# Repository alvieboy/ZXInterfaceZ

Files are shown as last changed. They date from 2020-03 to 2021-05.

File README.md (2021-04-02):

# ZX Interface Z



Interface Z - an expansion card for the ZX Spectrum which supports

- VGA Output
- USB devices such as joysticks, flash drives and keyboards
- Networking and Wifi
- Micro SD Card
- YM2149 audio

_Project status: Currently under development and only suitable for people that want
to help out with development and testing._

Current version is _ALPHA1_.

See [FEATURES](docs/FEATURES.md) for more details on the _ZX Interface Z_ features.
[(click here for PDF document)](docs/FEATURES.md.pdf)

# Overview

Block diagram of Interface Z [diagram](https://raw.githubusercontent.com/alvieboy/ZXInterfaceZ/master/docs/overview2.png)

# Models supported

The following models are supported:

- ZX Spectrum 16K
- ZX Spectrum 48K
- ZX Spectrum 128K (gray)
- ZX Spectrum 128K (toastrack)
- ZX Spectrum +2A
- ZX Spectrum +3

## Hardware
This section refers to the schematics and printed circuit board design of the Interface Z.
The digital design on the FPGA is described in the [FPGA design] section.
### Licensing
Schematics and PCB are released under [CC-BY-SA 2.0](https://creativecommons.org/licenses/by-sa/2.0/). This applies to all versions of the schematics and PCBs.
### Version
Current hardware version is 2.4. This is a pre-production version, not intented for general public availability.

## FPGA design
The FPGA design is written primarly in VHDL, targeting an Altera/Intel Cyclone IV device (EP4CE6E22C8N). There is no flash to store bitfile contents - the FPGA bitfile is loaded by the ESP32 MCU and stored inside the ESP32 flash.

### Licensing
Unless otherwise stated in each HDL or design support file, the FPGA design files are released under [BSD 3-Clause License](https://opensource.org/licenses/BSD-3-Clause).

## Firmware
This section applies to the firmware running on the ESP32 MCU.
### Licensing
Unless otherwise stated in each source support file, the firmware source files are released under [GPL version 3](https://opensource.org/licenses/GPL-3.0) license.

## Software
This section applies to the software intended to run on a separate computer (such as a PC, Mac or other).
### Licensing
Unless otherwise stated in each source support file, the software source files are released under [GPL version 3](https://opensource.org/licenses/GPL-3.0) license.

# Developing

See [DEVELOPING](docs/DEVELOPING.md) for development information regarding _ZX Interface Z_ 
[(click here for PDF document)](docs/DEVELOPING.md.pdf)

See [USER GUIDE](docs/USER_GUIDE.md) for build instructions.

# More information

- Follow the project on [Facebook - ZX Interface Z](https://www.facebook.com/zxinterfacez)
- Watch a [Demo of "Interface Z" for ZX Spectrum](https://www.youtube.com/watch?v=lMPc_8UKx1o) on YouTube

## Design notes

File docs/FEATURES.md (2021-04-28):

# What is ZX Interface Z?

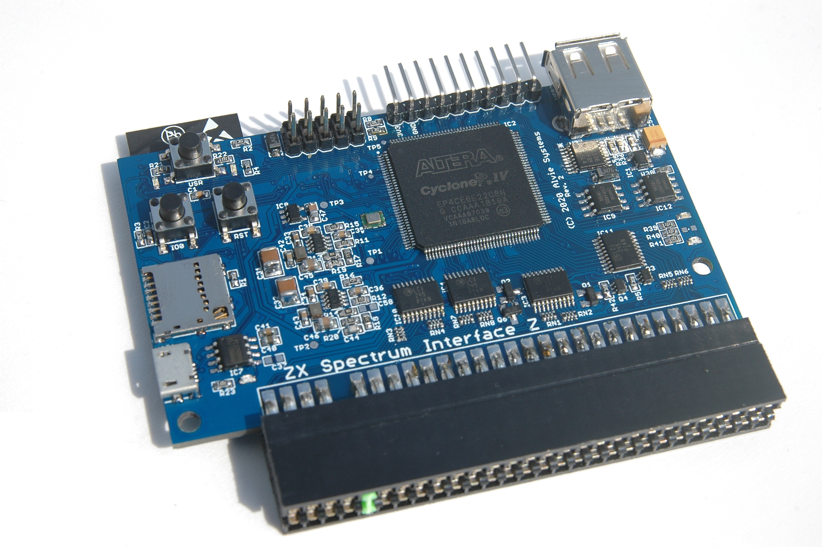
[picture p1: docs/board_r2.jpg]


The _ZX Interface Z_ is an expansion card for the ZX Spectrum which supports, among
other features:

- VGA and audio output via micro expansion card
- USB devices, such as keyboard, gamepads and memory sticks.
- Network access via WiFi
- Micro SD card
- Bluetooth [planned]
- YM2149 sound on all models

Internally, the _ZX Interface Z_ includes:

- A dual-core CPU with WiFi and Bluetooth radio
- An Intel FPGA                                
- 64MB of RAM, also accessible from the ZX Spectrum
- USB for debugging and programming

the _ZX Interface Z_ is __fully open source!__. The software, the board and the FPGA designs are
available online under open source licences so anyone can modify them or build
their own.

## Current version
The current hardware version is 2.4. This hardware is compatible with the
models described in this document.

## Where is the source?

All sources are available in github:

[https://github.com/alvieboy/ZXInterfaceZ](https://github.com/alvieboy/ZXInterfaceZ)

## Supported hardware
The following ZX Spectrum hardware is supported:

- ZX Spectrum 16K
- ZX Spectrum 48K
- ZX Spectrum 128K (gray)
- ZX Spectrum 128K (toastrack)
- ZX Spectrum +2A
- ZX Spectrum +3

Some features might not be available depending on the model. See section 
Hardware Limitations for details regarding support of your ZX Spectrum model.

# The board
The _ZX Interface Z_ board has the following features available for user
interaction and information:

- Two user buttons - USR and IO0
- 6 LEDs (one for power, 5 for information)
- One hard-reset button

The _ZX Interface Z_ also includes one expansion port which can hold other 
boards. The VGA and audio output plug into this expansion port.

The USR button is used to access the _ZX Interface Z_ main menu. The IO0 button
is configurable and can be used for different purposes.

By default, holding the IO0 button for more than one second loads a Diagnostics ROM
which you can use to diagnose your ZX Spectrum hardware.

# Main menu
The main menu is normally accessible by pressing shortly the USR button. Most of 
the _ZX Interface Z_ functionality is accessible using this menu.

From the main menu, you can:

- Load snapshots
- Save snapshots
- Play tapes
- Poke memory
- Change _ZX Interface Z_ settings
- Reset the ZX Spectrum
- Debug the ZX Spectrum [experimental]
- See information about the system

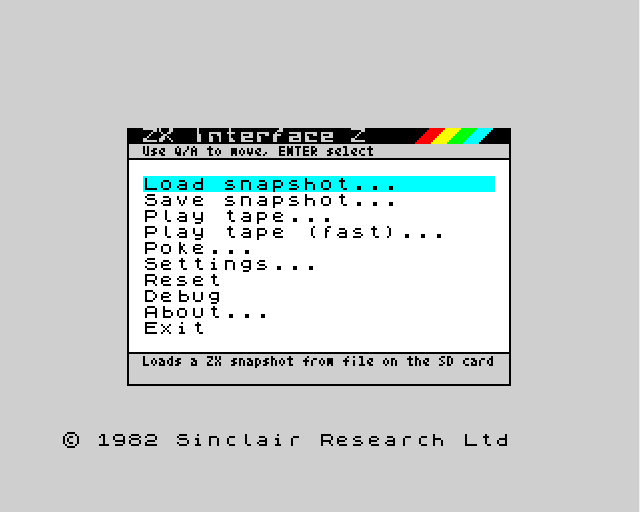
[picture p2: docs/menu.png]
The main menu


# Loading software
It is possible to load a multitude of software using the _ZX Interface Z_. Loading
of software is either done by restoring the ZX Spectrum state, or by using 
tapes.

Loading of software is possible from the following sources:

- microSD card
- USB flash drive 
- USB CDROM [planned]
- Network [planned]

## Loading tape files

The following tape files can be loaded using the _ZX Interface Z_:

- TAP tapes
- TZX tapes

See Tape Loading Methods for details on limitations of each file type and 
ZX Spectrum model.

## Loading snapshot files

Snapshot files can also be loaded by the _ZX Interface Z_. The following snapshot
files are supported:

- SNA [48K only, 128K planned]
- Z80 [experimental]

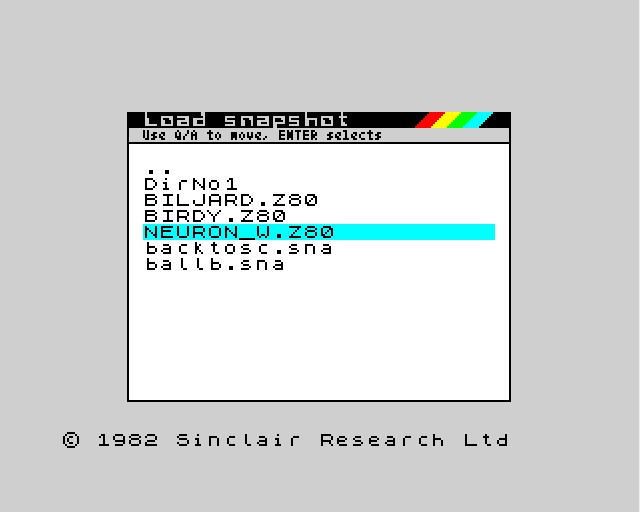
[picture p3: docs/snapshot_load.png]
Loading snapshots


## Tape loading methods

There are two methods for loading tape files. Depending on the tape file and on
the platform it might or might not be possible to load them.

### ROM-hooked LOAD (FastTAP)
This method allows for quick loading of tapes and relies on ROM hooks to perform
loading. The following tapes are supported using this mode:

- Standard TAP and TZX tapes (not using custom loaders, like copy protection
loaders or fast loaders)

### Audio emulation loading
This method allows any tape to be loaded, but is not compatible with all ZX 
Spectrum models. The following tapes are supported using this mode:

- TAP and TZX tapes

See section Hardware Limitations for details regarding support of audio emulation
of your ZX Spectrum model.

# Saving software
It is possible to save software using the _ZX Interface Z_ by either capturing the
ZX Spectrum state (snapshot) or by saving to tape files.

Saving software is possible to the following devices:

- microSD card
- USB flash drive

## Snapshots
It is possible to save a snapshot of the ZX Spectrum to a file. Support for
snapshot might depend on the actual ZX Spectrum used. See section 
Hardware Limitations for details regarding support of snapshots for your 
ZX Spectrum model.

## Automatic load/save menu
The ZX Interface Z comes with a method of automatic load menu. This means whenever
you type in LOAD or SAVE commands in the ZX Spectrum BASIC, or if any program
enters the standard ROM LOAD or SAVE routines, a pop up will show which allows
you to select a TAPE file to load or save. It is possible to append to tape files
as well.

# Pokes
The  _ZX Interface Z_ supports pokes dynamically - all you have to do is to place
POK files in your microCD or USB memory stick and load them using the menu.
If any parameters are needed, the _ZX Interface Z_ will ask your for their
values.

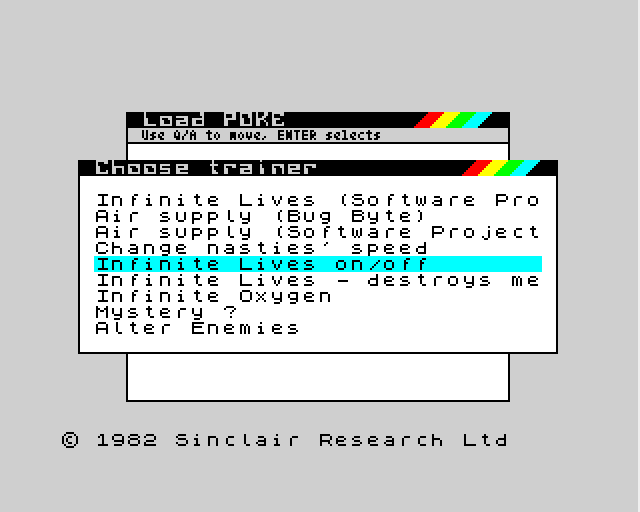
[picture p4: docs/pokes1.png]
The poke menu where you can select the trainer


# Quick snapshot
This feature is still in the planned stage.

It will be possible to map inputs to trigger a quick snapshot, which is quite
useful if you want to immediatly save what is going on in your ZX Spectrum, such
as a particular game you are playing.

See General input device support for more details.

# Audio support
The _ZX Interface Z_ supports audio output using a dedicated expansion card. This
is usually done by the VGA+Audio companion adaptor.

The _ZX Interface Z_ includes an YM2149 sound chip inside the main FPGA, which
can output audio to the Audio adaptor on the expansion port.

The audio output is stereo, and includes a mixer for the internal audio and the
YM2149 three-channel outputs. Each of these can be adjusted in volume and balance
between the left and right channels.

Configuring audio

The audio configuration is persistent, it will be stored and restored next
time you power the _ZX Interface Z_.

# Video support

The _ZX Interface Z_ supports digital video output through the expansion port.
This is often done by plugging the VGA+Audio companion adaptor.

It also supports streaming of the video output via networking, using a custom video 
encoding prototol.

There are a set of different modes available for VGA output, which can be configured
on the settings menu.

The video is generated by capturing the Z80 interaction with the video memory,
so even if your ZX Spectrum lower ram is malfunctioning, the video output will still
work as expected (so diagnostics ROM will work properly).

# General input device support
The _ZX Interface Z_ is very versatile in terms of input support, being it 
joysticks, gamepads, mice and keyboards. These connect through the USB port.

The behaviour of each input device (or, more specifically, each physical entity of
each device) can be mapped to a particular action. For example, it is possible
to configure certain USB keyboard keys to act as a mouse press, or to bring
up the main menu, or to perform a quick snapshot save. Also possible, for example,
is to map a joystick to keys, or a particular gamepad button to mute the audio output.

The following mappings are available for each physical input:

- Keyboard press+release
- Joystick axis movement or button
- Mouse movement or button
- Main Menu
- Quick save/load [planned]

# Wireless Support

The ZX Interface Z supports WiFi in one of two modes. It can act as a standard
WiFi client device (station) connected to a WiFi Access Point, or it can work
in standalone mode, where the ZX Interface Z is itself an Access Point where you
can connect to.

### WiFi modes
- 802.11b/g/n support

### WiFi authentication modes

- WPA2 
- Open (no authentication)

# Settings configuration
You can access the settings configuration on the main menu.

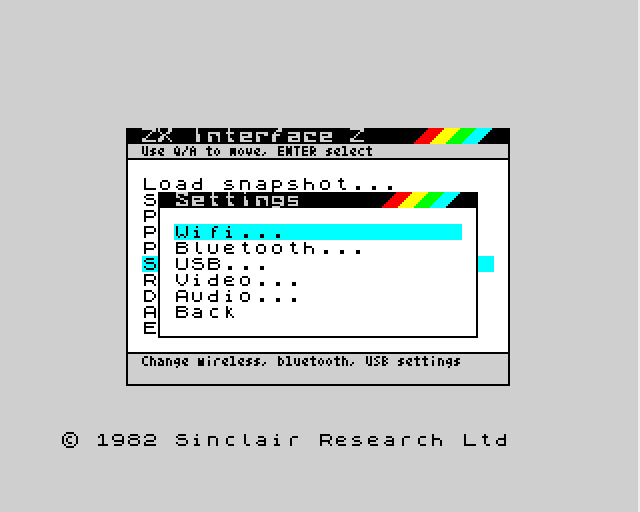
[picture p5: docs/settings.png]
Settings menu


From the settings menu you can configure:

- WiFi 
- Bluetooth [planned]
- USB [experimental]
- Video output settings
- Audio settings

# Networking support
There is full networking support inside the main firmware. A subset of the
networking API is available to the ZX Spectrum via a separate API.

# Firmware upgrade
The ZX Interface Z firmware can be upgraded using one of the following methods:

- Micro USB cable using a dedicated tool
- Over-the-air upgrade [planned]
- Upgrade via USB flash drive [planned]

# The web page
The _ZX Interface Z_ includes a web site which you can use to perform several 
configuration and operations.

The web page is accessible by pointing your browser to http://interfacez.local/.

The web page is under active development, and will likely change heavily during
development phase.

# Hardware considerations

Take this information into account before using the _ZX Interface Z_:

- For all models, the USB port is powered by the ZX Spectrum 5V rail. This
limits the amount of current that can be drawn by the USB port without 
interfering with the ZX Spectrum or lead to overheat of the internal ZX
Spectrum regulator. __DO NOT CONNECT ANY USB DEVICE THAT DRAWS MORE THAN 200mA!!!__ 
This may lead to destruction of the ZX Spectrum regulator. The Interface Z team
cannot be liable for damage of the ZX Spectrum if such a device is connected.
For safety reasons, shorting the USB power lines will temporarly disable the USB port.

- For the ZX Spectrum models powered by +9V supply, the Interface Z power is
drawn directly from the +9V rail.

- For the ZX Spectrum models __not__ powered by +9V supply, the Interface Z power 
is drawn from the +12V rail.

# Hardware limitations
The following platforms might have limitations due to ZX Spectrum hardware design:

## ZX Spectrum 16K

No limitations

## ZX Spectrum 48K

No limitations

## ZX Spectrum 128K (gray)

Snapshots are only possible for 48K mode (128K support is planned)

## ZX Spectrum 128K (toastrack)

Audio emulation for tape loading is not supported

Snapshots are only possible for 48K mode (128K support is planned)

## ZX Spectrum +2A                                  

Audio emulation for tape loading is not supported.

Snapshots are only possible for 48K mode (128K support is planned)

## ZX Spectrum +3
Audio emulation for tape loading is not supported

Snapshots are only possible for 48K mode (128K support is planned)

## Other models
Other ZX Spectrum models, clones and TIMEX models are currenly unsupported.

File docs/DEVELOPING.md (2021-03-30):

# Architecture

The _ZX Interface Z_ is a ZX Spectrum expansion board. It consists on:

- A dual-core CPU with WiFi and Bluetooth radio
- An Intel Cyclone IV FPGA
- 64MB of RAM, also accessible from the ZX Spectrum
- USB for debugging and programming
- USB host to connect USB devices to the ZX Spectrum

Architecture overview

Architecturally, the board is split into several parts:

- Power supplies
- Spectrum interfacing
- Main system CPU
- Main system FPGA
- USB host 
- SDRAM

## Power supplies
The power supplies generate the required voltages for the _ZX Interface Z_ to work. Power is drawn from the
ZX Spectrum main power supply (either 9V or 12V) and from the 5V ZX Spectrum regulator for USB and some interfacing 
logic.

## Spectrum interfacing

Interface with the ZX Spectrum is entirely done through the FPGA design.

### Data lines

Data lines D0-D7 are connected through bi-directional buffers, whose direction is
dictated by the FPGA design.

### Address lines

Address lines A0-A15 are unidirectionally buffered from the ZX Spectrum to the
FPGA.

### /RD, /WR, /MREQ, /IOREQ, /M1, /RFSH, /CK

The main Z80 control lines /RD, /WR, /MREQ, /IOREQ, /M1, /RFSH and /CK are unidirectionally buffered from the ZX Spectrum to the
FPGA.

### /NMI, /RESET

The /NMI and /RESET lines is driven by the FPGA using open-drain outputs. It is not possible to sample the
/NMI or the /RESET line from within the system.

### /INT

The /INT line is sampled by the FPGA and can also be driven by the FPGA using an open-drain output

### /WAIT

The /WAIT line is driven by the FPGA an open-drain output. 

### /IORQULA

The /IORQ ULA disable is driven by the FPGA an open-drain output. The functionality
is only supported in models which have this line.

### /ROMCS, /ROMCS2, /2AROMCS

The /ROMCS, /ROMCS2, /2AROMCS lines are driven by the FPGA open-drain outputs. 
The functionality depends on the ZX Spectrum model.

### /BUSREQ, /BUSACK

The /BUSREQ and /BUSACK are not available on the _ZX Interface Z_

## Main system CPU

The execution core of _ZX Interface Z_ operation is performed by an ESP32 system. The ESP32 platform provides
an execution environment for the software, WiFi and Bluetooth access.
The ESP32 is responsable for:

- Executing the software
- Storing read-only and configuration data
- Programming the FPGA at power up
- Communicating with and receiving events from the FPGA 
- Sampling the buttons
- Driving some of the board LEDs
- Providing programming and debugging support via USB serial connection
- Performing analogue sampling of the power lines
- Providing read-write access to the microSD card
- Adding WiFi and bluetooth support
        
Communication between the ESP32 and the FPGA is done through a dedicated SPI bus and some discrete lines, mostly
used for interrupt control.

There is no direct connection between the ESP32 and the ZX Spectrum. 

## Main system FPGA

The main FPGA is at the heart of all interaction with the ZX Spectrum and all external devices.
The FPGA is responsable for:

- All interaction with the ZX Spectrum
- Providing USB host support
- Capturing and storing video and audio data
- Providing ZX Spectrum devices:
	- Joysticks and mice
	- AY8192 audio implementation
	- ULA "override" - substituting the ULA for certain accesses
- Providing video out capabilities
- Providing audio out capabilities
- Interfacing with the on-board SRAM

## USB host

The USB host function supports USB1.1 Low-Speed and Full-speed.

An UTMI transceiver connects to the USB host controller on the FPGA and to the USB connector proper.

The host controller supports up to 8 simultaneous endpoints, either control, bulk or interrupt. It does not support Isochronous transfers.

## SDRAM

The SDRAM is a quad-SPI SDRAM chip, which is controlled by the FPGA design. 
It runs at 96Mhz clock, and it's 64Mbit (16MByte) in size.
The SDRAM area is logically partitioned according to the purpose.

# How everything glues together

This section will attempt to explain the basics of how everything glues together, and how the system behaves after powering up.

We will look at the following:

- Start up
- The NMI menu
- The standard ROM hooks

## Start up

When the system starts up (is powered, or after reset) the ESP32 firmware starts. It initialises some of the internal subsystems 
such as storage on the on-chip flash (this is implemented using a SPIFFS filesystem, whose contents are generated during
build of the firmare). 

It then loads the FPGA firmware. After the FPGA is ready, a quick test of the external RAM is performed.

Any failure in this sequence will abort further operation and the board LEDs will flash very quickly.

After checking the power supplies for correct voltages, and performing an initial assessment of the
ZX Spectrum model, other subsystems are initialised.

The main _ZX Interface Z_ ROM is then loaded from the internal storage into memory.

The system then attempts to do a better detection of the ZX Spectrum model. The ZX Spectrum is reset and
control is switched to the ZX Interface Z ROM. A quick checksum (partial) of the internal ZX Spectrum ROMs is performed. 
The checksums are then compared to a list of known checksums. This will be used in the future to disable/enable certain
functionalities depending on the ZX Spectrum models.

Once all this is done. the ZX Spectrum is reset to it's internal ROM again, the main ROM hooks are installed and the 
system is ready to run. At this point all of the required ZX Interface Z subsystems are ready and operational.

## The NMI menu

When user presses the NMI (USR) button, this is detected by the button subsystem and we proceed to the sequence required
to show the NMI menu. The sequence is as follows:

- The widgeting system is reset to the NMI menu mode
- The tape players are stopped if they are running
- We request the FPGA to assert the ZX Spectrum /NMI line (which will also include forcing the ROM to the ZX Interface Z ROM).

At this point, nothing else is done on the firmware.

The ZX Spectrum will process the NMI request, and control of the Z80 CPU passes to the ZX Interface Z Spectrum NMI handlerthe ZX Interface Z Spectrum NMI handler routine
in nmihandler.asm.

### The ZX Interface Z Spectrum NMI handler

Upon entry, the NMI handler saves quite a bit of information to the external RAM (see ZX Spectrum ports and operations). This
includes storing all relevant CPU register values, the memory area between Z80 0x4000 and 0x7FFF, the ULA border (as we
last saw it) and some other registers like YM2189 mixer. The YM2189 is silenced.

When all information is stored, a command (CMD_NMIREADY) is sent by the ZX Spectrum via the command FIFO.  
The NMI handler then waits for main firmware commands on it's main loop

When the main firmware receives the NMI_READY command from Spectrum, it starts building up the menus. For this, first the
last framebuffer (which was saved by the NMI handler above) is retrieved to a local framebuffer. All drawing operations
are done first on the ESP32 memory, then the whole framebuffer is sent to the external RAM and the ZX Spectrum is notified.

The main windowiwg system loop will check for events from the ZX Spectrum keyboard, and navigate accordingly.
When all is done, the relevant commands are sent to the ZX Spectrum for execution.

#### The NMI handler main loop

On the ZX Spectrum, the NMI handler main loop performs the following operations:

- Check for a command from the main firmware. If there is such a command, process it.
- Read the keyboard. If any key was pressed or released, send a CMD_KBDINPUT to the main firmware.
- Check the frame counter in the external memory. If frame counter differs from last frame counter, then the
memory area in the external memory from 0x020001 is copied into the ZX Spectrum framebuffer area (at 0x4000), copying both
pixel and attribute areas.

If a command is present, then it is executed:

- 0xff: Leave NMI
- 0xfe: Perform a snapshot of the whole memory
- 0xfd: Load a snapshot
- 0xfc: Execute new temporary program
- 0xfb: Read a chunk of RAM memory into the external RAM
- 0xfa: Read a chunk of ROM memory into the external RAM

# The standard ROM hooks

The _ZX Interface Z_ allows for ROM hooks.

A ROM hook consists of an address or a range of addresses on the ZX Spectrum ROM area that whenever an instruction is
read from these locations for execution causes the current ROM to switch from the ZX Spectrum ROM into the ZX Interface Z
ROM.

This allows the system to "trap" execution of certain ROM routines into our own implementation.

By default, the ZX Interface Z installs two main ROM hooks. One is used for LOAD, and another for SAVE.

Whenever a LOAD or a SAVE is executed the control passes to the ZX Spectrum ROM. The ROM notifies the firmware
using the command FIFO of the operation that was requested, and then invokes the NMI handler.

The main firmware, knowing the operation that was requested, invokes the particular menu for that operation.

# Development for the ZX Interface Z

Development of _ZX Interface Z_ is split into five major parts:

- Physical board (PCB) design
- FPGA design
- ESP32 firmware
- Host simulation software
- ZX Spectrum software (ROM)
- Web interface design

## Physical board (PCB) design

The _ZX Interface Z_ PCB design has been done using EagleCAD 6.x. The main board 
uses a four-layer design. 
The design files can be found in 
[https://github.com/alvieboy/ZXInterfaceZ/tree/master/pcb](https://github.com/alvieboy/ZXInterfaceZ/tree/master/pcb)

The PCB design is considered stable at this point. Changes to the design shall
be driven by issues raised in github and accepted.

A series of blog posts have been
done to explain in detail how the physical hardware design works, which can be consulted here:

[ZX Interface Z - The Hardware, part 1](https://zxinterfacez.blogspot.com/2020/10/zx-interface-z-hardware-part-1.html)

[ZX Interface Z - The Hardware, part 2](https://zxinterfacez.blogspot.com/2020/10/zx-interface-z-hardware-part-2.html)

[ZX Interface Z - The Hardware, part 3](https://zxinterfacez.blogspot.com/2020/12/zx-interface-z-hardware-part-3.html)

## FPGA design

The FPGA design is almost entirely done in VHDL.

See the FPGA architecture document for details.

## ESP32 firmware

The main _ZX Interface Z_ software runs inside an ESP32 chip.

For simplicity, the following subsystems are not described in this document. Refer to the code documentation
for more information about these subsystems:

- ADC
- GPIO
- SPI
- Resources
- Built-In Testing
- HDLC encoding/decoding

### Startup

This section covers the system start up.

When the system starts up (is powered, or after reset) the ESP32 firmware starts. 

All startup is handled inside the main() function. 

The startup performs the following initialisations:

- GPIO, console and ADC are initialized.
- The board is initialised. 
- The ESP32 LEDs are set to the default values 
- The SPI, SDCARD, NVS, WSYS and resource layers are initialised. This includes the internal SPIFFS filesystem.
- The FPGA is programmed from the "intz.bin" present in the SPIFFS and started up
- If FPGA reports BIT mode is requested, BIT mode is entered
- The external RAM is quickly tested
- WiFi is initialized.
- The FPGA firmware is checked for compatibility with the board.
- The interrupt layers is initialised.
- The resources are registered 
- The ZX Interface Z ROM is loaded 
- Other subsystems are initialised:
	- Configuration
	- Spectrum command handler
	- Video streaming
	- Tape players
	- Device mapper
	- Storage
	- USB
	- Web server 
	- VGA
	- Buttons
	- Joystick

After initialization, the spectrum model is further refined by reading the ROM checksums and comparing it to 
a list of known models.

Finally, the ROM hooks are set up.

The main loop is then entered, which:

- Flashes the LED1
- Restarts the ESP if requested by the firmware update procedure
- Reads the MIC idle status and propagates it.
- Handles serial-over-USB data for the console and the waveform capture
- Processes the buttons

The main loop never exits.

### Activity monitor

The activity monitor layer reports activity on the ZX Spectrum MIC line. It is used to time out tape loading and save
when working with physical tapes, so that subsequent loads/saves to the external tape do not bring up the tape load/save menu.

Typically, after 10 seconds of inactivity the physical tape is "logically disconnected" and further load/save operations 
will bring up the load/save menu.

The current mic idle state can be read with the activity_monitor__read_mic_idle() method.

### Board detection

Board detection is intimately linked to the model detection.

In boards preceding the r2.3 version, the system lacked ADC support to read the voltage rails. From r2.3 onwards, the
voltage rail main supply is connected to the ADC and is used by the board and model detection routines.

A few methods in the board layer can be used to query for the board and supply details.

### Model detection

The model detection allows you to understand which ZX Spectrum model is currently hosting the _ZX Interface Z_.

The detecton works at two levels.

The first level is solely based on the board power supply, so it can detect between 9V ZX Spectrums such as the 16K, 48K and
128K gray/toastrack and the +5/+12V spectrums, such as the +2A and +3.

Depending on the model some features might or might not be present.

The most dependant feature is the ULA override (IORQULA) which is not present on +2A or +3, and also not in a few clones
like the Investronica 128K.

The method model__supports_ula_override() will inform you if the ULA override method is supported on the model. If 
the model is not known, it is assumed that it does not support.

Without the ULA override it is not possible to "simulate" a real tape, nor is it possible to inject keyboard presses.

The second level is based on ROM identification. For the ROM identification, a checksum of the two first ROMs is performed
but with 64-byte interval between each input. This allows for a quick computation of the checksum.

The checksum is then checked on a list of known model checkusms in order to find out which particular model we are running on.

### Buttons

The button layer is responsable for scanning the on-board buttons.
It can detect whether a button was pressed, released or long-pressed. Currently the button presses/releases are handled
by the process_buttons() in main.c, and the handling is hardcoded. It is planned to make these buttons configurable in the
future.

### Console

The console layer receives commands from the console (serial-over-USB) and executes them. It's mostly used for debugging purposes.

The console inputs are input into the console layer using console__char() and after a line is received it is processed by
console__parse_string(), which maps the main console command to a hander using a lookup table.

The command handlers receive the command as a tokenized list, much like argc/argv style.

In order to add new console commands, create a handler function inside console.c and register it in the table "command_handlers".

### Debugger

The debugging infrastructure is still under development.

As of the current version, the debugging infrastructure allows the NMI context to be retrieved for examination.
This includes the CPU registers and some other IO registers. Execution code and/or stack contents can be extracted using the memdata subsystem.

The following registers are able to be visualised, and the data corresponds to their value before entering the
NMI handler:

- Z80 registers AF, BC, DE, HL, AF', BC', DE', HL', IX, IY, R, I, SP
- ULA register
- YM2189 mixer register

An execution tracer in hardware is planned, but not yet implemented. This infrastructure will allow the user to see
exactly which instructions have been executed prior to entering the NMI.

### Device Mapper

The purpose of the device mapper is to map device inputs, such as joystick movements, gamepad axis and keys, 
keyboard presses into concrete actions.

When a specific input changes state, the device mapper is notified (usually by hid__field_entry_changed_callback() being called
from the HID layer), the device mapper checks if the device is mapped to any actions, and if true, what particular
action is assigned to that input/field. It then triggers the corresponding action.

Boolean (on/off, such as buttons) and integer fields (such as joystick axis) are supported. The integer fields can be converted
into boolean fields by use of low and high thresholds.

The actions that can be configured on a field input are:

- Trigger NMI menu
- Press/release a keyboard key (only models which support ULA override)
- Move or press a button of the Kempston Joystick
- Move or press a button of the Kempston Mouse

Other actions will be added in the future, such as snapshot saving and screen dump.

All the device mapper configurations are stored internally on the "/config" folder in a "devmap.jsn" file. 
The configurations are stored in JSON format and can be changed in run-time. This folder is not accessible externally.

The following example shows the "devmap.jsn" with two devices. The first device is an USB gamepad,
the second device is the _ZX Interface Z_ Dual Joystick adaptor, with two interfaces:

```json
{
  "devices": [
        { 
                "id": "0e8f:0003",
                "manufacturer": "My gamepad",
                "product": "My gamepad",
                "serial": "01298321732",
                "config": "/config/0e8f0003.jsn"
        },
        {
                "id": "0483:5740",
                "manufacturer": "Alvie Systems",
                "product": "Dual Joystick for ZX Interface Z",
                "serial": "01298321732",
                "configs": {
                        "0": "/config/04835740-0.jsn",
                        "1": "/config/04835740-1.jsn"
                }
        }
  ]
}
```

If the device supports multiple interfaces, then Each of the interfaces should point to another JSON file with the particular configuration for that interface. 
Most devices only support one interface, so only a single config file is required.

On the example above. the gamepad has plenty of buttons and axis. Here is The configuration example for this gamepad:

```json
{
       "entries" : [
                { "map": "nmi", "index": 14, "value": 1 },
                { "map": "keyboard", "index": 15, "value": "enter" },
                { "map": "keyboard", "index": 6, "value": "q" },
                { "map": "keyboard", "index": 7, "value": "a" },
                { "map": "keyboard", "index": 4, "value": "o" },
                { "map": "keyboard", "index": 5, "value": "p" },
                { "map": "keyboard", "index": 12, "value": "o" },
                { "map": "keyboard", "index": 13, "value": "p" },
                { "map": "keyboard", "index": 8, "value": "m" },
                { "map": "keyboard", "index": 2, "threshold": 64, "value": "p" },
                { "map": "keyboard", "index": 2, "threshold": -64, "value": "o" },
                { "map": "keyboard", "index": 3, "threshold": 64, "value": "a" },
                { "map": "keyboard", "index": 3, "threshold": -64, "value": "q" }
        ]
}
```
On this mapping, the index "14" which corresponds to a particular button on the gamepad is configured to trigger the NMI menus.
Most of the other entries are regular buttons which are mapped to other keyboard keys.

The last four entries are special, and correspond to a joystick axis. The axis "2" is the horizontal axis and the axis "3" is the
vertical axis. These axes are known to change between -128 and 127 when the user moves them (they are analog). 
The threshold selected will convert the axis movement from an analogue point of view into a "on/off" boolean value we need.
On this particular example, if axis "2" is greater than 64, then the keyboard "p" key will be pressed (or released if previously
pressed and the axis is no longer greater than 64). If axis "2" is less than -64 (more negative), then the keyboard "o" key will be pressed (or released if previously
pressed and the axis is no longer less (more negative) than -64).

This is the example configuration for the second interface of the Dual Joystick:

```json
{
        "entries" : [
                { "map": "joystick", "index": 0, "threshold": -1, "value": "left" },
                { "map": "joystick", "index": 0, "threshold": 1, "value": "right" },
                { "map": "joystick", "index": 1, "threshold": -1, "value": "up" },
                { "map": "joystick", "index": 1, "threshold": 1, "value": "down" },
                { "map": "joystick", "index": 2, "value": "fire1" },
                { "map": "joystick", "index": 3, "value": "fire2" }
        ]
}
```
This configuration is similar to the previous one, except it will trigger joystick movements, according to the value depicted on 
the JSON file.

The devmap configuration will be done via the ZX Spectrum. All you need is to move the axis/press the buttons ans configure
the action you want.

### Disassembler

The _ZX Interface Z_ contains a disassembler which can convert a sequence of executable bytes into the textual assembly 
representation.

The method disassemble__decode() can be used to disassemble an instruction provided the byte sequence and the program counter. It
can be called sequentially to decode multiple instructions.

### DivMMC compatibility

A minimal layer of DivMMC compatibility is provided at low-level. This should be enabled only for very specific software,
such as ESXDOS.

The DivMMC layer implements the standard DivMMC hooks:

- Instruction accesses between 0x3D00 and 0x3DFF 
- Instruction accesses between 0x1FF8 and 0x1FFF
- Instruction accesses at restart handlers $00, $08 and $38
- Instruction accesses at load routines 0x04C6 and 0x0562

The DivMMC layer must only be activated after disabling the standard _ZX Interface Z_ hooks using rom_hook__disable_defaults() and
after loading a DivMMC-aware ROM.

### ESXDOS

Support for ESXDOS is planned, but currently not fully implemented.

### Slow TAP loading

In certain models it is possible to load TAP and TZX files as if they were regular tapes connected to the EAR input. This
allows for all sort of turbo loaders and copy protection schemes to work as they would using a physical tape.

The system "emulates" the tape by capturing accesses to the ZX Spectrum ULA and modifying the EAR value as it would come
from a real tape. 

Internally the FPGA includes a generic TAP player which is capable of generating the EAR signal from either TAP or TZX file,
an injecting it on the ULA output whenever the CPU requests that data.

Since the _ZX Interface Z_ requires manipulation of the ULA output to the Z80 it requires the IORQULA line to be connected
to the expansion connector of the ZX Spectrum, which is not the case for some models. The method is known to work on the 16K, 48K and
128K (gray) models.

See section [Tape player] for more details.

### Fast tape loading

It is possible to quick/fast load tape files (TAP, TZX and SCR) files by using hooks in the ZX Spectrum ROM.
Only standard tapes (which don't use custom loaders like copy protection schemes or turbo loaders) can be loaded using
this method.

This works by placing a hook at the LD_MARKER routine in the ZX Spectrum. This routine is responsible for starting the load
by detecting the initial sync and then loading the relevant data.

When the Z80 starts executing the LD_MARKER routine, control is transferred to the _ZX Interface Z_ ROM. The load hook in the ROM
uses SPECTCMD_CMD_FASTLOAD and SPECTCMD_CMD_FASTLOAD_DATA commands to request the main firmware to perform the data load. The
main firmware then places the relevant tape content on the external RAM and notifies the _ZX Interface Z_ ROM, which copies
it to the required location and returns to normal ZX Spectrum operation.

### Firmware upgrade

The _ZX Interface Z_ allows the firmware to be upgraded using the following methods:

- microUSB cable with dedicated programmer (python)
- microSD card (in development)
- USB memory stick (in development)
- Network (in development)

### FPGA interaction

Interfacing with the FPGA is done using a dedicated SPI channel between the ESP32 (master) and the FPGA (slave), and interrupt
lines between the FPGA and the ESP32.

All FPGA interfacing is implemented on an API in fpga.c. See documentation present on that file for details of all 
operations supported.

For more details on the SPI protocol refer to the FPGA design document.

### Human Interface Devices

The _ZX Interface Z_ supports Human Interface Devices (HID) which comply to the [USB Device Class Definition for HID](https://www.usb.org/hid).

Upon retrieving the HID descriptors from the device, those are parsed and eventually mapped in the device mapper.

More details on the HID layer can be found in the implementation.

### Joystick handling

The _ZX Interface Z_ can respond to Kempston joystick reads on Z80 port 0x1F. The joystick register is 8-bit wide and is implemented
on the FPGA.

The contents of the joystick register can be set by modifying the REG_KEMPSTON register on the FPGA. To simplify modification
of these values, two methods kempston__set_joystick_raw() and kempston__set_joystick() can be used to change 
the contents of the kempston joystick.

The kempston joystick should work on all platforms.

### Keyboard handling

Keyboard handling (i.e., injecting keyboard presses and releases) on the ZX Spectrum requires ULA override capabilities
on the model. Refer to the model documentation to see if your model supports it.

The keyboard data to be injected is implemented on the FPGA on registers REG_KEYB1_DATA and REG_KEYB2_DATA. Only 40 bits are used
from this mapping. The two registers are merged together to form a 40-bit value, being REG_KEYB1_DATA used as the lower 32-bits (0-31)
and REG_KEYB1_DATA lowermost 8 bits used for the uppermost bits (32-39).

The upper 8 bits of the address line select which part of the 40-bit register is reported. The keyboard bits are reported
on the lower 5-bits of the ULA register read. If more than one bit is "reset" on the upper 8-bits of the address lines, then
the result is undefined.

Address upper 8-bits  Register bits reported
--------------------  ----------------------
11111110              REG_KEYB1_DATA(0 to 4)
11111101              REG_KEYB1_DATA(5 to 9)
11111011              REG_KEYB1_DATA(10 to 14)
11110111              REG_KEYB1_DATA(15 to 19)
11101111              REG_KEYB1_DATA(20 to 24)
11011111              REG_KEYB1_DATA(25 to 29) 
10111111              REG_KEYB2_DATA(30 to 31)
                      REG_KEYB2_DATA(0 to 2)
01111111              REG_KEYB2_DATA(3 to 7)

Injecting keyboard presses is done the following way:

- If the Z80 requests a read from the ULA port, the FPGA will first let the ULA respond, but will interrupt the ULA output just before
the Z80 reads the value from it.
- The original read from the ULA is modified to match the injected key presses based on the contents of the address lines which
map to the keyboard rows (8 in total).
- The FPGA then outputs the "correct" value to Z80, which is captured in the appopriate register.

Keyboard manipulation is normally done using keyboard__press() and keyboard__release() methods. See documentation of those
methods for more details.

### LEDs

A total of 6 LEDs are present on the board, and 5 of them are controllable by the system.

One LED is directly driven by the ESP32 system. The other four LEDs are driven by the FPGA.

Currently the LEDs are allocated as follows:

- The upper-left LED (green) to the left of the USR button flashes during normal operation and serves as an indicator of good operation.
This LED is under control by the ESP32.
- The LED right to the USR button is controlled by FPGA. Its final purpose is still to be defined.
- The three LED block on the lower-right of the board are controlled by FPGA. Their final purpose is still to be defined.

### Reading memory from ZX Spectrum

If the NMI handler is running in the ZX Spectrum it is possible to read memory (either ROM or RAM) from it using 
dedicated funcions.

However, this process is not entirely trivial due to the following aspects:
- The ZX Interface ROM is mapped, so in order to read from original ROM a distinct method must be used
- The RAM area between 0x4000 and 0x6000, as it was before the NMI, is stored in the external RAM, so also a distinct
method must be used.

To help with this, a request analyser is available with memdata__analyse_request(), which will split a single memory area
request into sub-requests that must be executed to fully and coherently read the required area.

This infrastructure is still awaiting improvements.

### Pokes

The _ZX Interface Z_ supports pokes by using POK files.

A POK file contains tipically several trainers. The POK files can be opened using poke__openfile(). 
You can iterate through all trainers by using poke__loadentries(). A particular trainer can be applied
using poke__apply_trainer(). 

The poke subsystem uses callbacks for most of the operations. This avoids reading the full POK content into memory. It
also allows the subsystem to call a function whose purpose is to ask the user for certain parameters required by the POK
trainer. The memory write function is also a callback and can be specialised to the purpose.

### Non-volatile storage

The _ZX Interface Z_ uses two types of non-volatile storage. Both types will ensure that data stored is available upon next
power up or reset.

The special mount "/config" is a SPIFFS filesystem that can be written in run-time. Files stored on this filesystem persist
through resets and power cycles. This filesystem does not require any microSD card nor USB storage.

Asides from the "/config" storage, the _ZX Interface Z_ supports a simple key-value storage called NVS. This can be used to store
basic datatypes as per the following table.

For the data fetch there are two variants of the methods. See implementation for details on the differences between both.

Datatype  Read functions                Write function
--------  ----------------------------  ------------------
uint8_t   nvs__u8/nvs__fetch_u8         nvs__set_u8
uint16_t  nvs__u16/nvs__fetch_u16       nvs__set_u16
uint32_t  nvs__u32/nvs__fetch_u32       nvs__set_u32
float     nvs__float/nvs__fetch_float   nvs__set_float
string    nvs__str/nvs__fetch_str       nvs__set_str

### ROM handling

The _ZX Interface Z_ supports multiple ROM types.
The included ROM for the _ZX Interface Z_ is 8KB in size.

It is possible to additionally load a second ROM size by side with the standard one:

        - 8KB ROM (with additional 64KB RAM paged in 8KB blocks at 0x2000)
	- 16KB ROM
	- 32 KB ROM (16KB + 16KB using 128K page registers)

### ROM hooks

The ROM hooks are places in the ROM area that whenever the Z80 executes instructions from it cause a change in the
current mapped ROM.

This is used to implement custom ROM routines without modifying the on-board ROM contents.

The system supports 8 simultaneous ROM hooks. Each hook can map to a specific ROM slot for the 128K and similar models.

Each hook can either be active or inactive.

#### Ranged option

Each ROM hook can be either ranged or not ranged. 

##### Ranged hooks 

A ranged hook changes control of the ROM whenever an instruction is fetched from the range area. 
The range is specified by a start address and a length field. The ROM mapping is non-persistent, so even if the hook 
is active and an instruction is fetched from outside the range the system will resume normal operation.
This is useful to "patch" small areas of the ROM.

##### Non-ranged hooks

A non-ranged hook will modify the mapped ROM when the instruction at the specified address is fetched by the Z80, and 
the mapping of ROM will persist until a different ROM hook changes it.
This is useful for large code blocks where better control of ROM mapping is required.

#### Pre-Post option

Each hook can switch the mapping of the ROM either before or after the first instruction is fetched.

##### Pre hooks

For pre-hooks, the control of the ROM changes immediatly when the Z80 attempts to fetch the intruction. It can be seen as if the
map changed _prior_ to fetching the instruction

##### Post hooks

For post-hooks, the control of the ROM changes after the Z80 fetches the first instruction, effectively changing the 
mapping when the second instruction is executed.

#### Set/Reset option

Each hook can either set the ROM mapping to the internal ROM, or reset the ROM mapping to the ZX Spectrum ROM.

#### Default hooks

A set of default hooks are installed on power up. All these hooks are non-ranged.

Address Type       Description
------- -------    -----------
0x0767  Pre-Set    LOAD hook. This hook captures execution of the 
                   ZX Spectrum LOAD routine
0x04D7  Pre-Set    SAVE hook. This hook captures execution of the 
                   ZX Spectrum SAVE routine
0x1FFE  Post-Reset Return hook. This location has a RET instruction. 
                   Jumping to this address causes the ROM control to be 
                   switched back to the ZX Spectrum to the address 
                   currently in the stack

In order to override a particular ROM routine, the easiest method is to:

- Create the override routine at the same address in the _ZX Interface Z_ ROM.
- Add a pre-set hook with the relevant address
- On your override routine, when you wish to go back, place the return address in the stack and then jump into the
return hook address. This can be done without modifing any register like in the following example, which will return control to address 0x0123:

```asm
PUSH    HL              ; Save HL temporarly
LD      HL, $0123       ; Load HL with return address
EX      (SP), HL        ; Swap the stack and HL
JP      $1FFE           ; Jump to the switcher routine
```

### Waveform scope

The _ZX Interface Z_ supports (in certain firmwares) a scope which is connected to the Z80 signals and to some other
internal signals.

The scope supports:

- Up to 64 inputs
- Up to 96MHz sample rate.
- Up to 32 configurable triggers
- A total of 1024 samples

The scope is accessible using the microUSB port (serial-over-USB) using a modified version of the sigrok signal analyser.
The Z80 decoder bundled in sigrok can be used to analyse the Z80 lines.

The scope signal types are dynamically loaded from the _ZX Interface Z_, so internal changes in the scope mapping do not
require a modification of the sigrok software.

The scope protocol is based in HDLC streaming, and operates simultaneously to the console, so both cannot be used at same time.

### SCSI device support

SCSI devices are supported at the SCSI command level. 
This is used for USB transport protocol SCSI devices, such as USB flash drives.

There are several layers for the SCSI subsystem.

- SCSI command definitions (scsi.h)
- SCSI device support (scsidev.c)
- SCSI disk IO (scsi_diskio.c)

The USB block device driver uses these layers and the internal FAT filesystem and VFS layers to provide access for 
USB flash drives.

### Snapshots

The _ZX Interface Z_ supports loading and saving snapshots of the current system state.

The follwing snapshot types are supported:

- SNA snapshots (48K)
- Z80 snapshots (48K)

128K snaphshot types are planned.

Restoration of the snapshots is done by a self-modifying routine which is placed in the ROM. The modification of the
ROM values is done using symbol look up tables (see implmentaion in sna_relocs.c for more details).

### Spectrum command handling

The ZX Spectrum command handling is perhaps the most important part of the _ZX Interface Z_.

The Spectrum communicates with the rest of the system using the command FIFO channel. This command FIFO channel is used to transfer
commands and data, and although it's not the only method, it has some advantages over, for example, exchanging information
via the external RAM.

In order to send commands (and some responses) back to the system, the ZX Spectrum performs writes to the command FIFO channel,
which resides in the FPGA and is accessible through ports PORT_CMD_FIFO_STATUS and PORT_CMD_FIFO_DATA.

When the command FIFO channel is not empty, the ESP32 system is notified via an interrupt of such fact, and can then read from the command
FIFO channel and process the data accordingly.

The commands are structured as a stream of bytes, where the first byte is the command ID, and following bytes, which are variable
in size and depend on the command itself. Some commands do not include any more bytes aside from the command ID.

See section [ZX Spectrum commands] for a list of all available commands.

All command handling is performed in spectcmd.c file. 

The command processing from the ESP32 side is as follows:

- Whenever an interrupt notifies us that there is data in the command FIFO channel, the data is placed on a queue and then read from
the command processing task. The data is then appended to a command buffer and the buffer is inspected:

- The first byte (command ID) is analysed and a handler for the command is located in the _spectcmd_handlers_ array. If such
command exists, then the hander is called.
- The command handler analyses the amount of data received so far. If there is not enough data for the command to be 
executed, the handler simply returns. The macro NEED() can be used to simplify the check for "enough data".
- If enough data exists to execute the command, it is executed and the command data is removed from the command buffer using
spectcmd__removedata().

### Interrupt handling

Unlike most systems, the interrupt handling on the _ZX Interface Z_ is done in two phases.

The only source for interrupts is the FPGA, however several subsystems inside the FPGA can trigger interrupts.

The interrupt method is level driven, so whenever the interrupt line from the FPGA is set the interrupt handler is called.

As with all communication with the FPGA, most interrupt enabling and clearing is done via SPI. But an interrupt can come at
any time, and if the SPI channel is busy it cannot be used, so it is not permissible to use the SPI channel from within
the ESP32 interrupt handler. But, if the interrupt is not cleared, then the interrupt routine will be called again once it 
finished execution, leading to an endless interrupt loop.
For this reason, a global interrupt acknowledge line is connected between the FPGA and the ESP32.

The behviour of the interrupt lines is as below.

- At reset, the GIEN (Global Interrupt ENable) of the FPGA is active.
- The FPGA, when a subsystem requests an interrupt, if the GIEN is active it activates the interrupt line to the CPU.
- Upon entering the interrupt handler, the CPU quicky asserts the interrupt acknowledge line to the FPGA and stores an
event on a queue stating that an interrupt was received.
- The FPGA, detecting an interrupt acknowledge, de-asserts the interrupt line and disables GIEN, therefore disabling any
other interrupts.
- An interrupt task in the ESP32 is awken at some point, due to the interrupt queue being not empty. 
It then reads the FPGA interrupt controller registers via SPI to understand which subsystem triggered the interrupt.
- After checking the interrupt source, the corresponding handler is called to perform the relevant tasks. It is the responsability
of this handler to clear the source of the interrupt to prepare for subsequent events.
- When the handler finishes, the ESP32 re-activates the GIEN flag on the FPGA and system resumes the normal operation.

### System events

The system events is a publisher/subscriber insfrasructure used to communicate changes in the environment between different
subsystems. When a publisher sends an event, all subscribers whose filter matches the event will receive it.

Currently there are five subsystems that can publish events:

- WiFi
        - Status change event
        - End-of-scan event
- Network
        - Network status change event
- USB
        - USB device status changed event
        - USB overcurrent event
- Block Device
        - Block device attach event
        - Block device detach event
- Storage
        - Storage attach mountpoint event
        - Storage detach mountpoint event
        
System events can be published with systemevent__send(), systemevent__send_with_ctx() and systemevent__send_event().
All events can have an optional context pointer, which is event dependant.

Any subsystem can subscribe to events. The subsystem needs to provide a handler function 
to be called when events are published. Methods systemevent__register_handler() and systemevent__unregister_handler() can be used
to register and unregister handlers, respectively.

New event types can be registered in systemevent.h . 

### Storage management

The storage management is used to mostly manage the mountpoints as they become available or disappear from the system.

The storage management actively listens for block device events, and preforms mounting and unmounting of filesystems.
It also emits changes in the mountpoints using the [System events] layer.

### General Tape Handling

Tape handling is a complex part of the _ZX Interface Z_. The complexity derives from the multitude of options that
are available for load and save:

- Load/save from a standard tape
- Load from the emulated tape
- Fast Load/save from/to a TAP
- Fast Load/save from/to a TZX

Every load and save consists of multiple blocks (i.e., "PROGRAM" and "BYTES", and respective headers). 
It would be very annyoing if, for every time a block load or block save if requested by the ZX Spectrum, 
we showed user a menu to choose where to load to/save from. 
Even for simple games, this would imply popping up the menu 6 or more times just to perform a simple load.

So, in order to simplify the users life and ensure his sanity, a series of timeouts and checks are done. 
Below, IDLE means that the system had not previously shown any menu to the user (or we entered IDLE on purpose).

- If the system is IDLE, then LOAD/SAVE pops up a menu.
- If the user choose to load or save to/from a standard tape, a 15 second timeout is put in place. If no activity is detected
on the physical tape for this amount of time, the system re-enters IDLE mode. 
- If the user is loading from an emulated tape, once the emulated tape finishes playing the system re-enters IDLE mode.
- If the user is saving to a emulated tape, then after every saved block a timeout of 4 seconds is used. If no more save requests
are made during this timeout, the system re-enters IDLE mode.

### Tape player

The tape player resides mostly on the FPGA, and is controlled by the firmware. It consists of a FIFO channel between the ESP32
and the FPGA and a waveform generator on the FPGA. This waveform can then be injected on the ULA register requests.

Two players are implemented in the firmware, one for TAP files and another for TZX files, These implemetations interpret
the file contents and send data to the FPGA plater to generate the waveforms.

The FPGA player accepts commands and data using the FIFO channel. 

Despite having a single FIFO channel, the FIFO channel accepts commands and data separately.

The FPGA player can generate data pulses, sync pulses and gaps. The T-States associated with those are fully configurable
and can even change during a simple block play.

The implemented commands are as follows. The example values given are for a standard TAP file. Note that due to small clock
differences between the Z80 T-states and the FPGA T-states, a method is provided ( tapeplayer__compute_tstate_delay() ) to
adjust these values prior to configuring the FPGA player.

- TAP_INTERNALCMD_SET_LOGIC0 (0x80)
	- Set the logic "0" pulse width. For TAP, this is 855 T-States.

- TAP_INTERNALCMD_SET_LOGIC1 (0x81)
	- Set the logic "0" pulse width. For TAP, this is 1710 T-States.

- TAP_INTERNALCMD_GAP (0x82)
	- Play a GAP 

- TAP_INTERNALCMD_SET_DATALEN0/1 (0x83/0x84) 
	- Set the data length for the following block (i.e., number of bytes that are to be sent). The higher 
          part of this datalen represents the number of bits not used on last data byte.

- TAP_INTERNALCMD_SET_REPEAT (0x85)
	- Repeat the next comand for the specified number of loops

- TAP_INTERNALCMD_PLAY_PULSE (0x86)
	- Play pulse of specified length

- TAP_INTERNALCMD_FLUSH (0x87)
	- Flush contents of the tape.

As a reference, this is how a TAP header player would behave. The following commands/data sequence would play a standard
header to the ZX Spectrum (17 bytes):

- SET_LOGIC0 855  /* Pulse "0" width */
- SET_LOGIC1 1710 /* Pulse "1" width */
- SET_DATALEN0 0x0017  /* 17 bytes */
- SET_DATALEN1 0x0000  /* No unused bits in last byte */
- SET_REPEAT 8063 /* Number of pilot repetitions */
- PLAY_PULSE 2168 /* play 8063 pulses of 2168 T-states each */
- SET_REPEAT 0 /* No more repeats */
- PLAY_PULSE 667 /* First sync */
- PLAY_PULSE 735 /* Second sync */
- Load 17 bytes data into the FIFO channel

### USB

USB is perhaps one of the most complex parts of the whole _ZX Interface Z_ design. This is mostly because the main CPU, an
ESP32, does not include any type of USB controller. A USB host controller was developed specifically for this project and 
is implemented on the FPGA. See the FPGA architecture document for more details about the implementation.

The USB host controller allows communication betweem the ESP32 and USB devices present on the USB bus. The devices can either
be connected directly or through a compliant USB HUB (the HUB is itself an USB device).

The USB subsystem is organized in a layered scheme.

At the lowemost level, we have the physical USB controller on the FPGA. The controller has 8 channels, which can 
be configured independently to perform transactions to a specific endpoint of an USB device.

Communication with the physical USB host controller is done via the USB Low Level driver. The low level driver
is responsable for handling USB interrupts, configuring channels, submitting transaction requests and transferring data
to and from devices.

On top of the USB Low Level layer we have the USB Host layer. The USB host layer creates a logical separation from the USB
Low Level and the rest of the firmware, implementing two tasks which are responsable for processing data requests.

On top of the USB Host layer we have the device drivers. The device drivers use the USB Host API to communicate with the USB
devices, and use the global API to interface with the system.

At this point there is no direct connection between the ZX Spectrum and the USB layers, except using the drivers indirectly.

#### The Low-level layer

The low level layer is responsable for allocating channels. Prior to any communication a channel needs to be set up
for the respective endpoint. See usb_ll__alloc_channel() for details.

#### USB device driver

All USB device drivers need to implement the USB device driver API. The driver API is very simple, and consists of the following
methods:

- probe
	- Probe for support for a recently attached device interface
- disconnect
	- Handle disconnection of a device

Upon probing the device, and if the device interface is supported by the driver, the driver shall claim the interface
for itself.

#### USB Hub

At a physical level, every USB device is connected to an USB HUB. Internally the USB connector behaves similarly to a HUB with
a single port - this is called the root HUB, and it's implemented in the USB Host interface.

For regular USBHUBs, there are two drivers. One deals with the USB HUB as a HUB device, the 
other implements the USB HUB logical layer.

#### USB tranfer types

The USB layers supports several type of transfers and requests. These requests can target control, bulk and interrupt
endpoints.

##### Control requests

Control requests target special control endpoints. All USB devices implenent a control endpoint at endpoint 0. 

##### Bulk requests

Bulk requests info TODO

##### Interrupt 

Interrupt requests are asynchronous, and handled by the low-level layers. 
More info on interrupt requests here TODO

#### USB transfers

Control and bulk requests use a pseudo-synchronous interface, meaning that although all processing is asynchronous by nature,
the user interface behaves like a synchronous interface.

Being synchronous means that, whenever a request is placed for completion, the user can wait for it to complete by using one
of the completion functions. Additionally the user can set a timeout for the operation to complete.

The main entry point for the USB api is the usbh__submit_request() method.

This method requires the user to fill in a request which is then send to the lower layers for processing. Upon issuing the
request, the user can wait for it to complete by using the usbh__wait_completion() method.

The request consist on a structure that should live until the request is finished. In case usbh__wait_completion() is to
be called on the same function (or a child) it can reside on the stack.

The following members of the request must be initialised before sending out the request:

- device
	- The device which will receive the request
- target 
	- Target memory area for reads and writes.
- length
	- Length, in bytes, of the request. For reads it represents the maximum number of bytes
	that can be received.
- rptr 
	- Read/write pointer. Should be the same as target;
- size_transferred 
	- Transferred size. Should be initialised to zero.
- direction 
	- Direction for this request, Either REQ_DEVICE_TO_HOST or REQ_HOST_TO_DEVICE.
- control 
	- Control flag. Set to '1' if this is a control request.
- retries 
	- Number of retries to use for OUT transactions.
- channel 
	- Low-level channel to use. Must be allocated first with usb_ll__alloc_channel()

##### Control halpers

For control endpoints, a few helper functions exist to simplify the user code:

- usbh__control_msg()
	- Submits a control request and waits for completion
- usbh__get_descriptor()
	- Fetches a descriptor from the device on the endpoint 0

### Versioning

The firmware version as well as the ROM version and FPGA version are available for inspection. It is also possible
to query the ZX Spectrum model version.

See details in "version.h" for how to extract the versions from the system.

### VGA generation

The _ZX Interface Z_ includes a VGA generator which supports multiple output modes.

The VGA generation is performed entirely on the FPGA. It is generated from a copy of the ZX Spectrum framebuffer
that you usually see between 0x4000 and 0x5AFF. In order to understand what are the contents of the screen all
memory transations on the Z80 bus are inspected, and whenever a write is detected, the same write is performed 
on the framebuffer copy inside the FPGA.

The VGA modes are generated from a base clock of either 46.5Mhz or 28.24Mhz. These frequencies are internally generated
by the FPGA PLL. There are plans to use a second dedicated PLL for the VGA which would allow even more modes to 
be produced.

The following modes are available. The repeat column depicts how many VGA pixels are used for a single ZX Spectrum pixel.
The H-border and V-border are the number of VGA pixels used for the border itself.

As of now, the standard PAL mode is not available.

VGA resolution Aspect Repeat H-border V-border
-------------- ------ ------ -------- --------
800x600        4:3    3x     16 pix   12 pix
720x400        16:9   2x     95 pix   8 pix
800x600        4:3    2x     114 pix  108 pix
1024x576 (*)   16:9   2z     256 pix  96 pix

(*) This mode might not be available to use from within the firmware.

### Video streamer

The _ZX Interface Z_ has a video streamer which sends out the ZX Spectrum framebuffer contents every two frames (25Hz).

The streaming uses a custom payload format and it's sent via UDP packets. The video data is sent out using small fragments
which can then be reassembled to display the full image.

### Web server

The internal web server is used to provide the web page experience (see [Web Page design]), and to implement a REST
interface.

The default port for the web server 80 for the standard buid, and 8000 for the [Host simulation software].

### WiFi

The WiFi support is a core feature of the _ZX Interface Z_. 

The WiFi layer emits some system events which can be captured by the rest of the firmware:

- SYSTEMEVENT_WIFI_STATUS_CHANGED
	- Emitted when the WiFi status has changed (connected, disconnected)
- SYSTEMEVENT_NETWORK_STATUS_CHANGED
	- Emitted when the network (TCP/IP) status has changed.
- SYSTEMEVENT_WIFI_SCAN_COMPLETED
	- Emitted when a scan request has successfully completed a network scan

### Windowing System bridge

The WSYS bridge links the windowing layer to the rest of the system. It is responsable for dispatching events and implementing
the main windowing task. It performs also the bridgding between the "C" and and the "C++" parts of the system.

## Host simulation software

The main firmware is able (to some extent) to be build on a Linux host, using QtSpecem as the ZX Spectrum emulator. The
emulator has been slightly modified to acommodate the specific of the _ZX Interface Z_.

## ZX Spectrum software

## ZX Spectrum operations

### Command FIFO

The command FIFO is an unidirectional FIFO channel between the ZX Spectrum (sender) and the ZX Interface Z (receiver). When data
is written to the command FIFO, the FPGA signals the ESP32 through an interrupt that data is available to be read.

The ZX Spectrum software shall read the PORT_CMD_FIFO_STATUS first to ensure that it can write data to the FIFO.
If the FIFO is not full, when data should be written to the PORT_CMD_FIFO_DATA.

### Resource FIFO

The resource FIFO is an unidirectional FIFO channel between the ZX Interface Z (sender) and the ZX Spectrum (receiver). The ZX
Spectrum software can check for data on the resource FIFO by reading the PORT_RESOURCE_FIFO_STATUS. If data is present,
it can be retrieved using the PORT_RESOURCE_FIFO_DATA.

### External memory

The external memory is accessible to the ZX Spectrum using IO operations.

In order to access the memory, either read or writes, the memory pointer must be set up first.

The memory pointer is a 24-bit value which represents the external memory address. After every read or write to the 
external memory this pointer is incremented.

In order to set up the pointer, the ZX Spectrum software must write to the PORT_RAM_ADDR_0, PORT_RAM_ADDR_1 and 
PORT_RAM_ADDR_2 the value it requires. PORT_RAM_ADDR_0 represent the lower 8-bits, PORT_RAM_ADDR_1 the middle 8-bits and
PORT_RAM_ADDR_2 the high 8-bits.
The data can then be read or written using the PORT_RAM_DATA port.

As an example, if the software wants to write 0xAA to the external RAM at address 0x55DEAD, then the following sequence should
be observed:

- Write 0x55 to PORT_RAM_ADDR_2 port
- Write 0xDE to PORT_RAM_ADDR_1 port
- Write 0xAD to PORT_RAM_ADDR_0 port
- Write 0xAA to PORT_RAM_DATA port

If more bytes are to be read or written sequentially, then there is no need to update the pointer since it increments
automatically. For example, in order to write the sequence 0x01, 0x02, 0x03 to the external RAM starting at address 0x55DEAD,
then the following sequence should be observed:

- Write 0x55 to PORT_RAM_ADDR_2 port
- Write 0xDE to PORT_RAM_ADDR_1 port
- Write 0xAD to PORT_RAM_ADDR_0 port
- Write 0x01 to PORT_RAM_DATA port
- Write 0x02 to PORT_RAM_DATA port
- Write 0x03 to PORT_RAM_DATA port

## File API

The file API is accessed through the command FIFO. Status responses to the File API should be extracted from the
resource FIFO.

The functions implemented by the File API are:

- getcwd
- chdir
- open
- close
- read
- write
- opendir
- readdir
- closedir
- ioctl
- fcntl

## Networking

Networking is avaliable to the ZX Spectrum on a first instance using a mix of command FIFO and resource FIFO reads
and writes.

The API is still subject to change.

The networking API is split in two parts. The first part is the low-level API which deal with sockets.
The second part is networking utilities, which deal with other upper layer protocols.

### Low level networking

The common POSIX API can be used to read and write from network sockets, as if they were files.

The functions implemented by the low-level networking API are:

- gethostbyname
- gethostbyaddr
- socket
- connect
- sendto
- recvfrom

### High level networking

The high level networking API provides easy-to-use functions for a set of high level protocols.

The functions implemented by the high-level networking API are:

- wget

## ZX Spectrum ports

The interface ports are partially decoded, and only the lower 8 bits of the address are used.

### PORT_SCRATCH0 (R/W)

This port resides at 0x23. It can be used by ZX Spectrum to store and retrieve data temporarly.

### PORT_MISCCTRL (R/W)

This port resides at 0x27. It is used for miscelaneous control of the NMI routine.

### PORT_CMD_FIFO_STATUS (R)

This port resides at 0x2B, and it's read-only. 

When this port is read by the ZX Spectrum it returns the command FIFO status. The command FIFO
is an unidirectional FIFO between the ZX Spectrum (sender) and the ZX Interface Z (receiver)

If the returned value is zero, this indicates that the command FIFO can accept new data. If not zero, then the command FIFO is busy
and data written to it will probably be lost.

### PORT_CMD_FIFO_DATA (W)

This port resides at 0x67 and it's write-only.

When the ZX Spectrum writes to this port, the data will be stored in the command FIFO. The user is responsable for
checking that the FIFO is ready before writing new data to it.

### PORT_RESOURCE_FIFO_STATUS (R)

This port resides at 0x2F, and it's read-only. 

When this port is read by the ZX Spectrum it returns the resource FIFO status. The resource FIFO
is an unidirectional FIFO between the ZX Interface Z (sender) and the ZX Spectrum (receiver)

If the returned value is zero, this indicates that the resource FIFO has data. 

If not zero, then the resource FIFO is empty.

### PORT_RESOURCE_FIFO_DATA (R)

This port resides at 0x33, and it's read-only. 

When the ZX Spectrum reads from this port, it will return data stored in the resource FIFO. The user is responsable for
checking that the FIFO has data before reading anything from it.

### PORT_RAM_ADDR_0 (W)

This port resides at 0x37 and it's write-only.
Lower byte for the external RAM pointer.

### PORT_RAM_ADDR_1 (W)

This port resides at 0x3B and it's write-only.

Middle byte for the external RAM pointer.

### PORT_RAM_ADDR_2 (W)

This port resides at 0x3F and it's write-only.

Higher byte for the external RAM pointer.

### PORT_RAM_DATA (RW)

This port resides at 0x63 and it's read-write.

Writing to this port will cause the data to be written to external memory.
Reading from this port will return data read from the external memory.

The address used for the external memory is the one set using PORT_RAM_ADDR_0, PORT_RAM_ADDR_1 and PORT_RAM_ADDR_2.

After a read or write, the address is incremented. Successive reads/writes to this port will perform 
sequencial read/writes to the external RAM.

### PORT_MEMSEL (R/W)

This port resides at 0x6b and it's write-only.

Controls the memory page selection of the area between 0x2000 and 0x3FFF.
Only the lowermost 3 bits are used. 

### PORT_NMIREASON (R/W)

This port resides at 0x6f and it's read-write
Used to understand why NMI mode has been entered. Currently not used.

### PORT_DEBUG (W)

This port resides at 0x7F and it's write-only.

This port is used in host-mode only. Writing to this port will cause the value to be output at the console.
This is useful for debugging purposes.

## ZX Spectrum commands

Some commands are deprecated and thus not listed here.
In order to send a command, the command ID should be sent first to the PORT_CMD_FIFO_DATA,
then the required command arguments shall folow in the format described for each of the commands.

### SPECTCMD_CMD_KBDDATA (0x0E)

Send keyboard data to the main system. The arguments to the command are:

- Key data (2 bytes)
	- 2 bytes of data, corresponding to the modifier key first, and the main key after. A value of 0xFF on each represents a key release.

### SPECTCMD_CMD_NMIREADY (0x0F)

Notify system that we successfully entered the NMI handler.

This command has no arguments.

### SPECTCMD_CMD_LEAVENMI (0x10)

Notify system that we are about to exit the NMI handler.

This command has no arguments.

### SPECTCMD_CMD_DETECTSPECTRUM (0x11)

Notify system of the spectrum model.

This command is used at startup, and should not be used elsewhere.

### SPECTCMD_CMD_FASTLOAD (0x12)

Notify system that we entered the FAST load routine.

This command has no arguments.
This command is pending deprecation.

### SPECTCMD_CMD_FASTLOAD_DATA (0x13)

Request fast load data from the spectrum.

The arguments for this command are:

- Block type (1 byte)
	- Represents the spectrum block type
- Block size (2 bytes)
	- 2 bytes, in little-endian format, which depict the size of the block we want to load

The return of this command is placed in the external memory area at address 0x028000. The memory location should
be cleared to zero before calling the command.
Once the load is complete, a value of 0x01 will be placed at this address. In case of error, a value of 0xff will be
placed instead.

### SPECTCMD_CMD_ROMCRC (0x15)

Report ROM block for checksum/CRC processing

This command is used at startup, and should not be used elsewhere.

### SPECTCMD_CMD_LOADTRAP (0x16)

Notify system we have entered the LOAD trap

### SPECTCMD_CMD_SAVETRAP (0x17)

Notify system we have entered the SAVE trap

The arguments for this command are:

- Block size (2 bytes)
	- 2 bytes, in little-endian format, which depict the size of the block we want to save
- Block type (1 byte)
	- Represents the spectrum block type
- Header data
	- 17 bytes of header data, if block being saved is a header

In case a header file is being saved, the header contents (the full 17 bytes) shall be placed in the FIFO, but 
for other blocks this must be ommited.

The Spectrum shall wait for a response byte in the resource FIFO.

If the response is not 0xFF, then the Spectum shall enter the NMI menu handler.

A second status byte should be fetch from the resource FIFO. If this byte is 0xff, then the save data was cancelled. If the
byte was zero, then the save can proceed, and 

Once the save is complete, 

### SPECTCMD_CMD_SAVEDATA (0x18)

Request save data from the spectrum.

Prior to sending this command, the data to be saved shall be placed in the external RAM at address 0x280000. 
The first byte in the external RAM shall be the block type.

The arguments for this command are:

- Block size (2 bytes)
	- 2 bytes, in little-endian format, which depict the size of the block we want to save

### SPECTCMD_CMD_GETCWD   (0x20)

TBD 

### SPECTCMD_CMD_CHDIR    (0x21)

TBD 

### SPECTCMD_CMD_OPEN     (0x22)

TBD 

### SPECTCMD_CMD_CLOSE    (0x23)

TBD 

### SPECTCMD_CMD_READ     (0x24)

TBD 

### SPECTCMD_CMD_WRITE    (0x25)

TBD 

### SPECTCMD_CMD_OPENDIR  (0x26)

TBD 

### SPECTCMD_CMD_READDIR  (0x27)

TBD 

### SPECTCMD_CMD_CLOSEDIR (0x28)

TBD 

### SPECTCMD_CMD_SOCKET         (0x29)

TBD 

### SPECTCMD_CMD_CONNECT        (0x2A)

TBD 

### SPECTCMD_CMD_SENDTO         (0x2B)

TBD 

### SPECTCMD_CMD_RECVFROM       (0x2C)

TBD 

### SPECTCMD_CMD_GETHOSTBYNAME  (0x2D)

TBD 

### SPECTCMD_CMD_GETHOSTBYADDR  (0x2E)

TBD 

###  SPECTCMD_CMD_WGET           (0x2F)

## Web interface design

# Acknowledgements

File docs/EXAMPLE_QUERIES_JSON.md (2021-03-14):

# Misc operations
## Get Version
### Request
```http
GET /req/version
```

### Response

```json
{
  "success": "true",
  "esp_chip": "ESP32",
  "esp_version": "0.1",
  "esp_revision": 4,
  "esp_cores": 2,
  "esp_flash": "Unknown",
  "software_version": "v1.0 2020/03/30",
  "fpga_version": "a5.10 r3",
  "git_version": "TAG_V01-286-g461b41e-dirty",
  "build_date": "Tue 11 Aug 09:38:31 UTC 2020"
}
```
# SD card operation
## List files
### Request
```http
GET /req/list?path=pathrelativetosdroot
```
Argument _path_ should be relative to the SD card root.
## Response
```json
{
  "path":  "/",
  "success":  true,
        "error": "errorstring in case of error",
  "entries":  [{
      "type":  "file",
      "name":  "README.md",
      "size":  33
    }, {
      "type":  "dir",
      "name":  "DirNo1"
    }]
}
```
## Delete file
### Request
```http
GET /req/delete?path=pathrelativetosdroot/filename.ext
```

### Response
```json
{
  "path" : "pathrelativetosdroot/filename.ext",
  "success": "true",
  "error": "errorstring in case of error"
}
```

## Rename/move file
### Request (rename)
```http
GET /req/rename?path=pathrelativetosdroot/filename.ext&newpath=newfilename.ext
```
### Request (move)
```http
GET /req/rename?path=pathrelativetosdroot/filename.ext&newpath=pathrelativetosdroot/newfilename.ext
````
### Response
```json
{
  "path" : "pathrelativetosdroot/newfilename.ext",
  "success":  "true",
  "error": "errorstring in case of error"
}
```

## Create directory
### Request
```http
GET /req/mkdir?path=pathrelativetosdroot/newdir
```
### Response
```json
{
  "path" : "pathrelativetosdroot/newdir",
  "success": "true",
  "error": "errorstring in case of error"
}
```

## Delete directory
### Request
```
GET /req/rmdir?path=pathrelativetosdroot/newdir
```
### Response
```json
{
  "path" : "pathrelativetosdroot/newdir",
  "success": "true",
  "error": "errorstring in case of error"
}
```

## Upload file
### Request
```http
POST /upload?path=pathrelativetosdroot/filename.ext
```

### Response
_note that filename might differ due to size limitations_
```json
{
  "success":  "true",
  "error": "errorstring in case of error",
  "path" : "pathrelativetosdroot/filename.ext",
  "size" : "filesizebytes",
}
```

## Upload file data
### Request
```http
POST /upload/fileupload?token=sometokenhere
```
The token should be obtained first by calling [Upload file] request
### Response
```json
{
  "success":  "true",
  "error": "errorstring in case of error"
}
```
# Device configuration
The following operations allow one to configure USB/Bluetooth devices.

## List devices
List all configured and unconfigured devices
### Request
```http
GET /req/devlist
```
### Response

```json
{
  "devices": [
  	{ "bus" : "usb",
          "driver": "usb_mouse",
          "id": "0adf:2342", 
          "vendor": "Vendor name here",
          "product": "Product name here",
          "serial" : "Serial here",
          "class": "mouse,pointer",
          "connected": "true",
          "use": "mouse"
        }
  ]
}
```
"class" is a list of supported classes/uses for this device.
"use" is the current use (configuration) for the device, or null if not configured.

## Get configuraion
### Request
```http
GET /req/devconf?usbid=0adf:2342?serial=xpto
```
### Response
```json
{
	"bus": "usb",
	"id": "0adf:2342",
        "serial": "Serial here",
        "use" : "mouse", 
        "controls" : [
        ]
        "mappings" : {
        	"default" : [
                       { "index" : 0,
                         "map": "keyboard", 
                         "value", "enter"
                       },
                       { "index" : 1,
                         "map": "keyboard",
                         "threshold": -128
                         "value": "q"
                       }
                ]
        }
}
```

## Configure input
```http
POST /req/devconf
```
POST contents:
```json
{
	"bus": "usb",
	"id": "0adf:2342",
        "serial": "Serial here",
        "use" : "mouse", 
        "mapping": "default",

}
```

# WiFi operations
## Get configuration
### Request
```http
GET /req/wifi
```
### Response

```json
{
  "mode" : "ap", 
  "sta": {
   	"ssid": "ssid",
        "hostname": "interfacez", 
        "ip": "dhcp", 
        "netmask": "255.255.255.0", 
        "gw": "127.0.0.1", 
  },
  "ap" : {
   	"ssid": "ssid",
        "hostname": "interfacez",
        "channel": 1,
        "ip" : "127.0.0.1",
        "netmask" : "255.255.255.0",
        "gw" : "127.0.0.1"
  }
}
```
## Start scan
### Request
```http
GET /req/startscan
```
### Response

```json
{
  "success": "true",
  "error": "errorstring in case of error"
}
```
## Get scan
### Request
```http
GET /req/scan
```
### Response

```json
{
  "success": "true",
  "error": "errorstring in case of error",
  "aplist" : [
  {
  	"ssid": "ssid",
        "channel": 4,
        "auth": 3 
  }
  ]
}
```
For *auth* values see ESP32 *wifi_auth_mode_t*.

POST /req/wifi

WiFi Disabled:
	"mode": "disabled"

WiFi as access point (dhcp server implicit):
	"mode": "ap",
        "ip": "x.x.x.x",
        "netmask": "x.x.x.x",
        "ssid": "theapssid",
        "password": "theappassword".
        "channel": "8"

WiFi station (dhcp):
	"mode": "sta",
        "inet": "dhcp",
        "ssid": "theapssid",
        "password": "theappassword_or_empty"

WiFi station (static IP):
	"mode": "sta",
        "inet": "static",
        "ip": "x.x.x.x",
        "netmask": "x.x.x.x",
        "gw": "x.x.x.x",
        "ssid": "theapssid",
        "password": "theappassword_or_empty"

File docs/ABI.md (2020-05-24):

# Project of ABI for Z-Interface

It's only proporsal for ABI. 

## ABI calls

There some options to make call to ABI.

We may use RST #8 error handler(like in esxDOS) and reimplement some parts of
API. We can use any place of ZX-Spectrum's rom that contains RET code(C9 byte).

For example, we use esxDOS-like aproach and our call will looks like:

```
	LD <REGS>,<PARAMS>
	RST #8
	DB <call number>
```

If we use any place of ROM - we can do something like this:

``` 
IZ_ENTRY  EQU #52

	LD IX, <CALL NUMBER>
	LD A, ....
	LD BC, ....
	CALL IZ_ENTRY
```

To detect IZ ABI we may make easiest test - get version call.

For example:

``` 
GET_VERSION             EQU #0
GET_API_VERSION     	EQU #0
GET_FEATURES	        EQU #1

	LD IX, GET_VERSION
	XOR A ; Same as LD A, GET_DOS_API_VERSION. Any ABI version should be bigger than 0 :)
	CALL IZ_ENTRY         ; A returns ABI version, if there isn't Interface Z - register A will contains zero still
	AND A
	JP Z, izNotFound
```

## DOS ABI

For making application there some minimal set of ABI calls:

### fopen(for example #10)

Arguments:

 * HL - path to StringZ that contains filename(relative/absolute path acceptable both)
 
 * B - file open mode - bitmask can be combined. 1 - Read, 2 - Write, 4 - Create

Returns:

If no error:

 * A - file number
 
 * Flag C is down 

If error happens

 * A - error code
 
 * Flag C setted 

Example:

```
FOPEN_ABI EQU #10
FILE_MODE_READ   EQU 1
FILE_MODE_WRITE  EQU 2
FILE_MODE_CREATE EQU 3

	LD IX, FOPEN_ABI
	LD B, FILE_MODE_READ
	LD HL, file_path
	CALL IZ_ENTRY
	JP C, file_open_error
	ld (fp), a
	.....

file_path db "test.scr"
fp 	  db 0
```

### fclose(#11)

Just closes opened file

Arguments:
 
 * A - file number

Returns:
 
 * If no error - flag C is down.
 
 * If there error - flag C is setted and A contains error code

### fread(#12)

Read some bytes to buffer from file

Arguments:
 
 * A - file pointer
 
 * BC - maximum count of bytes to read
 
 * HL - buffer 

Result:

If success:

 * Flag C is down

 * BC - actually read bytes count

 * Bytes in buffer pointed by HL

If error happens:

 * Flag C is setted 

 * A - error code

### fwrite(#13)

Same as fread but writes buffer to disk

### fseek(#14)

Set offset in opened file(or get offset - if you but zero into offset)

Offset modes:

 * 0 - from begin of file

 * 1 - from end of file

 * 2 - from current position 

Arguments:

 * A - file pointer

 * DEBC - offset

 * L - mode

Result:

 * Error info in flag C and register A(similar like in prev. calls)

 * DEBC - current file position from
 
### readdir(#15)

Read current directory listing.

Arguments:

 * A - limit

 * BC - offset(per file)

 * HL - Buffer

 * E - ordering(Do we really need it?)

Result:

 * Error info in flag C and register A(similar as before)

 * BC - returned files count

 * Filenames written to buffer(11 bytes per file without padding if we using 8+3. If we support LFN - maximum 64 bytes file name len, every file name is StingZ)

### Current Working Directory(#16)

Returns working directory.

Arguments:

 * HL - buffer

Return:

 * Error info in flag C and register A(similar as before)

 * Current absolute path(max. 255 bytes)

### Set Working Directory(#17)

Sets working directory

Arguments:

 * HL - pointer to path(can be absolute and relative)

Returns:

 * Error info in flag C and register A(similar as before)

### Set Working Drive(#18) - Do we need it?

Get or set working drive.

Arguments:

 * A - drive number(from 1). If value is zero - return current drive.

Returns:

 * Error info in flag C and register A(similar as before)

### Close all user defined file desciptors(#2F)

Close all opened by user files(can be used as )

## Network ABI

### Open TCP connection(#30) 

Arguments:

 * HL - StringZ to hostname

 * BC - port

Returns:

 * Error info in flag C and register A(similar as before)

 * If no error A will contains socket number

### Close TCP connection(#31)

Arguments:

 * A - socket number

Returns:

 * Error info in flag C and register A

### Get socket status(#32)

Arguments:

 * A - socket number

Returns:

 * A - socket flags:

   - Bit 0 - is connected

   - Bit 1 - is data available 

   - Bit 2 - is data sending

 * BC - data available to fetch(zero if socket closed)

### Socket read(#33)

Arguments:

  * A - socket number

  * BC - bytes count

  * HL - pointer to buffer

Returns:

 * Error info in flag C and register A

 * BC - count of bytes what was actually read

 ### Socket write(#34)

Arguments:

  * A - socket number

  * BC - bytes count

  * HL - pointer to buffer

Returns:

 * Error info in flag C and register A

 * BC - actally sent bytes count

### Bind UDP socket(#35)

Arguments:

 * BC - port

Returns:

 * Error info in flag C and register A(similar as before)

 * If no error A will contains socket number

### UDP sendto(#36)

Arguments:

 * A - socket number

 * BC - bytes count

 * HL - pointer to buffer

 * DE - pointer to ipv4(2 words)+port(1 word) struct

Returns:

 * Error info in flag C and register A

 * BC - actally sent bytes count

### ICMP Ping(#37)

Argumnets:

 * HL - pointer to hostname

 * BC - port

 * A - timeout

Returns:

 * Error info in flag C and register A

 * A - value if no error

### Get Host By Name(#38)

Arguments:
 
 * HL - pointer to host name stringZ

 * DE - pointer to ipaddrv4 buffer(2 words)

Returns:

 * Error info in flag C and register A

### Reset networking(#4F)

Close all active user defined connections(can be used as initialization routine).

Returns:
 
 * Flag C setted if WiFi not connected to access point

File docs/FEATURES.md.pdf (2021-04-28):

# ZX Interface Z

## Contents

1 What is ZX Interface Z? | 2
2 The board | 3
3 Main menu | 4
4 Loading software | 5
5 Saving software | 6
6 Pokes | 7
7 Quick snapshot | 7
8 Audio support | 7
9 Video support | 8
10General input device support | 8
11Wireless Support | 9
12Settings configuration | 9

13Networking support | 10
14Firmware upgrade | 10
15The web page | 10
16Hardware considerations | 10
17Hardware limitations | 11

## 1 What is ZX Interface Z?

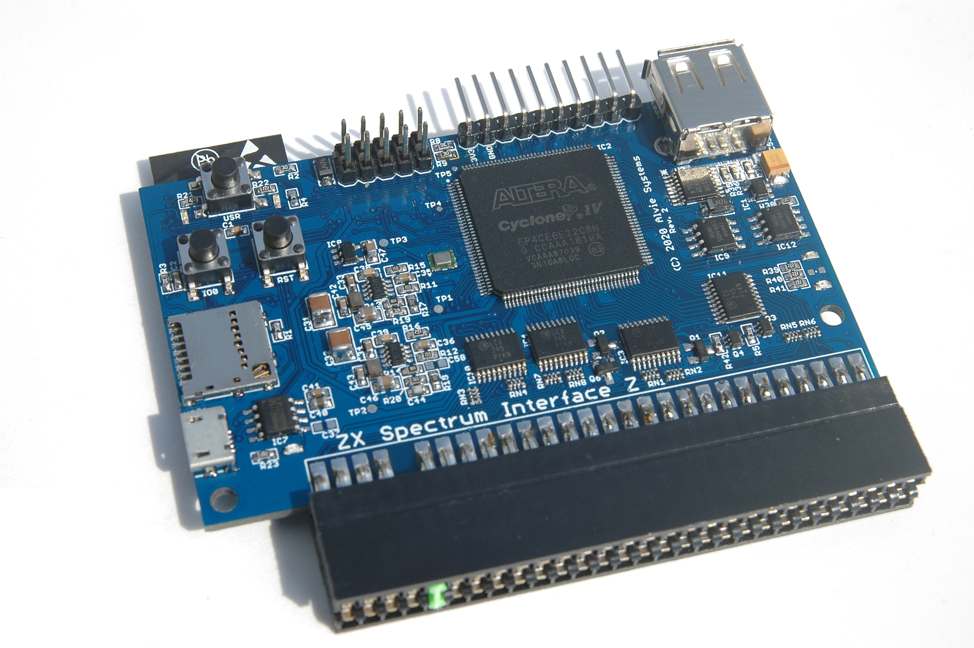
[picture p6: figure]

The ZX Interface Z is an expansion card for the ZX Spectrum which supports, among other

1.1 Current version

features:

- VGA and audio output via micro expansion card
- USB devices, such as keyboard, gamepads and memory sticks.
- Network access via WiFi
- Micro SD card
- Bluetooth [planned]
- YM2149 sound on all models

Internally, the ZX Interface Z includes:

- A dualcore CPU with WiFi and Bluetooth radio
- An Intel FPGA
- 64MB of RAM, also accessible from the ZX Spectrum
- USB for debugging and programming

the ZX Interface Z is fully open source!. The software, the board and the FPGA designs are available online under open source licences so anyone can modify them or build their own.

### 1.1 Current version

The current hardware version is 2.4. This hardware is compatible with the models described in this document.

### 1.2 Where is the source?

All sources are available in github:

https://github.com/alvieboy/ZXInterfaceZ

### 1.3 Supported hardware

The following ZX Spectrum hardware is supported:

- ZX Spectrum 16K
- ZX Spectrum 48K
- ZX Spectrum 128K (gray)
- ZX Spectrum 128K (toastrack)
- ZX Spectrum +2A
- ZX Spectrum +3

Some features might not be available depending on the model. See section Hardware Limitations for details regarding support of your ZX Spectrum model.

## 2 The board

The ZX Interface Z board has the following features available for user interaction and information:

- Two user buttons USR and IO0
- 6 LEDs (one for power, 5 for information)
- One hardreset button

The ZX Interface Z also includes one expansion port which can hold other boards. The VGA and audio output plug into this expansion port.

The USR button is used to access the ZX Interface Z main menu. The IO0 button is configurable and can be used for different purposes.

By default, holding the IO0 button for more than one second loads a Diagnostics ROM which you can use to diagnose your ZX Spectrum hardware.

## 3 Main menu

The main menu is normally accessible by pressing shortly the USR button. Most of the ZX Interface Z functionality is accessible using this menu.

From the main menu, you can:

- Load snapshots
- Save snapshots
- Play tapes
- Poke memory
- Change ZX Interface Z settings
- Reset the ZX Spectrum
- Debug the ZX Spectrum [experimental]
- See information about the system


Figure 1: The main menu

## 4 Loading software

It is possible to load a multitude of software using the ZX Interface Z. Loading of software is either done by restoring the ZX Spectrum state, or by using tapes.

Loading of software is possible from the following sources:

- microSD card
- USB flash drive
- USB CDROM [planned]
- Network [planned]

### 4.1 Loading tape files

The following tape files can be loaded using the ZX Interface Z:

- TAP tapes
- TZX tapes

See Tape Loading Methods for details on limitations of each file type and ZX Spectrum model.

### 4.2 Loading snapshot files

Snapshot files can also be loaded by the ZX Interface Z. The following snapshot files are supported:

- SNA [48K only, 128K planned]
- Z80 [experimental]


Figure 2: Loading snapshots

4.3 Tape loading methods

### 4.3 Tape loading methods

There are two methods for loading tape files. Depending on the tape file and on the platform it might or might not be possible to load them.

### 4.3.1 ROM-hooked LOAD (FastTAP)

This method allows for quick loading of tapes and relies on ROM hooks to perform loading. The following tapes are supported using this mode:

- Standard TAP and TZX tapes (not using custom loaders, like copy protection loaders or fast loaders)

### 4.3.2 Audio emulation loading

This method allows any tape to be loaded, but is not compatible with all ZX Spectrum models. The following tapes are supported using this mode:

- TAP and TZX tapes

See section Hardware Limitations for details regarding support of audio emulation of your ZX Spectrum model.

## 5 Saving software

It is possible to save software using the ZX Interface Z by either capturing the ZX Spectrum state (snapshot) or by saving to tape files.

Saving software is possible to the following devices:

- microSD card
- USB flash drive

### 5.1 Snapshots

It is possible to save a snapshot of the ZX Spectrum to a file. Support for snapshot might depend on the actual ZX Spectrum used. See section Hardware Limitations for details regarding support of snapshots for your ZX Spectrum model.

### 5.2 Automatic load/save menu

The ZX Interface Z comes with a method of automatic load menu. This means whenever you type in LOAD or SAVE commands in the ZX Spectrum BASIC, or if any program enters the standard ROM LOAD or SAVE routines, a pop up will show which allows you to select a TAPE file to load or save. It is possible to append to tape files as well.

## 6 Pokes

The ZX Interface Z supports pokes dynamically all you have to do is to place POK files in your microCD or USB memory stick and load them using the menu. If any parameters are needed, the ZX Interface Z will ask your for their values.


Figure 3: The poke menu where you can select the trainer

## 7 Quick snapshot

This feature is still in the planned stage.

It will be possible to map inputs to trigger a quick snapshot, which is quite useful if you want to immediatly save what is going on in your ZX Spectrum, such as a particular game you are playing.

See General input device support for more details.

## 8 Audio support

The ZX Interface Z supports audio output using a dedicated expansion card. This is usually done by the VGA+Audio companion adaptor.

The ZX Interface Z includes an YM2149 sound chip inside the main FPGA, which can output audio to the Audio adaptor on the expansion port.

The audio output is stereo, and includes a mixer for the internal audio and the YM2149 threechannel outputs. Each of these can be adjusted in volume and balance between the left and right channels.

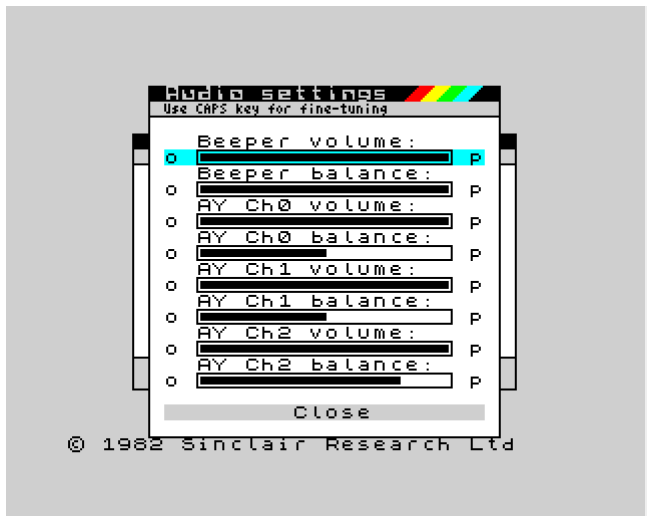
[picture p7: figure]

Figure 4: Configuring audio

The audio configuration is persistent, it will be stored and restored next time you power the ZX Interface Z.

## 9 Video support

The ZX Interface Z supports digital video output through the expansion port. This is often done by plugging the VGA+Audio companion adaptor.

It also supports streaming of the video output via networking, using a custom video encoding prototol.

There are a set of different modes available for VGA output, which can be configured on the settings menu.

The video is generated by capturing the Z80 interaction with the video memory, so even if your ZX Spectrum lower ram is malfunctioning, the video output will still work as expected (so diagnostics ROM will work properly).

## 10 General input device support

The ZX Interface Z is very versatile in terms of input support, being it joysticks, gamepads, mice and keyboards. These connect through the USB port.

The behaviour of each input device (or, more specifically, each physical entity of each device) can be mapped to a particular action. For example, it is possible to configure certain USB keyboard keys to act as a mouse press, or to bring up the main menu, or to perform a quick snapshot save. Also possible, for example, is to map a joystick to keys, or a particular gamepad button to mute the audio output.

The following mappings are available for each physical input:

- Keyboard press+release
- Joystick axis movement or button
- Mouse movement or button
- Main Menu
- Quick save/load [planned]

## 11 Wireless Support

The ZX Interface Z supports WiFi in one of two modes. It can act as a standard WiFi client device (station) connected to a WiFi Access Point, or it can work in standalone mode, where the ZX Interface Z is itself an Access Point where you can connect to.

### 11.0.1 WiFi modes

- 802.11b/g/n support

### 11.0.2 WiFi authentication modes

- WPA2
- Open (no authentication)

## 12 Settings configuration

You can access the settings configuration on the main menu.

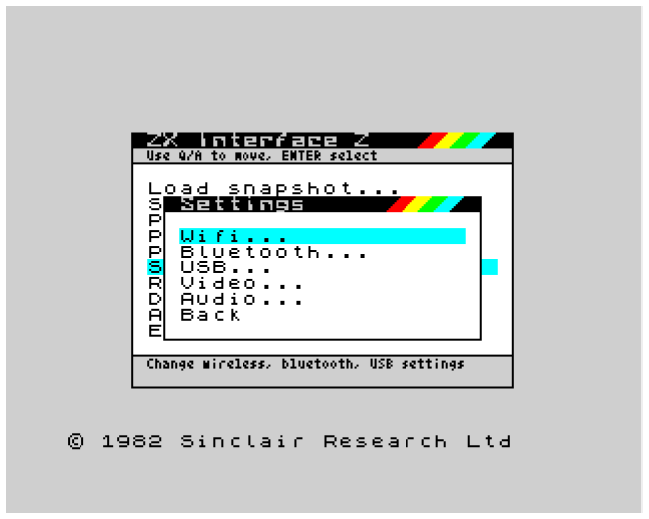
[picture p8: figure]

Figure 5: Settings menu

From the settings menu you can configure:

- WiFi
- Bluetooth [planned]
- USB [experimental]
- Video output settings
- Audio settings

## 13 Networking support

There is full networking support inside the main firmware. A subset of the networking API is available to the ZX Spectrum via a separate API.

## 14 Firmware upgrade

The ZX Interface Z firmware can be upgraded using one of the following methods:

- Micro USB cable using a dedicated tool
- Overtheair upgrade [planned]
- Upgrade via USB flash drive [planned]

## 15 The web page

The ZX Interface Z includes a web site which you can use to perform several configuration and operations.

The web page is accessible by pointing your browser to http://interfacez.local/.

The web page is under active development, and will likely change heavily during development phase.

## 16 Hardware considerations

Take this information into account before using the ZX Interface Z:

- For all models, the USB port is powered by the ZX Spectrum 5V rail. This limits the amount of current that can be drawn by the USB port without interfering with the ZX Spectrum or lead to overheat of the internal ZX Spectrum regulator. DO NOT CONNECT ANY USB DEVICE THAT DRAWS MORE THAN 200mA!!! This may lead to destruction of the ZX Spectrum regulator. The Interface Z team cannot be liable for damage of the ZX Spectrum if such a device is connected. For safety reasons, shorting the USB power lines will temporarly disable the USB port.
- For the ZX Spectrum models powered by +9V supply, the Interface Z power is drawn directly from the +9V rail.
- For the ZX Spectrum models not powered by +9V supply, the Interface Z power is drawn from the +12V rail.

## 17 Hardware limitations

The following platforms might have limitations due to ZX Spectrum hardware design:

### 17.1 ZX Spectrum 16K

No limitations

### 17.2 ZX Spectrum 48K

No limitations

### 17.3 ZX Spectrum 128K (gray)

Snapshots are only possible for 48K mode (128K support is planned)

### 17.4 ZX Spectrum 128K (toastrack)

Audio emulation for tape loading is not supported

Snapshots are only possible for 48K mode (128K support is planned)

### 17.5 ZX Spectrum +2A

Audio emulation for tape loading is not supported.

Snapshots are only possible for 48K mode (128K support is planned)

### 17.6 ZX Spectrum +3

Audio emulation for tape loading is not supported

Snapshots are only possible for 48K mode (128K support is planned)

### 17.7 Other models

Other ZX Spectrum models, clones and TIMEX models are currenly unsupported.

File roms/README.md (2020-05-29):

# ZX Spectrum ROMs

## Prerequisites

- pasmo 0.6.0 preview

### Building Pasmo 0.6.0-preview from Source

**Debian/Ubuntu**

The pasmo package from apt is too old, you need to install from source. And
pasmo must be patched to build with a current version of Debian/Ubuntu.

```
wget http://pasmo.speccy.org/bin/pasmo-0.6.0.20070113.0.tgz
tar -xzf pasmo-0.6.0.20070113.0.tgz
cd pasmo-0.6.0.20070113.0/
pathc -p1 < ../pasmo-0.6.0.20070113.0.patch

./configure
make
sudo make install
```

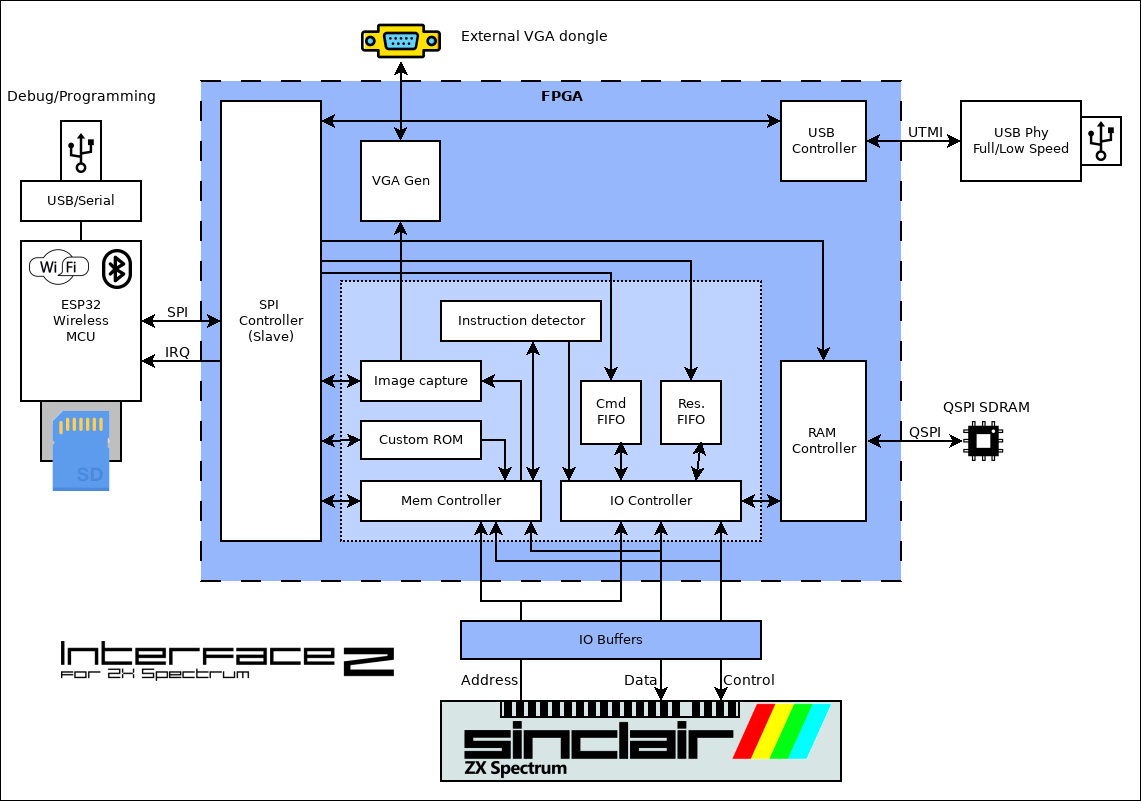
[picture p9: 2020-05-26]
docs/overview.png

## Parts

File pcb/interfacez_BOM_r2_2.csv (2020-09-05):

Qty | Value | Device | Package | Parts | Description | AUTOMOTIVE | CENTROID_NOT_SPECIFIED | CONN_GENDER | CONN_ORIENTATION | CONTACT_MATERIAL | CURRENT_RATING | DATASHEET | DESCRIPTION | DEVICE_CLASS_L1 | DEVICE_CLASS_L2 | DEVICE_CLASS_L3 | DIGIKEY_DESCRIPTION | DIGIKEY_PART_NUMBER | FOOTPRINT_URL | FOOTPRINT_VARIANT_NAME_0 | HEIGHT | LEAD_FREE | MANUFACTURER_NAME | MANUFACTURER_PART_NUMBER | MF | MFG_PACKAGE_IDENT | MFG_PACKAGE_IDENT_DATE | MFG_PACKAGE_IDENT_REV | MOUSER_DESCRIPTION | MOUSER_PART_NUMBER | MOUSER_PRICE-STOCK | MPN | NUMBER_OF_CONTACTS | NUMBER_OF_ROWS | OC_FARNELL | OC_NEWARK | PACKAGE | PITCH | PREFIX | ROHS | TEMPERATURE_RANGE_HIGH | TEMPERATURE_RANGE_LOW | TP_SIGNAL_NAME | VERIFICATION_VERSION | VOLTAGE_RATING
1 |  | F15HDH | HDF15H | X1 | SUB-D |  |  |  |  |  |  |  |  |  |  |  |  |  |  |  |  |  |  |  |  |  |  |  |  |  |  |  |  |  | unknown | unknown
1 |  | PINHD-2X10 | 2X10 | JP1 | PIN HEADER
1 | 0R | R0603 | 0603 | R81 | RESISTOR, European symbol
2 | 0R/DNP | R0603 | 0603 | R67, R68 | RESISTOR, European symbol
1 | 1000pF 2KV | C1210 | 1210 | C50 | CAPACITOR, European symbol
4 | 100K | R0603 | 0603 | R24, R25, R26, R38 | RESISTOR, European symbol
3 | 100R | R0603 | 0603 | R37, R62, R65 | RESISTOR, European symbol
8 | 100nF | C0603 | 0603 | C54, C61, C63, C93, C94, C95, C100, C101 | CAPACITOR, European symbol
4 | 100nF 16V | C0603 | 0603 | C33, C34, C35, C36 | CAPACITOR, European symbol
39 | 100nF 6.3V | C0603 | 0603 | C3, C4, C5, C6, C7, C8, C9, C10, C11, C12, C13, C14, C15, C16, C17, C18, C19, C20, C21, C22, C23, C24, C25, C26, C27, C28, C29, C30, C41, C42, C43, C48, C49, C51, C52, C53, C56, C64, C66 | CAPACITOR, European symbol
2 | 100nF/DNP | C0603 | 0603 | C58, C99 | CAPACITOR, European symbol
1 | 1040310811 | 1040310811 | 1040310811 | SD1
20 | 10K | R0603 | 0603 | R1, R2, R3, R4, R5, R6, R7, R8, R9, R10, R27, R28, R29, R30, R31, R32, R33, R34, R42, R78 | RESISTOR, European symbol
1 | 10uF | C0603 | 0603 | C40 | CAPACITOR, European symbol
1 | 10uF 6.3V TBD | C0805 | 0805 | C47 | CAPACITOR, European symbol
1 | 12K1 | R0603 | 0603 | R82 | RESISTOR, European symbol
3 | 130R | R0603 | 0603 | R48, R49, R50 | RESISTOR, European symbol
1 | 13K | R0603 | 0603 | R18 | RESISTOR, European symbol
3 | 140K | R0603 | 0603 | R11, R12, R15 | RESISTOR, European symbol
2 | 15K | R0603 | 0603 | R43, R57 | RESISTOR, European symbol
1 | 15pF | C0603 | 0603 | C44 | CAPACITOR, European symbol
3 | 1K24 | R0603 | 0603 | R51, R53, R55 | RESISTOR, European symbol
2 | 1K8 | R0603 | 0603 | R63, R66 | RESISTOR, European symbol
1 | 1M | R0805 | 0805 | R45 | RESISTOR, European symbol
3 | 1nF | C0603 | 0603 | C1, C2, C98 | CAPACITOR, European symbol
2 | 1uF | C0603 | 0603 | C37, C97 | CAPACITOR, European symbol
1 | 2.2uF | C0805 | 0805 | C96 | CAPACITOR, European symbol
2 | 20R | R0603 | 0603 | R13, R14 | RESISTOR, European symbol
2 | 220R | R0603 | 0603 | R61, R64 | RESISTOR, European symbol
2 | 22nF 6.3V | C0603 | 0603 | C38, C39 | CAPACITOR, European symbol
2 | 22uF 16V | C1210 | 1210 | C31, C32 | CAPACITOR, European symbol
2 | 22uF 6.3V TBD | C0805 | 0805 | C45, C46 | CAPACITOR, European symbol
1 | 24K | R0603 | 0603 | R16 | RESISTOR, European symbol
11 | 2K2 | R0603 | 0603 | R21, R22, R23, R39, R40, R41, R69, R70, R71, R79, R80 | RESISTOR, European symbol
3 | 309R | R0603 | 0603 | R58, R59, R60 | RESISTOR, European symbol
1 | 30K1 | R0603 | 0603 | R19 | RESISTOR, European symbol
6 | 330R | 4R-NEXB28V | EXB28V | RN1, RN2, RN3, RN4, RN5, RN6 | Array Chip Resistor |  |  |  |  |  |  |  |  |  |  |  |  |  |  |  |  |  |  |  |  |  |  |  |  |  |  |  |  |  | unknown | unknown
2 | 330R | R0603 | 0603 | R87, R88 | RESISTOR, European symbol
2 | 33R | 4R-NEXB28V | EXB28V | RN7, RN8 | Array Chip Resistor |  |  |  |  |  |  |  |  |  |  |  |  |  |  |  |  |  |  |  |  |  |  |  |  |  |  |  |  |  | unknown | unknown
2 | 33R | R0603 | 0603 | R35, R36 | RESISTOR, European symbol
1 | 40K2 | R0603 | 0603 | R20 | RESISTOR, European symbol
1 | 470K/DNP | R0603 | 0603 | R44 | RESISTOR, European symbol
2 | 47uF | C1206 | 1206 | C55, C62 | CAPACITOR, European symbol
3 | 47uF 6.3V TANT | TANT_CASE_A | TANT_CASE_A | C57, C60, C65
4 | 49R9 | R0603 | 0603 | R83, R84, R85, R86 | RESISTOR, European symbol
1 | 600R | L0805 | 0805 | L8 | INDUCTOR, European symbol
3 | 619R | R0603 | 0603 | R52, R54, R56 | RESISTOR, European symbol
1 | 61K9 | R0603 | 0603 | R17 | RESISTOR, European symbol
4 | 74LCX245FT | 74245 | TSSOP20 | IC3, IC4, IC10, IC11 | Octal BUS TRANSCEIVER, 3-state
2 | 82R5 | R0603 | 0603 | R46, R47 | RESISTOR, European symbol
1 | AMPHENOL_ICC_-_FCI_20021121-00010C4LFAMPHENOL_ICC_-_FCI_20021121-00010C4LF_0_0 | AMPHENOL_ICC_-_FCI_20021121-00010C4LFAMPHENOL_ICC_-_FCI_20021121-00010C4LF_0_0 | AMPHENOL_ICC_-_FCI_20021121-00010C4LF_0 | J1 | Connector Header Surface Mount 10 position 0.050 (1.27mm)" | No | No | Male | Vertical | Gold,Nickel | 1A | https://cdn.amphenol-icc.com/media/wysiwyg/files/documentation/datasheet/boardwiretoboard/bwb_minitek127_btb.pdf |  | Connectors | Headers and Wire Housings | unset | CONN HEADER SMD 10POS 1.27MM | 609-3695-1-ND | https://cdn.amphenol-icc.com/media/wysiwyg/files/drawing/20021121.pdf | Recommended_Land_Pattern | 4.8mm | Yes |  |  | Amphenol ICC / FCI | 0 | 0 | 0 | Conn | Rect | BrdtoBrd | UnshroudedHeader | 10Cnts | SMT | 1.27x1.27mmSpng | 649-202112100010C4LF |  | 20021121-00010C4LF | 10 | 2 |  |  | HDR10 | 1.27mm | J
3 | BSS123 | BSS123 | SOT23 | Q1, Q2, Q6 | N-CHANNEL MOS FET
1 | BSS84 | BSS84 | SOT23 | Q5 | P-CHANNEL MOS FET
1 | BSS84DW | BSS84DW | SOT363_INFINEON | U$4
1 | CH330N | CH330N | SOIC8 | IC7
2 | CJ3439KDW | CJ3439KDW | SC70-6 | Q3, Q4
1 | CON-USB-F-MICRO-B | CON-USB-F-MICRO-B | CONN_USB_MICRO-B | USB1 | USB Female connector
1 | EP4CE6E22C8N | EP4CE6E22C8N | QFP50P2200X2200X165-145N | IC2 | FPGA Cyclone IV 6272 Cells TQFP144 EP4CE6E22C8N, FPGA Cyclone IV E 6272 Cells, 270kbit, 392 Blocks, 1.15 1.25 V 144-Pin EQFP |  |  |  |  |  |  |  | FPGA Cyclone IV 6272 Cells TQFP144 EP4CE6E22C8N, FPGA Cyclone IV E 6272 Cells, 270kbit, 392 Blocks, 1.15 1.25 V 144-Pin EQFP |  |  |  |  |  |  |  | 1.65mm |  | Intel | EP4CE6E22C8N |  |  |  |  |  | 989-EP4CE6E22C8N | https://www.mouser.com/Search/Refine.aspx?Keyword=989-EP4CE6E22C8N
1 | ESP-WROOM-32 | ESP-WROOM-32 | ESP-WROOM-32 | U1
1 | Hanrun HR917550A | HR913550A | HR13550A | T1
4 | INTERFACEZ_EDGEDAUGHTER | INTERFACEZ_EDGEDAUGHTER | INTERFACEZ_EXPANSION_DAUGHTERCARD | U$2, U$5, U$8, U$10
1 | KC3225K-32MHz | KC3225K | KC3225K | U$1
1 | LAN8720A | LAN8720A | QFN24_4MM_X_4MM | IC14
6 | LG L29K-G2J1-24 | LED-0603 | LED-603 | LED1, LED2, LED3, LED4, LED5, LED6 | Light Emitting Diode
1 | LY68L6400SLIT | LY68L6400SLIT | SOIC8 | IC9
1 | MIC5504-2.5YM5-TR | MIC550X | SOT23-5L | IC8
2 | MP2233DJ | MP2233DJ | SOT23-8L | IC5, IC6
1 | NC7WZ16P6X | NC7WZ07P6X | SC70-6 | IC13 | Dual line drivers with 3-state outputs.
1 | PIN-1X10 | PIN-1X10 | PIN-1X10 | U$7
1 | PIN-2X5 | PIN-2X5 | PIN-2X5 | U$16
1 | PIN-2X5-1.27MM | PIN-2X5-1.27MM | PIN-2X5-1.27 | U$15
1 | PJ328-A0 | PJ328-A0 | PJ328A0 | U$9
3 | PMS150C-U06 | PMS150C-U06 | SOT23-6 | U$3, U$6, U$11
1 | SP0503BAHT | SP0503BAHT | SP0503 | TV26
1 | STMPS2141STR | STMPS2141STR | SOT23-5L | IC1
3 | SWITCHES_SMD-4 | SWITCHES_SMD-4 | TACTILE_SWITCH_TALL | S1, S2, S3 | Various NO switches- pushbuttons, reed, etc
1 | TAJB107M010RNJ | C-PR-SMD-TE-B | TE-B-3528 | C59 | POLARIZED ELECTROLYTIC/TANTALUM
1 | TPTP08R | TPTP08R | TP08R | TP4 | Test pad
3 | TPTP12R | TPTP12R | TP12R | TP1, TP2, TP3 | Test pad
1 | USB-A-H | USB-A-H | USB-A-H | USB2 | USB Connectors
1 | USB1T11AMTCX | USB1T11AMTCX | TSSOP14 | IC12
1 | VLS201610HBX1R5-M1 | VLS201610HBX1R5-M1 | IND_0806 | L2
1 | VLS201610HBXR68-M1 | VLS201610HBXR68-M1 | IND_0806 | L1
1 | ZX_EDGE_DAUGHTERBOARD | ZX_EDGE_DAUGHTERBOARD | ZX-EDGE-DAUGHTERBOARD | CONN1

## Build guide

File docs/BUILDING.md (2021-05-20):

# Building Interface Z
Here are the basic instructions to fully build the InterfaceZ. It is split into four parts:
- [Building the FPGA binary file](#building-the-fpga-binary-file)
- [Building Angular Webapp](#building-angular-webapp)
- [Building ESP32 firmware](#building-esp32-firmware)
- [Manually uploading the design](#manually-uploading-the-design)
- [Building host-mode firmware](#building-host-mode-firmware)

## Getting the source.
Make sure you have an updated repository. Place it in any path and then `export INTERFACE_Z=/path/to/interfacez`.

## Building the FPGA binary file

### Prerequisites
You will need Intel Quartus (Lite or better) in order to build the FPGA design. It will also need to include the Cyclone IV support.
You can download the Lite edition for free from [the Intel website](https://fpgasoftware.intel.com/?edition=lite).

### Building the binary bitfile (GUI)
Launch Quartus and open the project file *interfacez.qpf* . Perform a full "Compile design" step. That should generate the output file (which is
*output_files/interfacez.rbf*. No need to perform any programming of the FPGA at this point - uploading will be handled in [Manually uploading the design](#manually-uploading-the-design) .

### Building the binary bitfile (Command line)

```
cd $INTERFACE_Z/fpga/r2.2
make
```

## Building Angular Webapp
### Prerequisites

- [NodeJS](https://nodejs.org/en/) 12.x or later (including `npm`)
- [Gulp](https://gulpjs.com/) `npm install --gloabal gulp-cli`

To install NodeJS on Debian/Ubuntu don't use the provided packages since they are for NodeJS  8.11

### Building the Webapp

```
cd $INTERFACE_Z/webapp
npm install
ng build --prod
gulp default
gulp install-into-spiffs
```

## Building ESP32 firmware
### Pre-requesites

- Install ESP IDF somewhere on your PC,  but outside the InterfaceZ project. For this 
project a slightly modified ESP IDF is used which is published also in github, 
based in ESP IDF release 4.2
```bash
git clone git@github.com:alvieboy/esp-idf.git
cd esp-idf
git checkout interfacez
bash install.sh
source export.sh
```

Note that anytime you need to use the IDF you need to source the "export.sh" file as above.

### Get Git Submodules

```bash
cd $INTERFACE_Z
git submodule init
git submodule update
```

### Building

Build the esp32 code by typing "make" on the esp32 directory

```bash
cd $INTERFACE_Z/esp32
make
```
It should generate all required files for programming.

## Manually uploading the design

In order to manually upload the design, you need to connect an USB cable from your PC to the debug port of Interface Z. No extra drivers should be needed.

Once you connect the device, enter programming mode using the following steps:
- Press (and DO NOT RELEASE) button IO0 on the board
- Press RESET button
- Release RESET button
- Release IO0 button.

At this point, the green LED on the top left should have stopped flashing.
Proceed to flash the InterfaceZ by issuing the following commands:
```bash
cd $INTERFACE_Z/esp32
make flash
```
It should program the board, but it will be held in programming mode. To exit programming mode back to run time mode, do
- Press RESET button

If your _Interface Z_ is connected to another port than the standard (on Linux `ttyUSB0`) use `ESPPORT` to configure it. Example:
```bash
make flash ESPPORT=/dev/ttyUSB1
```

## Building host-mode firmware
The Host-mode firmware is used solely for development.
### Prerequisites
Install these dependencies

- Debian/Ubuntu

```bash
sudo apt install libglib2.0-dev qtbase5-dev qtbase5-dev-tools qtchooser
```

- Fedora

```bash
sudo dnf install glib2-devel qt5-qtbase-devel qtchooser
```

### Building host-mode
If you already tested building the ESP32 firmware, some simple steps are required to build the host firmware:

```bash
cd $INTERFACE_Z/esp32
make -C host
```
### Starting host-mode
You can then start the application in host mode:
```bash
cd $INTERFACE_Z/esp32
host/interfacez
```
To open the web interface on host mode, point your browser to http://localhost:8000

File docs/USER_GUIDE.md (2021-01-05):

# ZX Interface Z

## Quick Start

- Turn off your ZX Spectrum
- Connect the _Interface Z_, ensure that it is firmly inserted into the expansion port.
- Power on your ZX Spectrum.
- Push the **USR** button to bring up the _ZX Interface Z main menu_.

# Using your ZX Interface Z

The Interface Z can be controlled through the _ZX Interface Z main menu_ which
is brought up by pushing the **USR** button or by accessing the _Web Interface_
if network has been set up.

## Board Layout

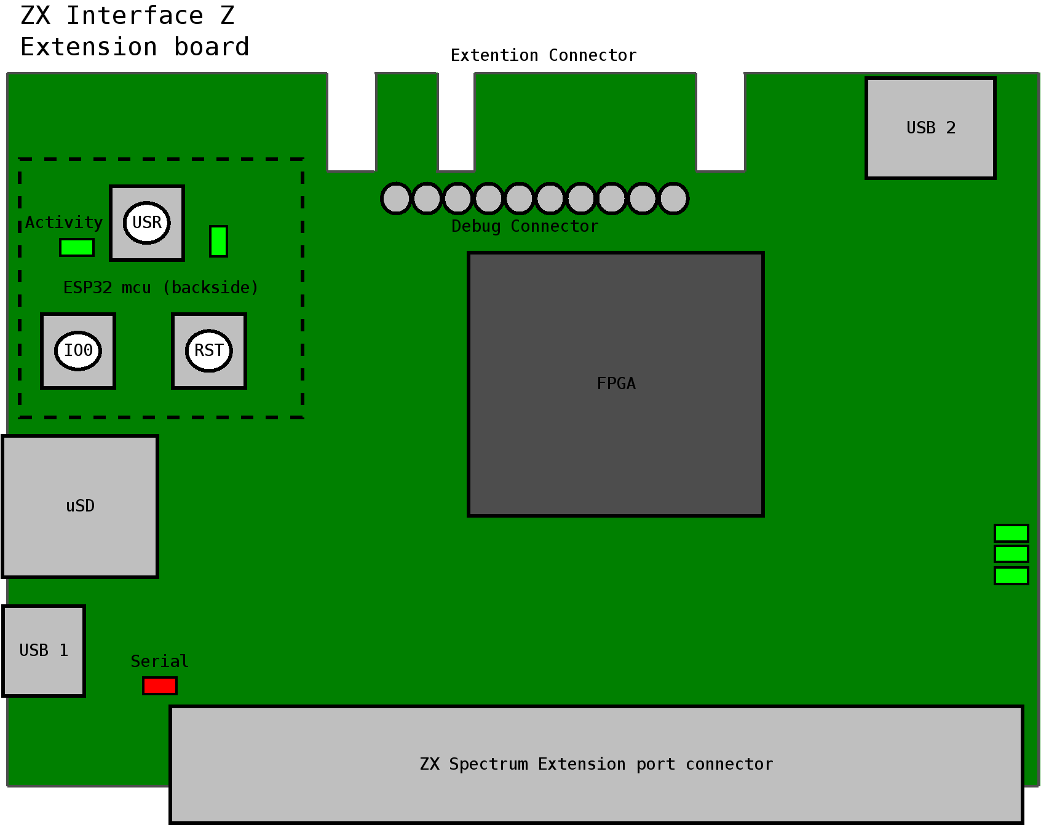
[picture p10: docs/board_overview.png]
Interface Z - Board Layout


## Navigation

#### USB Joystick

Not implemented yet.

#### Keyboard

- `Q` - Up
- `A` - Down
- `ENTER` - Select
- `BREAK` - Back

## Video

Adjusting Video output

## Sound

## Load/Save Snapshot

## Fast Load Tape

- Trigger the _main menu_, and chose _Play tape (fast)..._ choose the TAP or TZX file.
- Type in `LOAD ""`
- Enjoy as if you were using a super fast tape.

## Play Tape

- Type in `LOAD ""`
- Trigger the _main menu_, and chose _Play tape..._ choose the TAP or TZX file.
- Enjoy as if you were using a real tape.

## Poke

# Web Interface

## Connecting to Wifi

Default is _SSID_ `ZXInterfaceZ`, _password_ `zxspectrum`, and IP `192.168.120.1`.

# Advance

## Serial Console

You can connect to the _ZX Interface Z_'s serial console by connecting a
USB-cable to the _micro USB_ port and connecting with a terminal program
at `115200` baud with `8N1`. The USB serial chip used is a _CH330_.

Example command to connect with `cu` on Linux:

```
cu -l /dev/ttyUSB0 -s 115200
```

Be sure to double check which device is the _ZX Interface Z_. It can be done
with `dmesg | grep ttyUSB`.

### Console Commands

TODO See [console.c](https://github.com/alvieboy/ZXInterfaceZ/blob/master/esp32/main/console.c#L168)

# Troubleshooting

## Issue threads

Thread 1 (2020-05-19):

SDCARD: Pullup on IO2

alvieboy, 2020-05-19:
The current pullup on IO2/SDMMC_D0 interferes with serial bootloader and makes it impossible to program the ESP32 via serial USB port.

This pullup should be connected using MOSFET as we already do for SDMMC_D2/IO12.

alvieboy, 2020-05-30:
Replace current MOSFET with dual BSS84DW or equivalent, and replicate IO12 circuit to IO2.

Closed 2020-06-11.

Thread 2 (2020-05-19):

NC3/B4 should connect to the FPGA

alvieboy, 2020-05-19:
NC3/B4 should connect to the FPGA as it is a second ROMCS for 128K.

alvieboy, 2020-05-30:
Proposed solution: connect B4 to FORCE_ROMCS using a 0R resistor.

alvieboy, 2020-06-11:
Fixed with a new pullup mosfet.

Closed 2020-06-11.

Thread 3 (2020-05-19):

USB: missing pulldowns for host-mode

alvieboy, 2020-05-19:
In order to use host mode, D+ and D- lines should have a 15KΩ pulldown to ground.

alvieboy, 2020-06-11:
Added in R2.2

Closed 2020-06-11.

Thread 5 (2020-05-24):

ZX Spectrum 128K compatibility issues

nihirash, 2020-05-24:
As I understand(I might be wrong) - this device uses ports #03, #05, #07 etc.

Main issue of this solution that it makes device totally incompatible with ZX Spectrum 128K and later(+2/+2A/+3/128K compatible computers) - cause IORQULA block only #FE port and doesn't block AY's ports, memory management unit, disk and printer ports(on +3).

Main issue that original ZX SPECTRUM machines uses bit mask decoding of port instead full address decoding.

You should use ports that didn't cross with audio ports, memory ports, +3 FDC and internal cetronics port of +2A/+3.

Information about bit masks present here: https://www.worldofspectrum.org/faq/reference/ports.htm

Thank you for your work!

I wish you can make it best!

alvieboy, 2020-05-24:
Indeed we may need to choose different port numbers, eventually using full-decoding as well.

Some notes:
 - The IORQULA is only used to mask/update ULA replies for simulating keyboard and audio input. Since (I believe) all IO requests with A0=0 go to a single ULA "register", we are ok here.
 - For other ports, we may also need to use A15-A8 to avoid collision with other spectrums. Note that we don't need conflict checking for interfaces, since none can be connected at same time.

I'll analyse all IO in detail and try to come up with a sensible range for Interface Z, even if it means more complexity on the software side (since we need to manipulate B as well).

Leaving this open while the issue is being analysed.

alvieboy, 2020-05-24:
I added a simple address analysis document. I believe if we use addresses with A0=1, A1=1, A6=1, A7=0 we can avoid clashing with other devices. This gives us 16 IO addresses to use, should be more than enough, and does not require manipulating A8-A15.

Closed 2020-06-11.

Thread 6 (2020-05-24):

LineBuffer.h and linebuffer.h conflict on case insensitive filesystems.

nihirash, 2020-05-24:
My usual linux laptop just dead so I've cloned repo from macOS - there was collision between both files(same issue will get all windows users and some linux users).

I've solved it by creating case sensitive volume but not everyone will make it(btw, some linux users using case insensitive mode of ext4 file system).

I recommend rename LineBuffer.h to LineBuffer.hpp that will solve this issue at all.

alvieboy, 2020-05-24:
The "C" files are not used on the demo project, so they will be removed.

Closed 2020-05-24.

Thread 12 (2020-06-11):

Feature: Web Interface

alvieboy, 2020-06-11:
Design the main structure of the web interface.
The main web interface will be stored inside a "spiffs" filesystem. A preliminary version can be found inside "esp32/spiffs".
The interface shall have multiple tabs, one for each major area. All pages shall be static, dynamic content will be fetched using AJAX.

rickard-von-essen, 2020-11-28:
Let's called this fixed by #50

Closed 2020-11-28.

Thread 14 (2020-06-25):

Host mode build problem - esp_system.h missing

rickard-von-essen, 2020-06-25:
```shell
$ make -C host
make: Entering directory '/home/rickardvonessen/src/ZXInterfaceZ/esp32/host'
cc -O2 -g -Wall -Wextra -DIDF_VER=\"0.1\" -I/home/linuxbrew/.linuxbrew/Cellar/glib/2.62.4/include/glib-2.0 -I/home/linuxbrew/.linuxbrew/Cellar/glib/2.62.4/lib/glib-2.0/include -I/home/linuxbrew/.linuxbrew/opt/gettext/include -I/home/linuxbrew/.linuxbrew/Cellar/pcre/8.43/include -I./FreeRTOS/Source//include -I./FreeRTOS/Source//portable/GCC/Linux -I./FreeRTOS/ -Iesplayer -I. -I/home/alvieboy/Temp/esp-idf//components/esp_system/include/ -I/home/alvieboy/Temp/esp-idf//components/soc/soc/esp32/include/ -I/home/alvieboy/Temp/esp-idf//components/esp_common/include/ -I/home/alvieboy/Temp/esp-idf//components/spi_flash/include/ -I/home/alvieboy/Temp/esp-idf//components/soc/include/ -I/home/alvieboy/Temp/esp-idf//components/esp_event/include/ -I/home/alvieboy/Temp/esp-idf//components/esp_wifi/include/ -I/home/alvieboy/Temp/esp-idf//components/esp_timer/include/ -I/home/alvieboy/Temp/esp-idf//components/fatfs/vfs/ -I/home/alvieboy/Temp/esp-idf//components/fatfs/src/ -I/home/alvieboy/Temp/esp-idf//components/wear_levelling/include/ -I/home/alvieboy/Temp/esp-idf//components/esp_netif/include/ -I/home/alvieboy/Temp/esp-idf//components/esp_eth/include/ -I/home/alvieboy/Temp/esp-idf//components/spiffs/include/ -I/home/alvieboy/Temp/esp-idf//components/mbedtls/mbedtls/include -I/home/alvieboy/Temp/esp-idf//components/app_update/include/ -I/home/alvieboy/Temp/esp-idf//components/bootloader_support/include/ -I/home/alvieboy/Temp/esp-idf//components/esp_http_client/include/ -I/home/alvieboy/Temp/esp-idf//components/esp_http_server/include/ -I/home/alvieboy/Temp/esp-idf//components/esp_http_server/src/port/esp32 -I/home/alvieboy/Temp/esp-idf//components/esp_http_server/src/util -I/home/alvieboy/Temp/esp-idf//components/nghttp/port/include/ -I/home/alvieboy/Temp/esp-idf//components/nvs_flash/include/ -I/home/alvieboy/Temp/esp-idf//components/tcpip_adapter/include/ -I/home/alvieboy/Temp/esp-idf//components/driver/include/ -I/usr/include/cjson    -c -o ../main/aplist_resource.o ../main/aplist_resource.c
In file included from ../main/aplist_resource.c:2:0:
../main/fpga.h:5:24: fatal error: esp_system.h: No such file or directory
compilation terminated.
<builtin>: recipe for target '../main/aplist_resource.o' failed
make: *** [../main/aplist_resource.o] Error 1
make: Leaving directory '/home/rickardvonessen/src/ZXInterfaceZ/esp32/host'
```

Also while building the file `esp32/sdkconfig` gets modified. Should this file be committed to the repository?

alvieboy, 2020-06-25:
A few files might be missing from the repo. In regards to "sdkconfig", it's a good question - the file might be changed by the ESP-IDF subsystem, but we need to place a "default" one somewhere.

alvieboy, 2020-06-25:
The problem was an hardcoded IDF path. Care to test it ?

rickard-von-essen, 2020-06-25:
Ok, new error:

```
make: Entering directory '/home/rickardvonessen/src/ZXInterfaceZ/esp32/host'
cc -O2 -g -Wall -Wextra -DIDF_VER=\"0.1\" -I/home/linuxbrew/.linuxbrew/Cellar/glib/2.62.4/include/glib-2.0 -I/home/linuxbrew/.linuxbrew/Cellar/glib/2.62.4/lib/glib-2.0/include -I/home/linuxbrew/.linuxbrew/opt/gettext/include -I/home/linuxbrew/.linuxbrew/Cellar/pcre/8.43/include -I./FreeRTOS/Source//include -I./FreeRTOS/Source//portable/GCC/Linux -I./FreeRTOS/ -Iesplayer -I. -I../main/ -I/home/rickardvonessen/src/esp-idf//components/esp_system/include/ -I/home/rickardvonessen/src/esp-idf//components/soc/soc/esp32/include/ -I/home/rickardvonessen/src/esp-idf//components/esp_common/include/ -I/home/rickardvonessen/src/esp-idf//components/spi_flash/include/ -I/home/rickardvonessen/src/esp-idf//components/soc/include/ -I/home/rickardvonessen/src/esp-idf//components/esp_event/include/ -I/home/rickardvonessen/src/esp-idf//components/esp_wifi/include/ -I/home/rickardvonessen/src/esp-idf//components/esp_timer/include/ -I/home/rickardvonessen/src/esp-idf//components/fatfs/vfs/ -I/home/rickardvonessen/src/esp-idf//components/fatfs/src/ -I/home/rickardvonessen/src/esp-idf//components/wear_levelling/include/ -I/home/rickardvonessen/src/esp-idf//components/esp_netif/include/ -I/home/rickardvonessen/src/esp-idf//components/esp_eth/include/ -I/home/rickardvonessen/src/esp-idf//components/spiffs/include/ -I/home/rickardvonessen/src/esp-idf//components/mbedtls/mbedtls/include -I/home/rickardvonessen/src/esp-idf//components/app_update/include/ -I/home/rickardvonessen/src/esp-idf//components/bootloader_support/include/ -I/home/rickardvonessen/src/esp-idf//components/esp_http_client/include/ -I/home/rickardvonessen/src/esp-idf//components/esp_http_server/include/ -I/home/rickardvonessen/src/esp-idf//components/esp_http_server/src/port/esp32 -I/home/rickardvonessen/src/esp-idf//components/esp_http_server/src/util -I/home/rickardvonessen/src/esp-idf//components/nghttp/port/include/ -I/home/rickardvonessen/src/esp-idf//components/nvs_flash/include/ -I/home/rickardvonessen/src/esp-idf//components/tcpip_adapter/include/ -I/home/rickardvonessen/src/esp-idf//components/driver/include/ -I/usr/include/cjson    -c -o ../main/aplist_resource.o ../main/aplist_resource.c
In file included from ../main/aplist_resource.h:5:0,
                 from ../main/aplist_resource.c:1:
../main/json.h:1:19: fatal error: cJSON.h: No such file or directory
compilation terminated.
<builtin>: recipe for target '../main/aplist_resource.o' failed
make: *** [../main/aplist_resource.o] Error 1
make: Leaving directory '/home/rickardvonessen/src/ZXInterfaceZ/esp32/host'
```

rickard-von-essen, 2020-06-25:
Maybe I have the wrong json library? 🤔

rickard-von-essen, 2020-06-25:
Is this required? https://packages.debian.org/source/sid/cjson

alvieboy, 2020-06-25:
> Maybe I have the wrong json library? thinking

Yes. You really need "libcjson-dev", not "libjson-c-dev".

alvieboy, 2020-06-25:
Also check https://github.com/alvieboy/ZXInterfaceZ/commit/0d39152bb75d62a0017479f068942dc88ea667c9 in case it does not find the library

rickard-von-essen, 2020-06-25:
Yes, unfortunately `libcjson-dev` isn't available for Debian stretch (oldstable). I'll see if I can get it from packports.

alvieboy, 2020-06-25:
> Yes, unfortunately `libcjson-dev` isn't available for Debian stretch (oldstable). I'll see if I can get it from packports.

It's such a simple library you can probably build a DEB without much hassle. Or again, I can add it (probably easier). Let me see how much effort it takes.

alvieboy, 2020-06-25:
Can you please try https://github.com/alvieboy/ZXInterfaceZ/commit/930e11a56000b373fa46aeed1ff0048aa44921d9 ?

rickard-von-essen, 2020-06-25:
Needed a fixing these:

```diff
diff --git a/esp32/host/Makefile b/esp32/host/Makefile
index f46f8c7..ef034ff 100644
--- a/esp32/host/Makefile
+++ b/esp32/host/Makefile
@@ -129,14 +129,14 @@ OBJS:=$(FREERTOS_OBJS) $(OBJ) \
 	esplayer/nvs_flash.o \
 	esplayer/driver/gpio.o \
 	esplayer/driver/spi_master.o \
-/home/alvieboy/Temp/esp-idf/components/esp_http_server/src/httpd_parse.o \
-/home/alvieboy/Temp/esp-idf/components/esp_http_server/src/httpd_txrx.o  \
-/home/alvieboy/Temp/esp-idf/components/esp_http_server/src/httpd_sess.o  \
-/home/alvieboy/Temp/esp-idf/components/esp_http_server/src/httpd_ws.o    \
-/home/alvieboy/Temp/esp-idf/components/esp_http_server/src/httpd_uri.o   \
-/home/alvieboy/Temp/esp-idf/components/esp_http_server/src/httpd_main.o  \
-/home/alvieboy/Temp/esp-idf/components/esp_http_server/src/util/ctrl_sock.o  \
-/home/alvieboy/Temp/esp-idf/components/nghttp/nghttp2/third-party/http-parser/http_parser.o
+	$(ESP_IDF)/components/esp_http_server/src/httpd_parse.o \
+	$(ESP_IDF)/components/esp_http_server/src/httpd_txrx.o  \
+	$(ESP_IDF)/components/esp_http_server/src/httpd_sess.o  \
+	$(ESP_IDF)/components/esp_http_server/src/httpd_ws.o    \
+	$(ESP_IDF)/components/esp_http_server/src/httpd_uri.o   \
+	$(ESP_IDF)/components/esp_http_server/src/httpd_main.o  \
+	$(ESP_IDF)/components/esp_http_server/src/util/ctrl_sock.o  \
+	$(ESP_IDF)/components/nghttp/nghttp2/third-party/http-parser/http_parser.o

 interfacez: $(OBJS)
@@ -144,4 +144,4 @@ interfacez: $(OBJS)

 clean:
 	rm -f $(OBJS)
-
\ No newline at end of file
+
```

rickard-von-essen, 2020-06-25:
Then the next error is

```
make: Entering directory '/home/rickardvonessen/src/ZXInterfaceZ/esp32/host'
cc -O2 -g -Wall -Wextra -DIDF_VER=\"0.1\" -I/home/linuxbrew/.linuxbrew/Cellar/glib/2.62.4/include/glib-2.0 -I/home/linuxbrew/.linuxbrew/Cellar/glib/2.62.4/lib/glib-2.0/include -I/home/linuxbrew/.linuxbrew/opt/gettext/include -I/home/linuxbrew/.linuxbrew/Cellar/pcre/8.43/include -I./FreeRTOS/Source//include -I./FreeRTOS/Source//portable/GCC/Linux -I./FreeRTOS/ -Iesplayer -Icjson -I. -I../main/ -I/home/rickardvonessen/src/esp-idf//components/esp_system/include/ -I/home/rickardvonessen/src/esp-idf//components/soc/soc/esp32/include/ -I/home/rickardvonessen/src/esp-idf//components/esp_common/include/ -I/home/rickardvonessen/src/esp-idf//components/spi_flash/include/ -I/home/rickardvonessen/src/esp-idf//components/soc/include/ -I/home/rickardvonessen/src/esp-idf//components/esp_event/include/ -I/home/rickardvonessen/src/esp-idf//components/esp_wifi/include/ -I/home/rickardvonessen/src/esp-idf//components/esp_timer/include/ -I/home/rickardvonessen/src/esp-idf//components/fatfs/vfs/ -I/home/rickardvonessen/src/esp-idf//components/fatfs/src/ -I/home/rickardvonessen/src/esp-idf//components/wear_levelling/include/ -I/home/rickardvonessen/src/esp-idf//components/esp_netif/include/ -I/home/rickardvonessen/src/esp-idf//components/esp_eth/include/ -I/home/rickardvonessen/src/esp-idf//components/spiffs/include/ -I/home/rickardvonessen/src/esp-idf//components/mbedtls/mbedtls/include -I/home/rickardvonessen/src/esp-idf//components/app_update/include/ -I/home/rickardvonessen/src/esp-idf//components/bootloader_support/include/ -I/home/rickardvonessen/src/esp-idf//components/esp_http_client/include/ -I/home/rickardvonessen/src/esp-idf//components/esp_http_server/include/ -I/home/rickardvonessen/src/esp-idf//components/esp_http_server/src/port/esp32 -I/home/rickardvonessen/src/esp-idf//components/esp_http_server/src/util -I/home/rickardvonessen/src/esp-idf//components/nghttp/port/include/ -I/home/rickardvonessen/src/esp-idf//components/nvs_flash/include/ -I/home/rickardvonessen/src/esp-idf//components/tcpip_adapter/include/ -I/home/rickardvonessen/src/esp-idf//components/driver/include/   -c -o /home/rickardvonessen/src/esp-idf//components/esp_http_server/src/httpd_ws.o /home/rickardvonessen/src/esp-idf//components/esp_http_server/src/httpd_ws.c
/home/rickardvonessen/src/esp-idf//components/esp_http_server/src/httpd_ws.c:18:24: fatal error: sys/random.h: No such file or directory
compilation terminated.
<builtin>: recipe for target '/home/rickardvonessen/src/esp-idf//components/esp_http_server/src/httpd_ws.o' failed
make: *** [/home/rickardvonessen/src/esp-idf//components/esp_http_server/src/httpd_ws.o] Error 1
make: Leaving directory '/home/rickardvonessen/src/ZXInterfaceZ/esp32/host'
```

I tried adding `-I$(ESP_IDF)/components/newlib/platform_include` but that gives a slev of new errors.

alvieboy, 2020-06-25:
"sys/random.h" is a libc header, but for i386 architecture.
Let me see if I can add one to the "esplayer" folder.

alvieboy, 2020-06-25:
Can you check if it works now ? I think we don't need the random implementation, so I just added the header

rickard-von-essen, 2020-06-25:
Yes, now it compiles and starts up, thanks!

Closed 2020-06-25.

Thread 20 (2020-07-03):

VGA/Audio adaptor hardware issues

alvieboy, 2020-07-03:
A few issues have been spotted with the included VGA/Audio adapter in revision 2.2.

* The audio jack is too close to the VGA connector, making it impossible to connect both at same time except with a very narrow male jack.
* The ESP32 causes voltage drops on the 3.3V line whenever it transmits, and this causes the buffers to output lower than expected voltages, leading to audible noise on the audio output.

alvieboy, 2020-12-09:
New boards ordered.

alvieboy, 2020-12-20:
Prototypes arrived.

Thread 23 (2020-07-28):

Feature: TAP/TZX recording of external tape

alvieboy, 2020-07-28:
Allow recording of external tapes (connected via spectrum EAR) to TAP or TZX.

rickard-von-essen, 2020-07-28:
Would this also work for microdrive programs to, or would it require something more?

alvieboy, 2020-07-28:
> Would this also work for microdrive programs to, or would it require something more?

I never used a microdrive. Do you have information on what actually gets saved in there ? Anyway, I think we can sort out some way to do that, should not be that complex.

alvieboy, 2021-03-22:
More information:
In order to be able to capture tape data, the FPGA should, at every IO read of the ULA port made by the ZX Spectrum, analyse the EAR input and record it. If the value differs from the previous captured EAR, the T-state difference to the previous change and the EAR value shall be stored in a suitable FIFO, in order for the data to be ready by the ESP32 via the regular SPI channel. An interrupt line should notify CPU that we have data to read.
There should be a means to enable/disable capturing of data (i.e. a currenlty unused REG32 bit).
There should be an upper and lower limit on the T-state, but this is reserved for future implementation because it implies adding a not so easy to implement filter.
T-states (high or low) for a given frequency are: 35555555/(2*freq)
Each T-State is ~3.5555Mhz, ~281.25ns.
Upper limit at 20KHz 50% duty cycle is 88 T-states
Lower limit at 60Hz 50% duty cicle is 29629 T-states.

Suggest storing the delta as a 15-bit unsigned value (0 to 32767) and the 16th bit as the EAR value. If no change, then delta shall be all ones.

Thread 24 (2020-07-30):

Feature: HDMI output

rickard-von-essen, 2020-07-30:
It would be great to have audio/video output via HDMI. It's a more future prof connection than VGA + Analog audio.

rickard-von-essen, 2020-07-30:
Some useful information:

HDMI implementation on a FPGA

https://www.fpga4fun.com/HDMI.html

alvieboy, 2020-07-30:
The FPGA we use does not have SERDES blocks, so the speed is quite limited (should top at 300Mbps), which is not much for HDMI. Note that signals are 10b encoded, so for 300Mpbs you have at max a 30Mhz bit clock. Asides from that, the IO standard is not supported, so it would need to be adapted from LVDS (which is tricky without external ICs - maybe AC coupling works, have to test).
I took some care in choosing signals on the expansion connector so that there are 4 differential pairs in there. Plan is to do some experiments and see if we can get an accepted/stable output.

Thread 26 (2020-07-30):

Feature: Kempston joystick interfaces

rickard-von-essen, 2020-07-30:
Support 2x DSUB 9-pin Kempston  (Port 31) joystick interfaces. It is possible to support 2 fire buttons and to have a small amount
of power available on pins 5 and 7 for joysticks that require it (EG: Megadrive pads).

alvieboy, 2020-07-30:
Plan is to have a small Kempston2USB adaptor. I already started work on that. We don't have room currently on the board, those connectors do take quite some space.

Example, with a standard USB connector (the big square one).

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

alvieboy, 2020-12-09:
Prototype USB board ordered.

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

alvieboy, 2021-03-23:
Rev 1 of the board is produced and working.

Closed 2021-03-23.

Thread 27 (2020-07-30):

Feature: add diagnostics ROM

rickard-von-essen, 2020-07-30:
Add a diagnostics ROM that can be automatically loaded via a button or by enable it in the web interface etc. To allow the IfZ to be used to diagnose Spectrums with hardware issues.

Retroleum's Diagnostics ROM:

http://blog.retroleum.co.uk/electronics-articles/a-diagnostic-rom-image-for-the-zx-spectrum/

alvieboy, 2020-07-30:
I'm working on the new RAM/ROM layout so we can support multiple roms easily (8k, 16k and 32k).

rickard-von-essen, 2020-07-31:
And some features from the _Multiface_ carts like pokes and

> Multifaces contained an extra 8 kilobytes of RAM that could be used by specially written software. Examples of such software included Genie,[5] a machine code disassembler, and Lifeguard,[5] a program for analysing the memory of a game during play in order to identify which memory locations should be changed to aid cheating.

https://en.wikipedia.org/wiki/Multiface

alvieboy, 2020-08-11:
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

Now, leaving the ROM is the hardest part. Will sort it out.
The ROM was loaded via command-line using a ROM file in the SD card.

rickard-von-essen, 2020-08-11:
Great work.

alvieboy, 2020-08-11:
For manual execution, we may need some way to trigger this ROM via the push buttons. Any ideas ? We have two user buttons - one is used for NMI, the other is unused. I'd suggest a long keypress (like 2secs) would trigger execution of a diagnostics ROM.

rickard-von-essen, 2020-08-11:
Yes, it would be great if the diag rom was stored on the flash chip. Long press USR? That should be fine, would that in practice mean long press USR and then hit reset?

Tailzer, 2021-03-15:
Could you detect usr button held at power on like the Dandanator does?

rickard-von-essen, 2021-03-15:
> Could you detect usr button held at power on like the Dandanator does?

Currently it's implemted by holding IOB more than 2 seconds. Is there any reason USR at power on/reset would be better? :thinking_face:

rickard-von-essen, 2021-03-15:
Closing since this is already implemented.

Tailzer, 2021-03-15:
No only just frees the long press for other functions in the future,
plugging in for diagnostics is something that would nearly always be
associated with power on?
Great project, watching with interest!

On Mon, 15 Mar 2021 at 19:04, Rickard von Essen ***@***.***>
wrote:

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

alvieboy, 2021-03-16:
The idea is that this could be configurable in the future. In fact, plan is to be able to confugure short/long presses on the board buttons and support long presses on joystick/keypad buttons/USB keyboards as well.  All these should map to a user-configurable action.
@Tailzer I could in theory add such a press-on-reset behaviour for one of the buttons, but I want to reserve the press-on-reset on at least one of them for the purpose of "factory reset".

Closed 2021-03-15.

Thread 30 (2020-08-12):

esp32: make flash is missing resource.bin target

rickard-von-essen, 2020-08-12:
In the `esp32/Makefile` target `flash` depends on `resource.bin`.

```
$ make resource.bin
Toolchain path: /home/rickardvonessen/.espressif/tools/xtensa-esp32-elf/esp-2020r2-8.2.0/xtensa-esp32-elf/bin/xtensa-esp32-elf-gcc
Toolchain version: esp-2020r2
Compiler version: 8.2.0
Python requirements from /home/rickardvonessen/src/esp-idf/requirements.txt are satisfied.
make: *** No rule to make target 'resource.bin'.  Stop
```

alvieboy, 2020-08-13:
That one is not used any more, removing it.

alvieboy, 2020-08-13:
Should be fixed now

Closed 2020-08-13.

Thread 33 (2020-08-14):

Improved Wifi management

rickard-von-essen, 2020-08-14:
Some things to make handling wifi easier :

- [ ] Allow setup of wifi from the menu and see the status.
- [ ] Log DHCP leases/renewals on the serial consol
- [ ] Use mDNS to broadcast a name
- [ ] Allows mgmt and see status on the web page

alvieboy, 2020-08-15:
Some of these are partially implemented, like wifi menu, but hidden at this stage.
I think it's probably better to split this issue to better manage the changes.

rickard-von-essen, 2020-08-15:
I'll split them up. 👍

alvieboy, 2020-08-15:
Don't you want to pick up this one ? I think most JSON is already there.

rickard-von-essen, 2020-08-15:
Yes, I can work on this next week.

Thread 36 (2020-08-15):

WIP: Use mDNS to broadcast a name

rickard-von-essen, 2020-08-15:
Currently not working

alvieboy, 2020-08-15:
Yes, it's rather unclear why it does not work. I'll have to dig inside the TCP/IP layer.

rickard-von-essen, 2020-08-15:
I can also have a look at tomorrow. Is this enablade by default or do I have to change anything?

alvieboy, 2020-08-15:
its enabled and I think properly set up. But MDNS requests seem to not reach the mDNS code. See mdns_* calls in "wifi.c"

Closed 2020-09-07.

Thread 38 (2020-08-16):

VGA: Add small overlay support

alvieboy, 2020-08-16:
Add small overlay support for suitable video modes. This overlay should be a framebuffer with some sort of alpha channel.

The current video RAM capture memory is 8192 bytes.  6912 bytes are needed for the Spectrum framebuffer, leaving 1280 bytes available for the overlay.
Using RGB332 (8bpp) we can have either:
- 160x8
- 128x10
- 106x12

For alpha support. it should eventually be fixed or a color with alpha shall be defined for the background only.

The framebuffer shall only be accessible by ESP32, not spectrum.

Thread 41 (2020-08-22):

esp32/host: Makefile referse to files in QtSpecem but it's empty

rickard-von-essen, 2020-08-22:
Seems like there are some missing files in `esp32/host/QtSpecem`

Also shouldn't `qmake --qt=5` be `qmake-qt5`?

Closed 2020-08-23.

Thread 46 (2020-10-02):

Loose microUSB connector

alvieboy, 2020-10-02:
The current surface-mount microUSB can easily become loose from the board. Convert it into a through-hole (mixed) part for robustness,

rickard-von-essen, 2020-10-13:
I have used these https://www.aliexpress.com/item/33010624211.html?spm=a2g0s.9042311.0.0.784c4c4dwSaRp1
Which seems similar to the two micro connectors.

alvieboy, 2020-10-14:
They all look similar, but they have small, important, differences. I'll have to choose one in the upcoming days.
The second problem with those sockets is that they require plated slots, which are not a standard PCB feature, and are easy to miss by the manufacturer.

alvieboy, 2021-03-16:
Working well on r2.4.

Closed 2021-03-16.

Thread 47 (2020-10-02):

Power supply compatibility for +2A/+3

alvieboy, 2020-10-02:
Power supply needs changing because +2A/+3 do not use +9V rail. Power through +5V is +9V is not available.

alvieboy, 2020-12-09:
Powering the board via the +5V rail line introduces a huge amount of interference in the video/audio modulator.
However, powering the board via the +12V line on +2A/+3 seems to work ok. A new circuitry will be added to HW version 2.4 to autoswitch between +9V and +12V.

alvieboy, 2021-03-16:
Implemented in r2.4, autoswitch seems to be working properly.

Closed 2021-03-16.

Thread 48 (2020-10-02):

nWAIT line

alvieboy, 2020-10-02:
Currently nWAIT line is not driven, but we need to use it for simultaneous RAM access by the ESP32 and spectrum. A driver for this line should be added and connected to FPGA.

alvieboy, 2020-12-09:
Working with HW 2.3. Closing.

Closed 2020-12-09.

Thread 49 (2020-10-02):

romCS line for +2A/+3

alvieboy, 2020-10-02:
+2A/+3 spectrums have an extra ROMCS line present on the connector A15. This pin is also used for video out on other models. Allow this line to be driven low by the FPGA.

alvieboy, 2020-12-09:
Working with HW 2.3. Closing.

Closed 2020-12-09.

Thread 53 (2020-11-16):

API: /req/devlist returns no devices

rickard-von-essen, 2020-11-16:
Even if there are USB devices connected.

alvieboy, 2020-11-17:
I am redesigning the internal communication on the FPGA due to some "lost" USB transactions, which I suspect might affect detection of USB devices sometimes.
Still, might be the list itself, not sure I am filling any data so far. Still, I will need to discuss with you how the USB devices can be configured (and how data is stored).

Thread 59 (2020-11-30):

esp32/host/FreeRTOS and esp32/host/freertos clashes on case insensitive filesystem (macOS)

rickard-von-essen, 2020-11-30:
If you case insensitive filesystem (macOS, Windows 10) you get problems checking out this repo. Maybe we can rename the link `freertos` a bit.

alvieboy, 2020-11-30:
Yeah, let me try to fix that.

alvieboy, 2020-12-03:
Care to check if https://github.com/alvieboy/ZXInterfaceZ/commit/522a470d2575fe94059bcf7ae336bc0d4c23d538 fixed it?

rickard-von-essen, 2020-12-04:
Looks good 👍

Closed 2020-12-04.

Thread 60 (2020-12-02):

/WAIT de-assertion on CLK-less Spectrums

alvieboy, 2020-12-02:
Some spectrums (notably some early toastrack) do not route the CLK signal to the expansion connector, however we currently rely on CLK for de-assertion of the WAIT signal for proper synchronization.
To be investigated. Might need a DPLL in order to generate a fake clock signal we can use.

alvieboy, 2020-12-09:
We now rely on delaying the WAIT signal so it can be captured. Fullly fixed in 97fbb03634f068a2f5446e5f8dcf22619bf58cad. Closing.

Closed 2020-12-09.

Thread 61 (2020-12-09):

SD card: switch to pull-pull

alvieboy, 2020-12-09:
Switch to pull-pull SD card socket.

P/N: Molex 503398-1892

alvieboy, 2021-03-16:
Working well on R2.4 prototype.

Closed 2021-03-16.

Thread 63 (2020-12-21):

Pressing the USR button while in the Menu hangs the Spectrum

rickard-von-essen, 2020-12-21:
Entering the menu with `USR` and then pressing `USR` again hangs the Spectrum. (Reset works)

alvieboy, 2020-12-21:
It should not reassert NMI until we exit the NMI handler, so something might be broken. This is handled by the FPGA. Will inspect

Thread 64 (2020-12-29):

Hardware: MP2233DJ is marked "Obsolete"

alvieboy, 2020-12-29:
MP2233DJ (the IC used for the power supplies) is now marked as Obsolete by LCSC. The part is still available on Mouser, but stock is relatively low, and price a bit high (we need two per board).
Alternatives should be found in antecipation of the IC leaving market.

alvieboy, 2021-01-26:
Considering AP62250

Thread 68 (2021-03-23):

Support saving screenshots to SD card

rickard-von-essen, 2021-03-23:
Support grabbing the screen content, either with the USR menu (omitting the menu) or using a custom key on a USB connected device. Save the screen to a predefined path either on the SD Card or a USB mass storage device.

rickard-von-essen, 2021-03-23:
i'm guessing there is no realtime clock so we probably need to keep a counter and use it in the filename. (`/sdcard/screenshoot/interfacez-scr-0001.png`)

alvieboy, 2021-03-23:
This is intimately linked to the quick snapshot feature.
My idea for the file naming is to in a first instance (i.e., first activation after a ZX Spectrum reset [not Interface Z reset]) to present a file chooser dialog where you can select the directory and the file name template (which will be "preloaded" if you have since loaded a tape, but you can edit it freely). Then, auto increment counters will be used for the file name (incrementing until there is a free "slot" for the file, so you don't overwrite old snapshots. The template itself can either be hardcoded (selectedname-XXXX.ext) or manually input in the future.

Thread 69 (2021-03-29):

HW: Support generation of CPU clock

alvieboy, 2021-03-29:
Add support for generating the CPU clock. This is useful to run spectrums without ULA. As per schematics, the CK pin is connected to the base of a transistor driver.

Use a buffer/inverter with OE control to drive the CK line with 5V logic.
This may require freeing up a few FPGA pins. Suggestion is:
- Disconnect USB_SUSPEND and tie the PHY suspend to 0. We don't use it at the moment.
- Redirect USB_FLT into an unused CLK input pin. Synthesis tests show this is possible.

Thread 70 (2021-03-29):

Hardware: move ZX Spectrum connector forward

alvieboy, 2021-03-29:
The current placement for the ZX Spectrum connector is good if no case is used. If we place the board in a case, it's difficult to fully insert the interface into the ZX Spectrum.

Move the connector 3mm outwards. This should allow for the interface to completely insert into the expansion connector.

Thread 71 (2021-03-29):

Hardware: place block of LEDs 5mm apart

alvieboy, 2021-03-29:
The current rightmost LED area has the LEDs quite close to each other, which makes it difficult to have openings on the case.

Separate the LEDs by 5mm. This will ensure proper clearance.

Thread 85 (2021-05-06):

Firmware update modifications

alvieboy, 2021-05-06:
Multiple enhancements shall be provided for firmware update:
a) Change the web firmware update so we can report status progress back. This should be done via web socket instead of POST, however POST shall still be supported for fallback.
b) Add a digest/checksum/crc to each individual file on the firmware file, so it can be checked.
c) In case we know that parts of the firmware are wrong (most notably /spiffs), use a fallback spiffs with a simple web interface for firmware upload.
d) Ensure the spiffs is the correct version by adding the build tag to a root file which can be checked on power-up.
e) The validity for spifss shall be stored in the nvram, invalidated when we start the process, and only validated after we check all digests/checksums/crc

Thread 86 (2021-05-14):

host: use pthread primitives directly, instead of Linux FreeRTOS port.

alvieboy, 2021-05-14:
FreeRTOS task switching signals can interfer with OS locking, most notably stdio. It's rather difficult to ensure both working without locking down the application.

So a separate OS layer shall be implemented, which will map to FreeRTOS primitives directly on the board, but differently on host mode, using only plain pthread primitives. The disadvantage is we lose control of priorities, but this is deemed acceptable.

For compatibility reasons while compiling host mode, the FreeRTOS primitive calls shall also be mapped to pthread calls.

To speed up the system, after the layer is operating propelry, the communication between the sytstem and the Z80 emulator shall be switched to the direct method, instead of the pipe+HDLC we are using right now - the performance difference will be very noticeable.

Closed 2021-07-18.

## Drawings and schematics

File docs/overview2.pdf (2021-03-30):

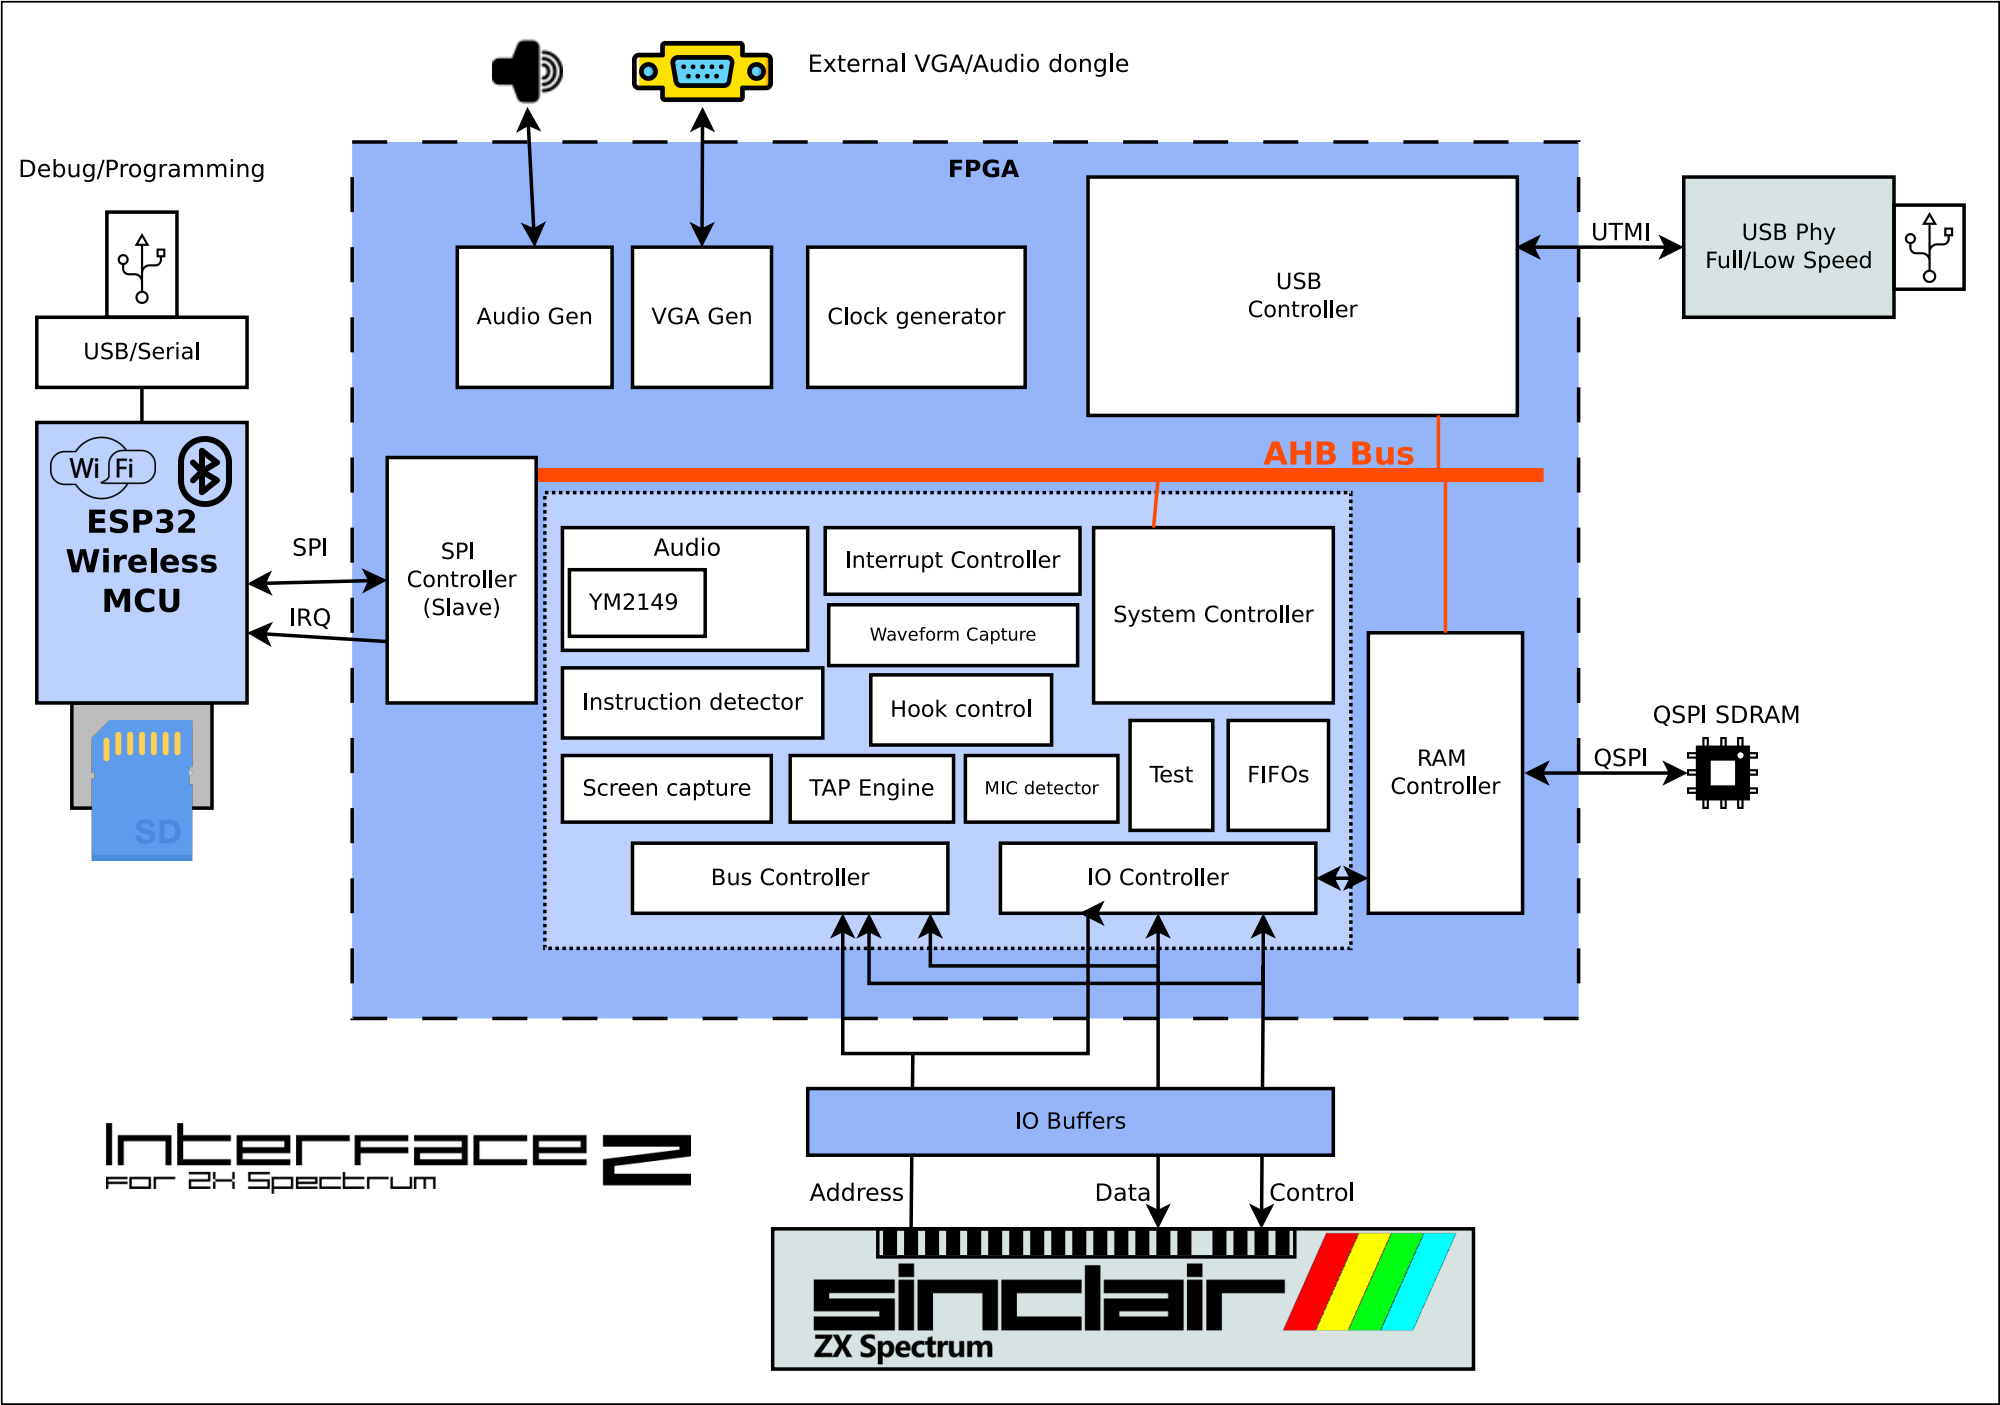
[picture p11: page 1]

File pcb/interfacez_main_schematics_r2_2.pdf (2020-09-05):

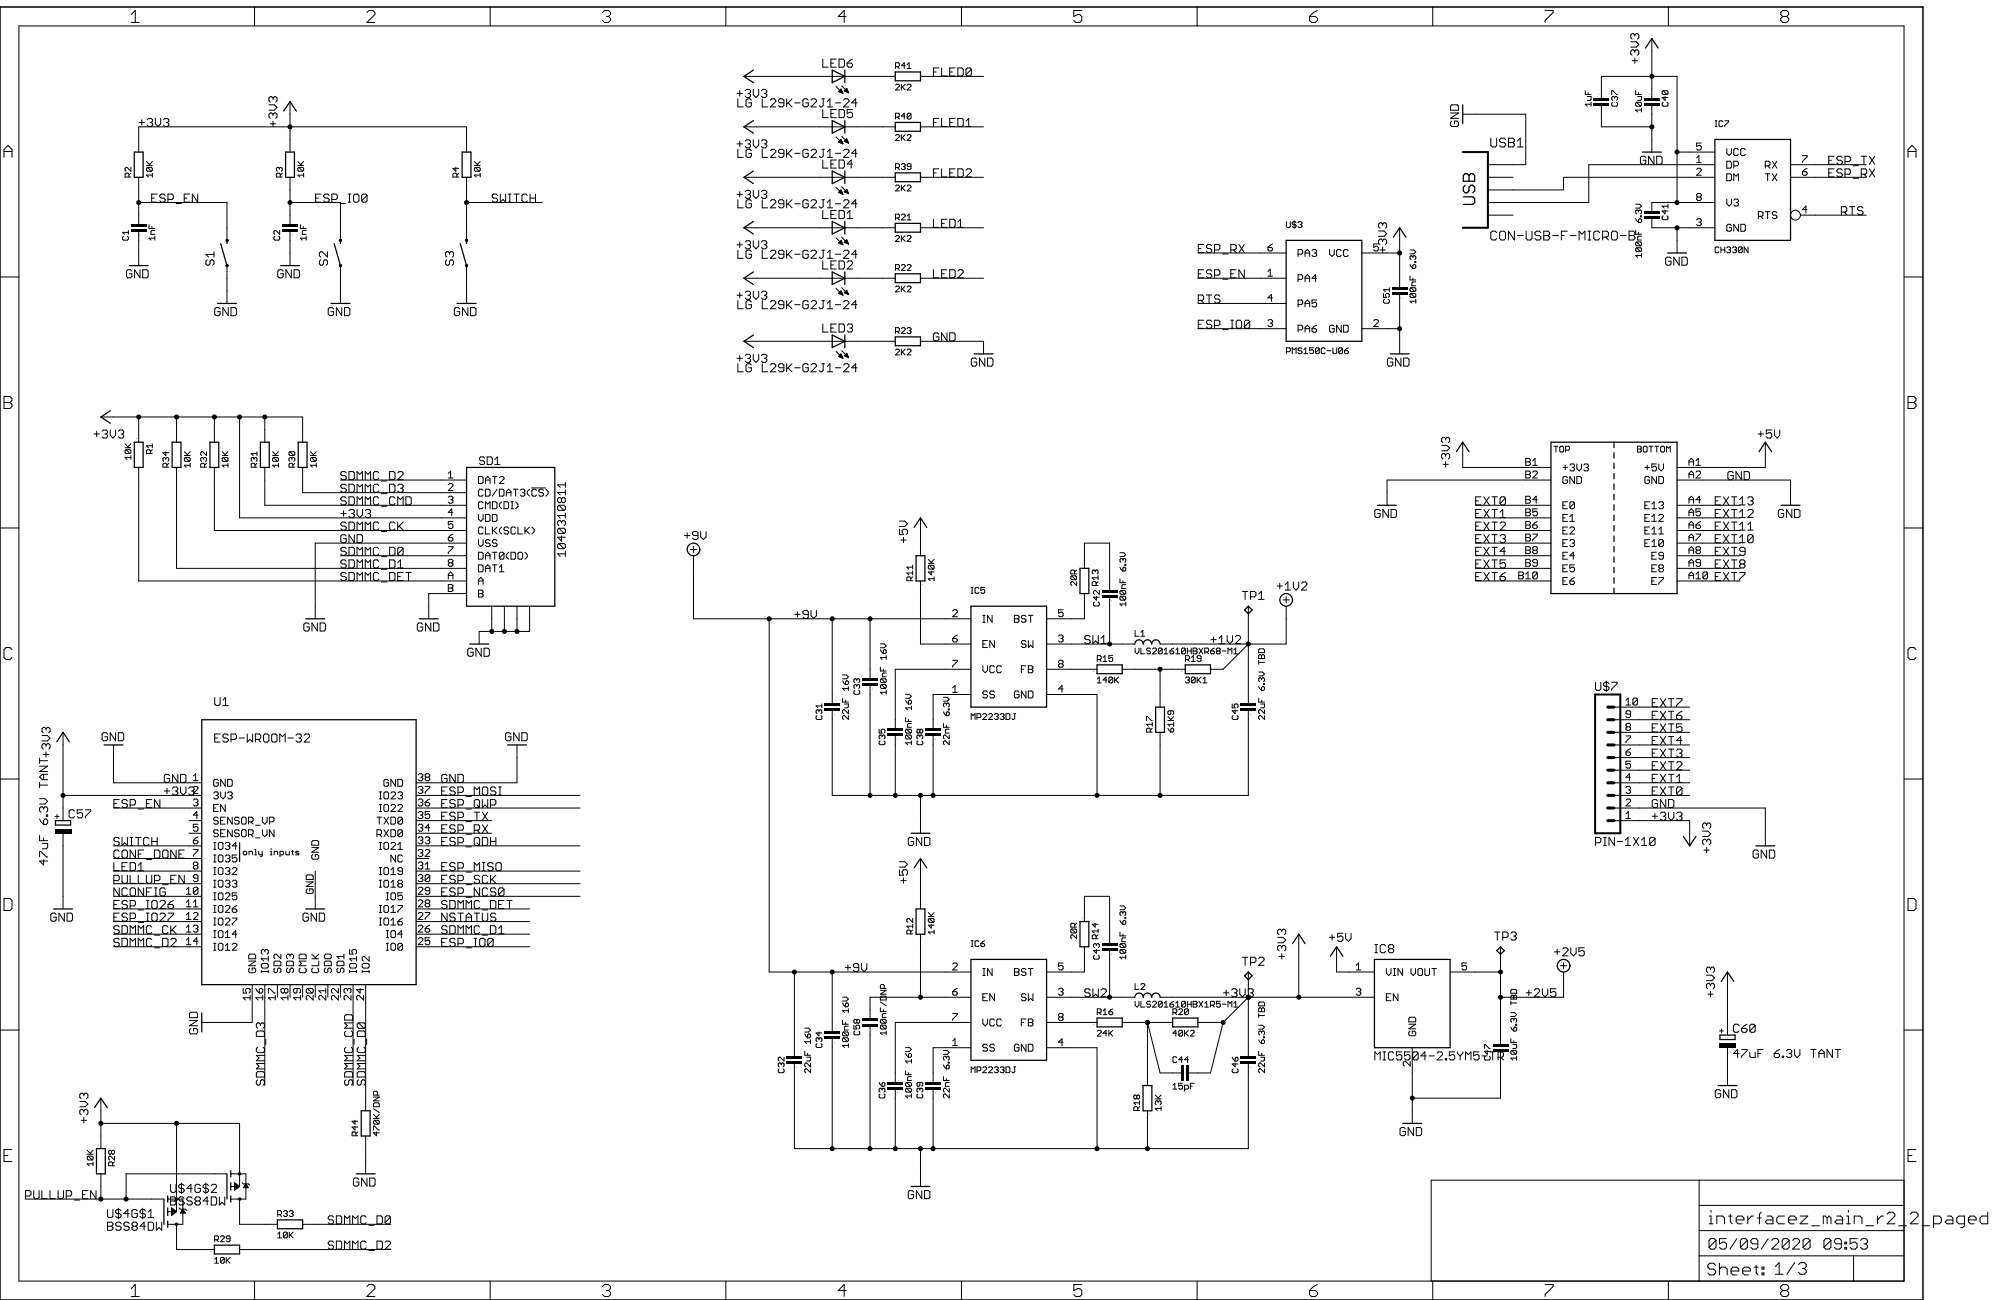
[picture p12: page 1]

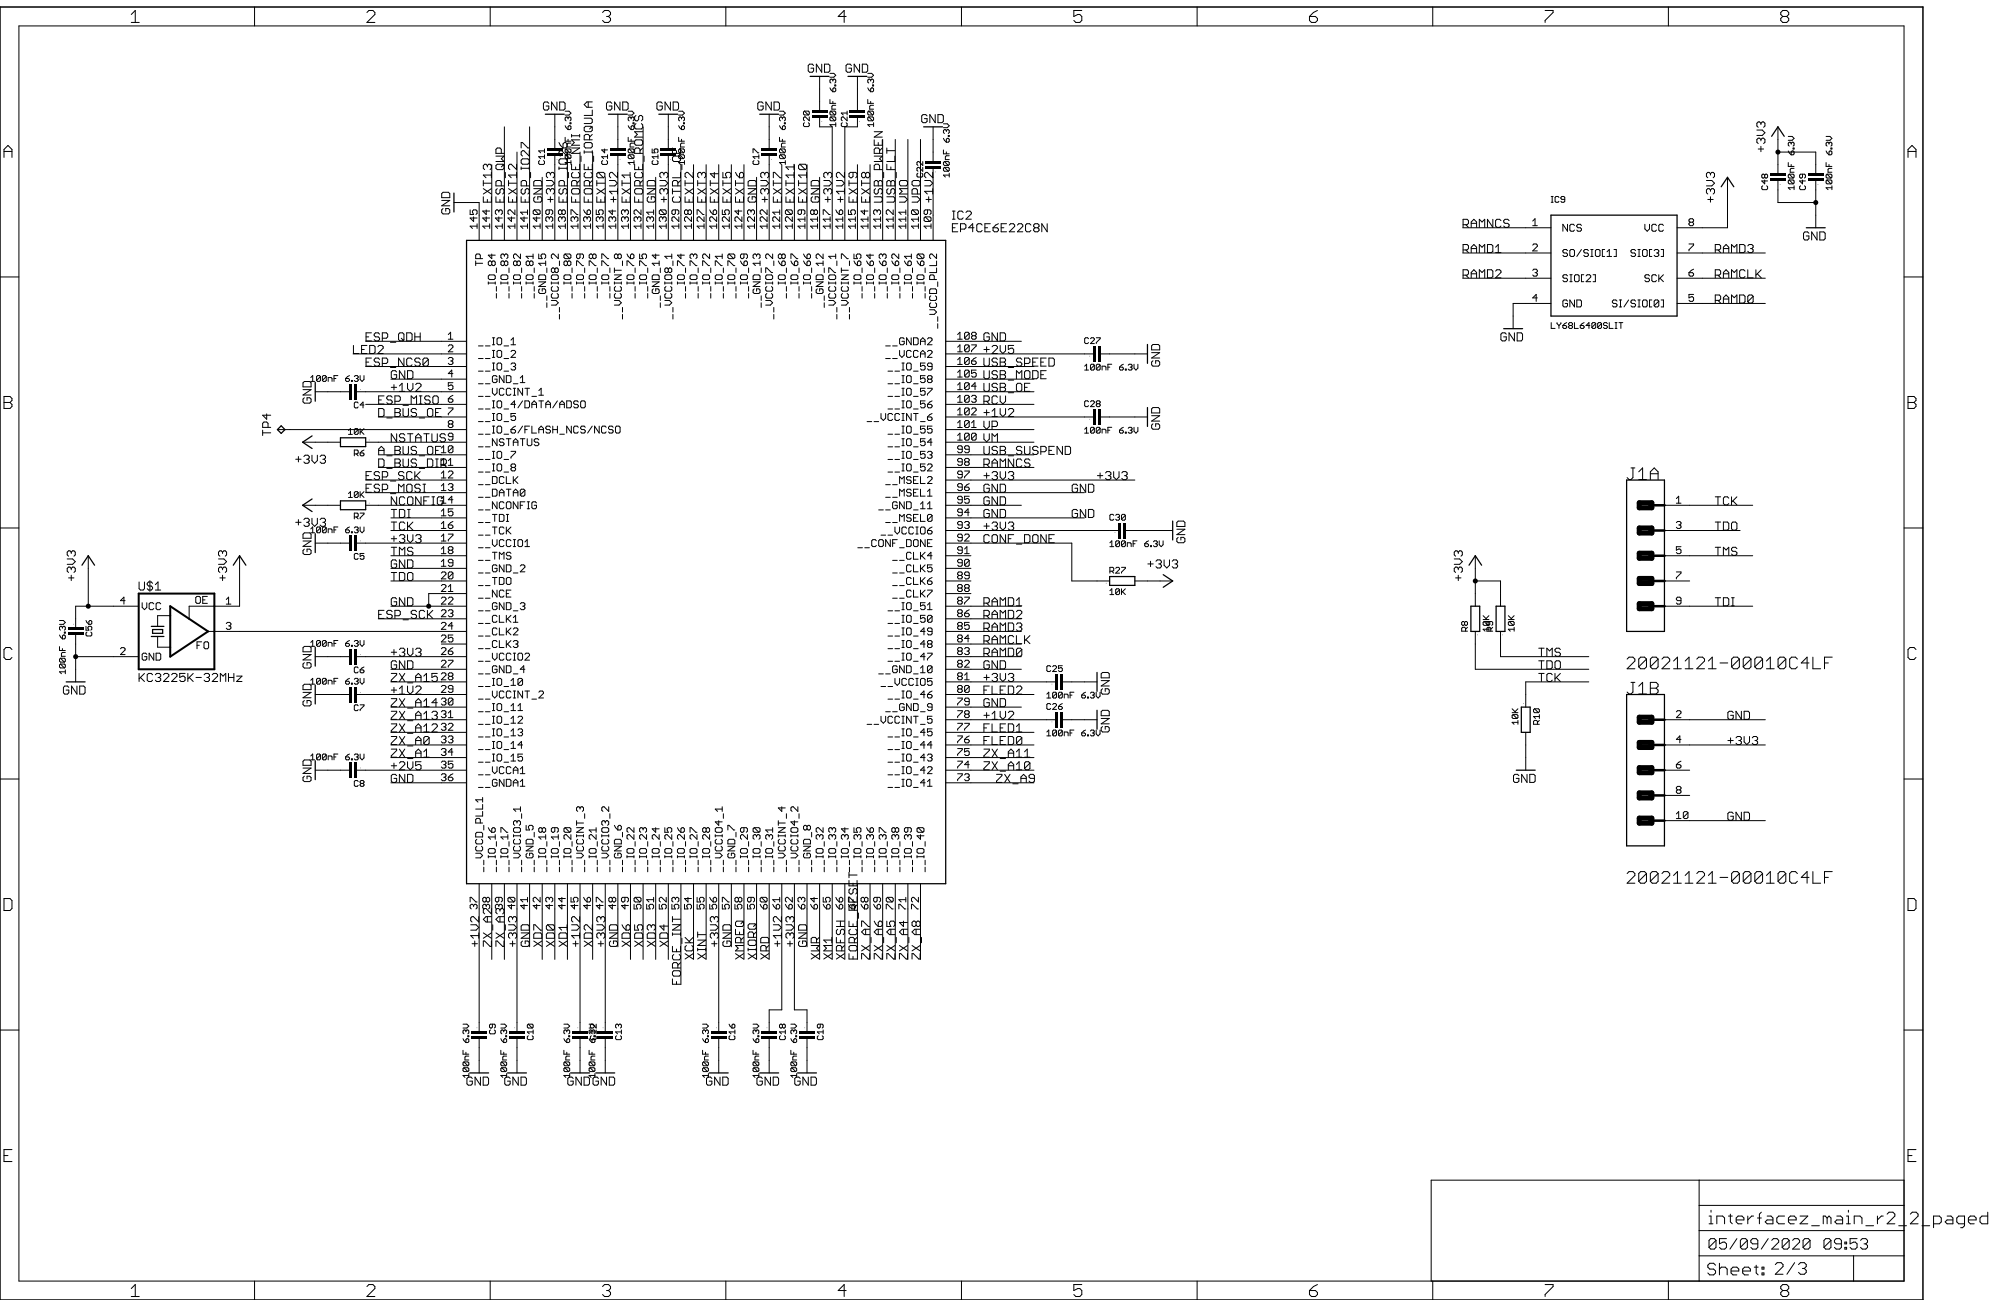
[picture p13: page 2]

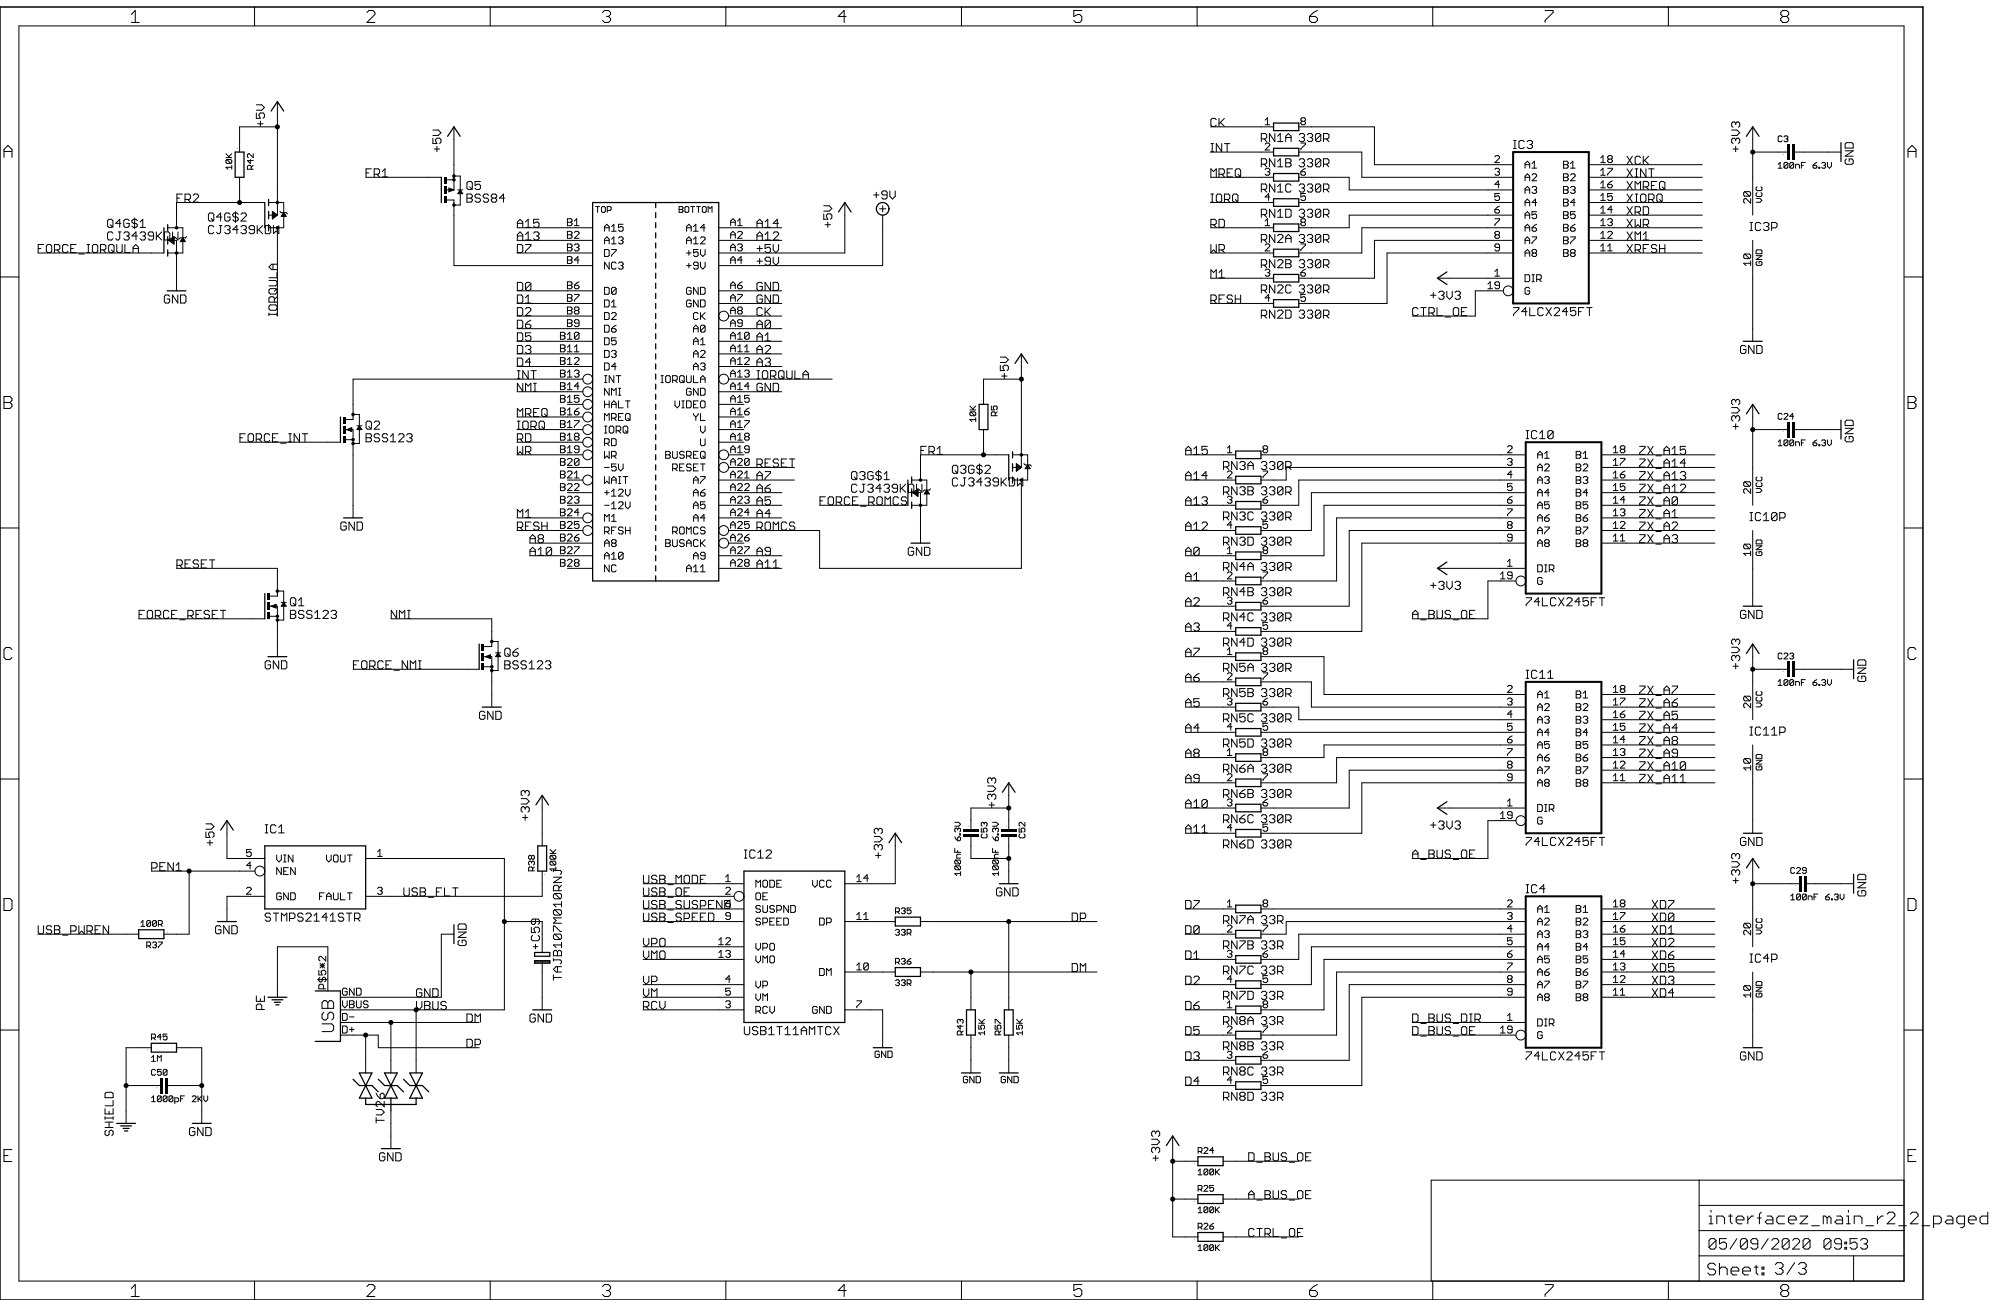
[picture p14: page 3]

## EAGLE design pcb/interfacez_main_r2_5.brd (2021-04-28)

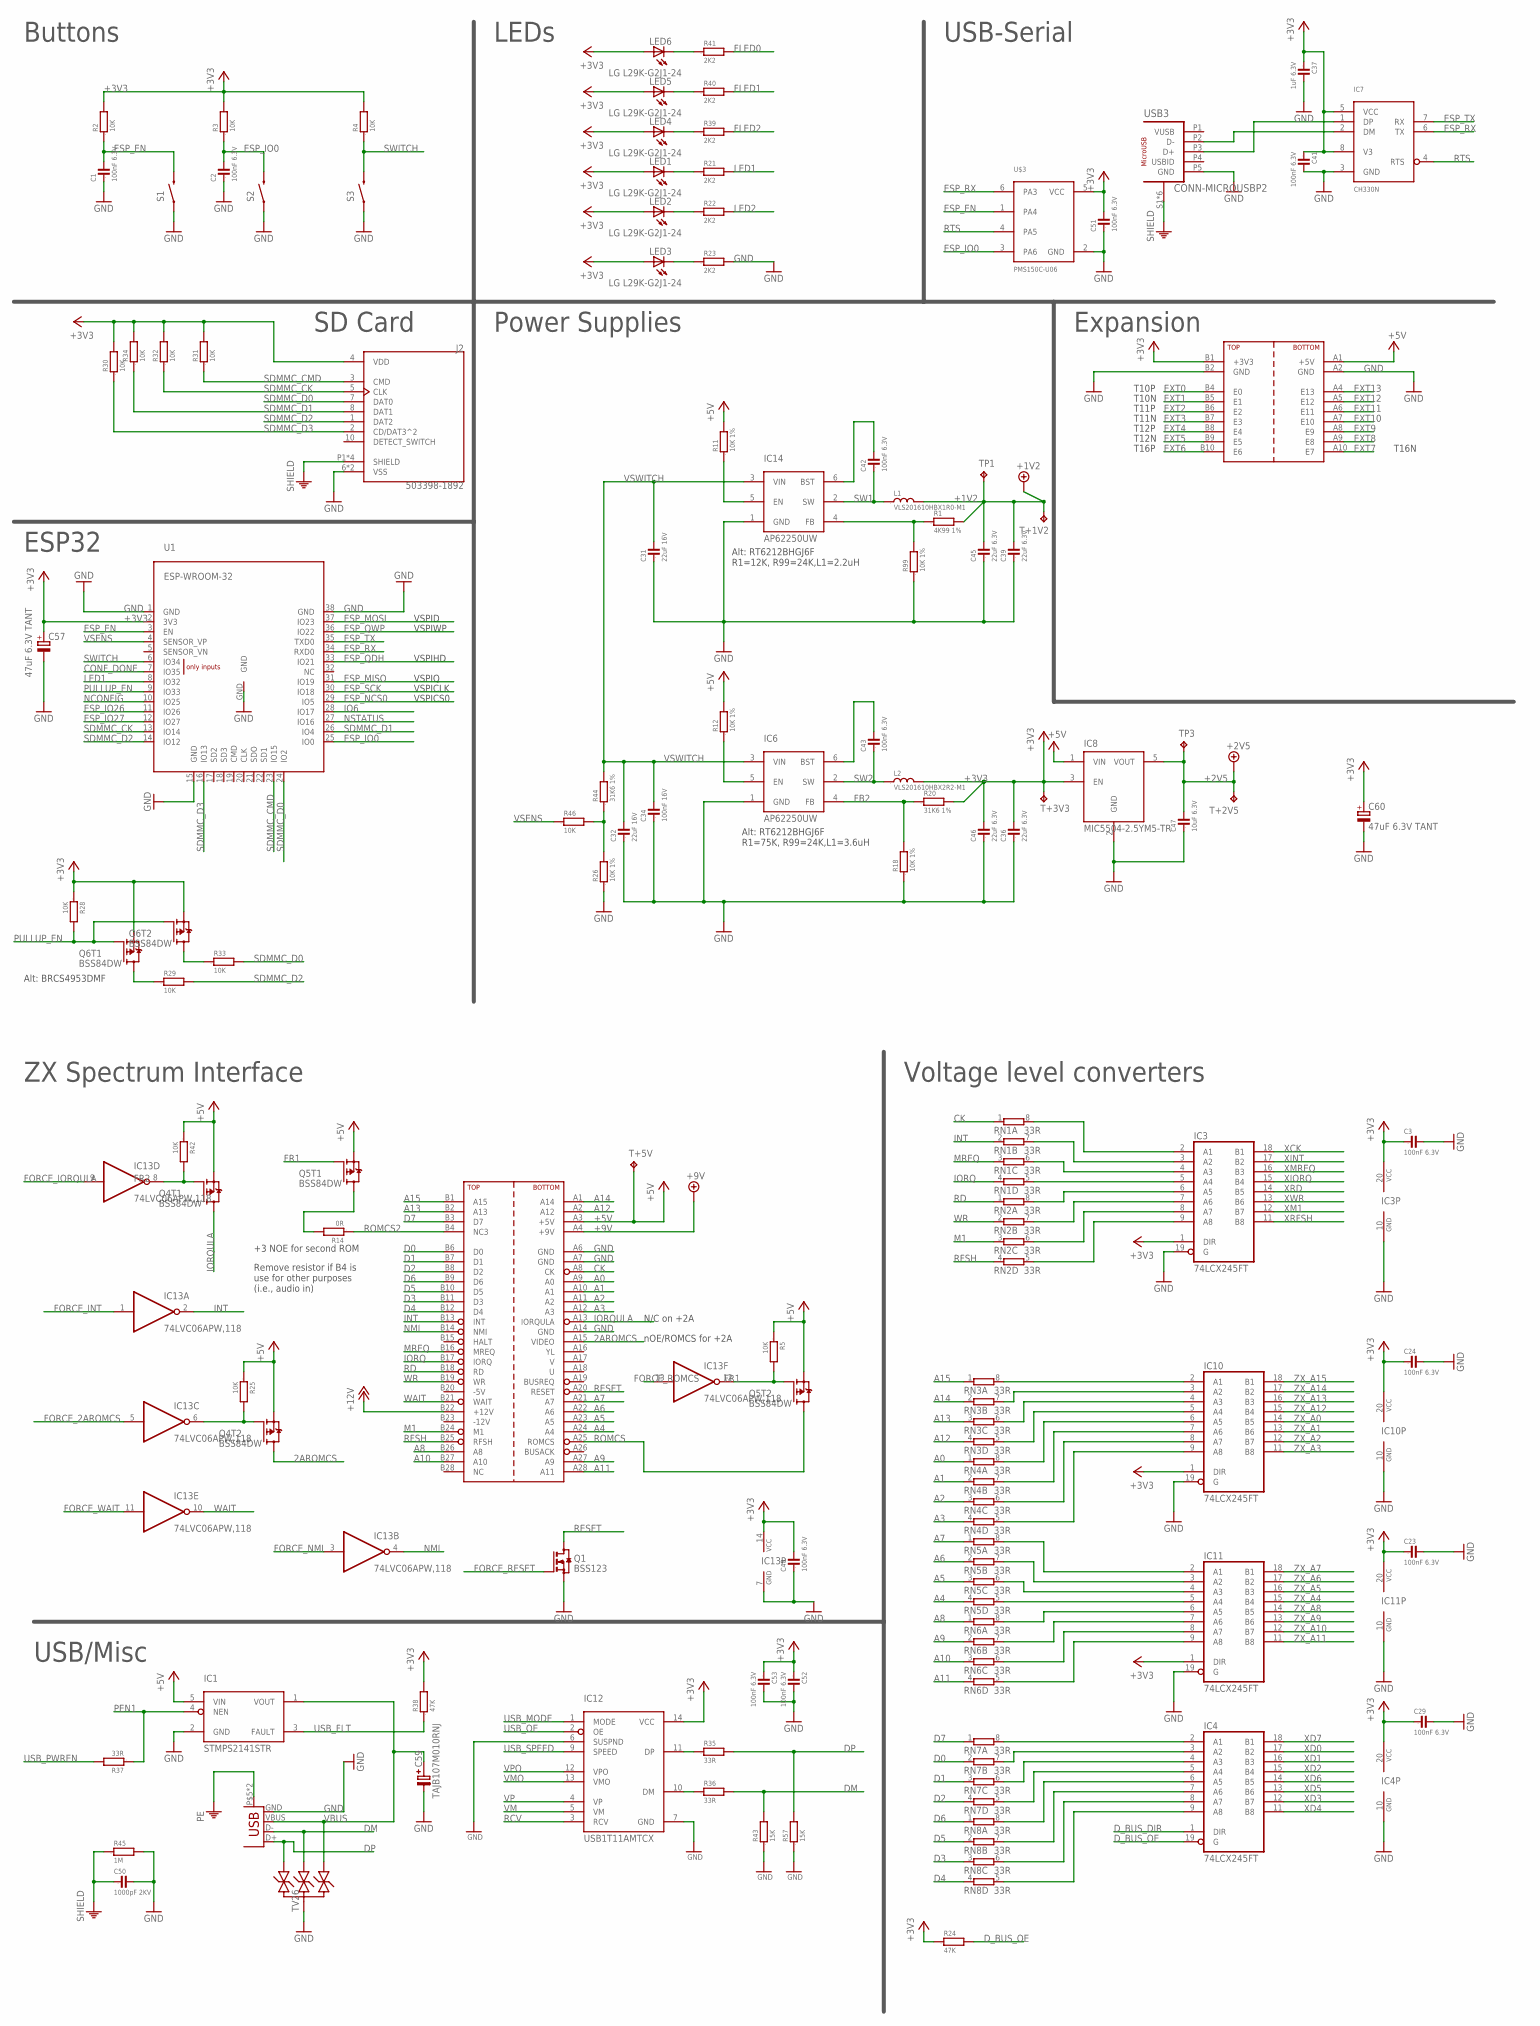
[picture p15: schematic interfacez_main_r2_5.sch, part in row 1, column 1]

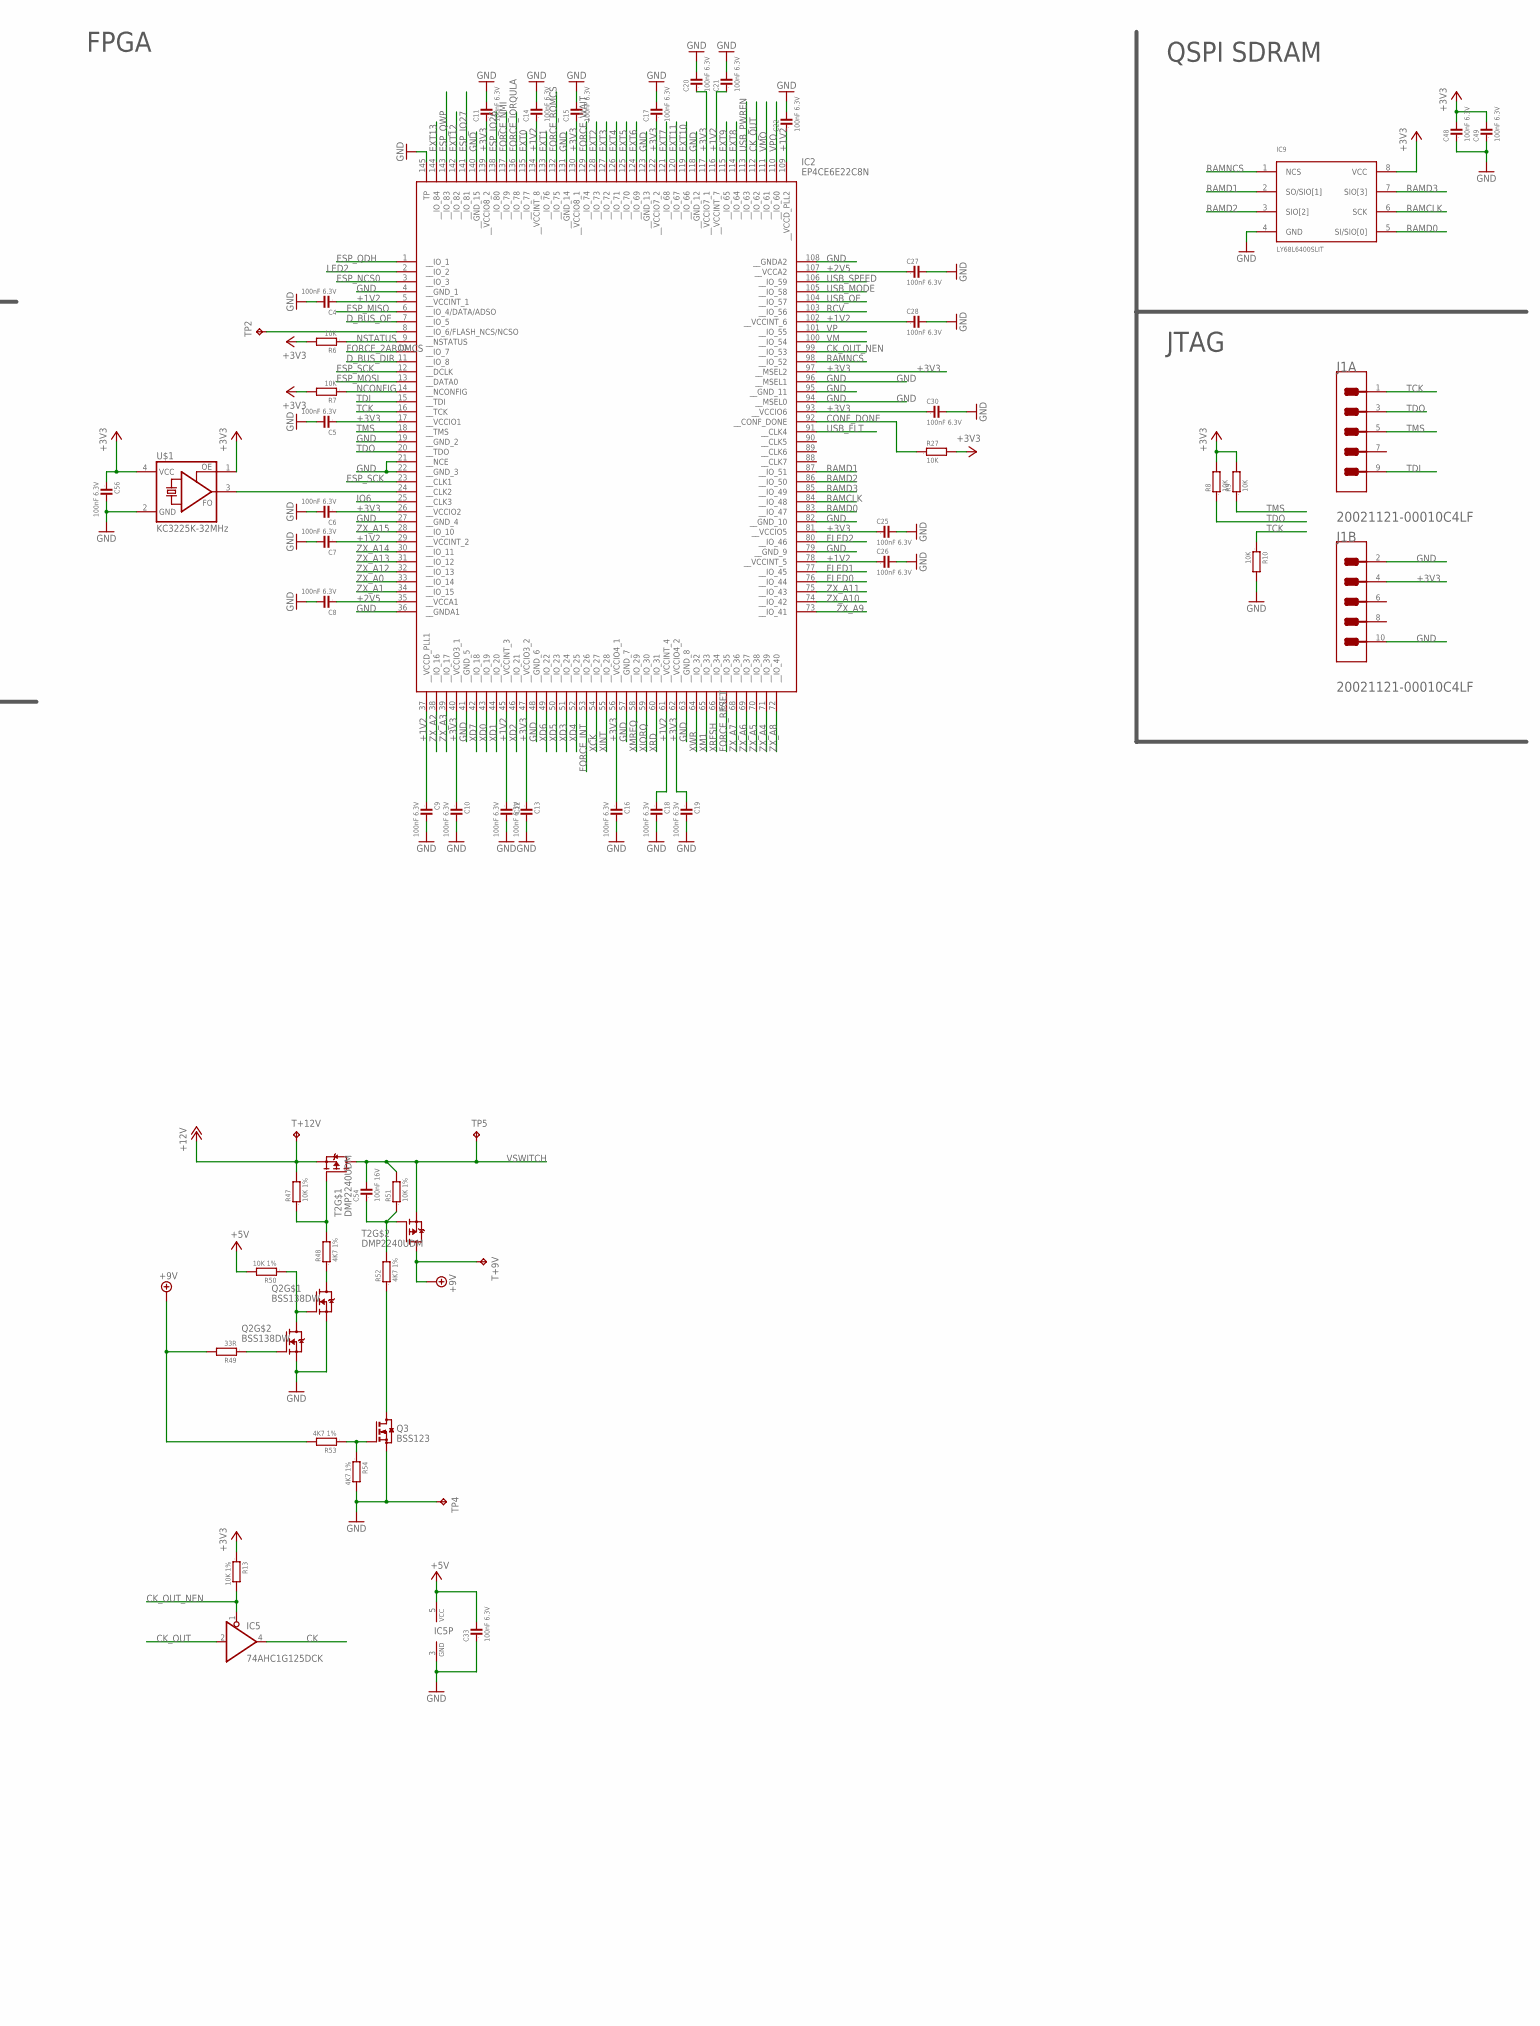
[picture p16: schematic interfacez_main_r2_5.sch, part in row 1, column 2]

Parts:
C1, C2, C3, C4, C5, C6, C7, C8, C9, C10, C11, C12, C13, C14, C15, C16, C17, C18, C19, C20, C21, C22, C23, C24, C25, C26, C27, C28, C29, C30, C33, C40, C41, C42, C43, C48, C49, C51, C52, C53, C56: 100nF 6.3V; 0603
C31, C32: 22uF 16V; 1210
C34, C54: 100nF 16V; 0603
C36, C39, C45, C46: 22uF 6.3V; 0805
C37: 1uF 6.3V; 0603
C47: 10uF 6.3V; 0805
C50: 1000pF 2KV; 1210
C57, C60: 47uF 6.3V TANT; TANT_CASE_A
C59: TAJB107M010RNJ; TE-B-3528
CONN1: ZX_EDGE_DAUGHTERBOARD; ZX-EDGE-DAUGHTERBOARD
IC1: STMPS2141STR; SOT23-5L
IC2: EP4CE6E22C8N; QFP50P2200X2200X165-145N
IC3, IC4, IC10, IC11: 74LCX245FT; TSSOP20
IC5: 74AHC1G125DCK; SC70-5
IC6, IC14: AP62250UW; SOT23-6
IC7: CH330N; SOIC8
IC8: MIC5504-2.5YM5-TR; SOT23-5L
IC9: LY68L6400SLIT; SOIC8
IC12: USB1T11AMTCX; TSSOP14
IC13: 74LVC06APW,118; TSSOP14
J1: AMPHENOL_ICC_-_FCI_20021121-00010C4LFAMPHENOL_ICC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; AMPHENOL_ICC_-_FCI_20021121-00010C4LF_0
J2: 503398-1892; MOLEX_503398-1892
L1: VLS201610HBX1R0-M1; IND_0806
L2: VLS201610HBX2R2-M1; IND_0806
LED1, LED2, LED3, LED4, LED5, LED6: LG L29K-G2J1-24; LED-603
Q1, Q3: BSS123; SOT23
Q2: BSS138DW; SOT363_INFINEON
Q4, Q5, Q6: BSS84DW; SOT363_INFINEON
R1: 4K99 1%; 0603
R2, R3, R4, R5, R6, R7, R8, R9, R10, R25, R27, R28, R29, R30, R31, R32, R33, R34, R42, R46: 10K; 0603
R11, R12, R13, R18, R26, R47, R50, R51, R99: 10K 1%; 0603
R14: 0R; 0603
R20, R44: 31K6 1%; 0603
R21, R22, R23, R39, R40, R41: 2K2; 0603
R24, R38: 47K; 0603
R35, R36, R37, R49: 33R; 0603
R43, R57: 15K; 0603
R45: 1M; 0805
R48, R52, R53, R54: 4K7 1%; 0603
RN1, RN2, RN3, RN4, RN5, RN6, RN7, RN8: 33R; EXB28V
S1, S2, S3: SWITCHES_SMD-4; TACTILE_SWITCH_TALL
T2: DMP2240UDM; SOT23-6
T+1V2, T+2V5, T+3V3, T+5V, T+9V, T+12V: TPTP12SQ; TP12SQ
TP1, TP3: TPTP12R; TP12R
TP2, TP5: TPTP12SQ; TP12SQ
TP4: TPPAD1-13; P1-13
TV26: SP0503BAHT; SP0503
U1: ESP-WROOM-32
U$1: KC3225K-32MHz; KC3225K
U$3: PMS150C-U06; SOT23-6
U$5: INTERFACEZ_EDGEDAUGHTER; INTERFACEZ_EXPANSION_DAUGHTERCARD
USB2: USB-A-H
USB3: CONN-MICROUSBP2; MICROUSB_SMD_TH_7.5MM_4.85MM

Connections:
2AROMCS: CONN1.A15 (VIDEO), Q4.6 (D)
+1V2: C4.1, C7.1, C9.1, C12.1, C14.1, C18.1, C21.1, C22.1, C26.1, C28.1, C39.2, C45.2, IC2.5 (__VCCINT_1), IC2.29 (__VCCINT_2), IC2.37 (__VCCD_PLL1), IC2.45 (__VCCINT_3), IC2.61 (__VCCINT_4), IC2.78 (__VCCINT_5), IC2.102 (__VCCINT_6), IC2.109 (__VCCD_PLL2), IC2.116 (__VCCINT_7), IC2.134 (__VCCINT_8), L1.P$2 (2), R1.2, T+1V2.TP, TP1.TP
+2V5: C8.1, C27.1, C47.2, IC2.35 (__VCCA1), IC2.107 (__VCCA2), IC8.5 (VOUT), T+2V5.TP, TP3.TP
+3V3: C3.1, C5.1, C6.1, C10.1, C11.1, C13.1, C15.1, C16.1, C17.1, C19.1, C20.1, C23.1, C24.1, C25.1, C29.1, C30.1, C36.2, C37.1, C40.2, C41.1, C46.2, C48.2, C49.2, C51.2, C52.1, C53.1, C56.1, C57.PLUS (+), C60.PLUS (+), IC2.17 (__VCCIO1), IC2.26 (__VCCIO2), IC2.40 (__VCCIO3_1), IC2.47 (__VCCIO3_2), IC2.56 (__VCCIO4_1), IC2.62 (__VCCIO4_2), IC2.81 (__VCCIO5), IC2.93 (__VCCIO6), IC2.97 (__MSEL2), IC2.117 (__VCCIO7_1), IC2.122 (__VCCIO7_2), IC2.130 (__VCCIO8_1), IC2.139 (__VCCIO8_2), IC3.1 (DIR), IC3.20 (VCC), IC4.20 (VCC), IC7.5 (VCC), IC7.8 (V3), IC8.3 (EN), IC9.8 (VCC), IC10.1 (DIR), IC10.20 (VCC), IC11.1 (DIR), IC11.20 (VCC), IC12.14 (VCC), IC13.14 (VCC), J1.4, J2.4 (VDD), L2.P$2 (2), LED1.A, LED2.A, LED3.A, LED4.A, LED5.A, LED6.A, Q6.1 (S), Q6.4 (S), R2.2, R3.2, R4.2, R6.2, R7.2, R8.2, R9.2, R13.1, R20.2, R24.1, R27.2, R28.1, R30.2, R31.2, R32.2, R34.2, R38.2, T+3V3.TP, U1.2 (3V3), U$1.1 (OE), U$1.4 (VCC), U$3.5 (VCC), U$5.B1 (+3V3)
+5V: C33.2, CONN1.A3 (+5V), IC1.5 (VIN), IC5.5 (VCC), IC8.1 (VIN), Q4.1 (S), Q4.4 (S), Q5.1 (S), Q5.4 (S), R5.1, R11.2, R12.2, R25.1, R42.1, R50.2, T+5V.TP, U$5.A1 (+5V)
+9V: CONN1.A4 (+9V), R49.2, R53.2, T2.4 (D), T+9V.TP
+12V: CONN1.B22 (+12V), R47.2, T2.5 (S), T+12V.TP
-5V: CONN1.B20 (-5V)
-12V: CONN1.B23 (-12V)
A0: CONN1.A9 (A0), RN4.1
A1: CONN1.A10 (A1), RN4.2 (1)
A2: CONN1.A11 (A2), RN4.3 (1)
A3: CONN1.A12 (A3), RN4.4 (1)
A4: CONN1.A24 (A4), RN5.4 (1)
A5: CONN1.A23 (A5), RN5.3 (1)
A6: CONN1.A22 (A6), RN5.2 (1)
A7: CONN1.A21 (A7), RN5.1
A8: CONN1.B26 (A8), RN6.1
A9: CONN1.A27 (A9), RN6.2 (1)
A10: CONN1.B27 (A10), RN6.3 (1)
A11: CONN1.A28 (A11), RN6.4 (1)
A12: CONN1.A2 (A12), RN3.4 (1)
A13: CONN1.B2 (A13), RN3.3 (1)
A14: CONN1.A1 (A14), RN3.2 (1)
A15: CONN1.B1 (A15), RN3.1
CK: CONN1.A8 (CK), IC5.4 (O), RN1.1
CK_OUT: IC2.112 (__IO_62), IC5.2 (I)
CK_OUT_NEN: IC2.99 (__IO_53), IC5.1 (OE), R13.2
CONF_DONE: IC2.92 (__CONF_DONE), R27.1, U1.7 (IO35)
D0: CONN1.B6 (D0), RN7.2 (1)
D1: CONN1.B7 (D1), RN7.3 (1)
D2: CONN1.B8 (D2), RN7.4 (1)
D3: CONN1.B11 (D3), RN8.3 (1)
D4: CONN1.B12 (D4), RN8.4 (1)
D5: CONN1.B10 (D5), RN8.2 (1)
D6: CONN1.B9 (D6), RN8.1
D7: CONN1.B3 (D7), RN7.1
DM: R36.2, R43.2, TV26.3 (B), USB2.D-
DP: R35.2, R57.2, TV26.2 (A), USB2.D+
D_BUS_DIR: IC2.11 (__IO_8), IC4.1 (DIR)
D_BUS_OE: IC2.7 (__IO_5), IC4.19 (G), R24.2
ESP_EN: C1.2, R2.1, S1.B2 (2), U1.3 (EN), U$3.1 (PA4)
ESP_IO0: C2.2, R3.1, S2.B2 (2), U1.25 (IO0), U$3.3 (PA6)
ESP_IO26: IC2.138 (__IO_80), U1.11 (IO26)
ESP_IO27: IC2.141 (__IO_81), U1.12 (IO27)
ESP_MISO: IC2.6 (__IO_4/DATA/ADSO), U1.31 (IO19)
ESP_MOSI: IC2.13 (__DATA0), U1.37 (IO23)
ESP_NCS0: IC2.3 (__IO_3), U1.29 (IO5)
ESP_QDH: IC2.1 (__IO_1), U1.33 (IO21)
ESP_QWP: IC2.143 (__IO_83), U1.36 (IO22)
ESP_RX: IC7.6 (TX), U1.34 (RXD0), U$3.6 (PA3)
ESP_SCK: IC2.12 (__DCLK), IC2.23 (__CLK1), U1.30 (IO18)
ESP_TX: IC7.7 (RX), U1.35 (TXD0)
EXT0: IC2.135 (__IO_77), U$5.B4 (E0)
EXT1: IC2.133 (__IO_76), U$5.B5 (E1)
EXT2: IC2.128 (__IO_73), U$5.B6 (E2)
EXT3: IC2.127 (__IO_72), U$5.B7 (E3)
EXT4: IC2.126 (__IO_71), U$5.B8 (E4)
EXT5: IC2.125 (__IO_70), U$5.B9 (E5)
EXT6: IC2.124 (__IO_69), U$5.B10 (E6)
EXT7: IC2.121 (__IO_68), U$5.A10 (E7)
EXT8: IC2.114 (__IO_64), U$5.A9 (E8)
EXT9: IC2.115 (__IO_65), U$5.A8 (E9)
EXT10: IC2.119 (__IO_66), U$5.A7 (E10)
EXT11: IC2.120 (__IO_67), U$5.A6 (E11)
EXT12: IC2.142 (__IO_82), U$5.A5 (E12)
EXT13: IC2.144 (__IO_84), U$5.A4 (E13)
FB2: IC6.4 (FB), R18.2, R20.1
FLED0: IC2.76 (__IO_44), R41.2
FLED1: IC2.77 (__IO_45), R40.2
FLED2: IC2.80 (__IO_46), R39.2
FORCE_2AROMCS: IC2.10 (__IO_7), IC13.5 (I)
FORCE_INT: IC2.53 (__IO_26), IC13.1 (I)
FORCE_IORQULA: IC2.136 (__IO_78), IC13.9 (I)
FORCE_NMI: IC2.137 (__IO_79), IC13.3 (I)
FORCE_RESET: IC2.67 (__IO_35), Q1.1 (G)
FORCE_ROMCS: IC2.132 (__IO_75), IC13.13 (I)
FORCE_WAIT: IC2.129 (__IO_74), IC13.11 (I)
FR1: IC13.12 (O), Q5.2 (G), Q5.5 (G), R5.2
FR2: IC13.8 (O), Q4.5 (G), R42.2
GND: C1.1, C2.1, C3.2, C4.2, C5.2, C6.2, C7.2, C8.2, C9.2, C10.2, C11.2, C12.2, C13.2, C14.2, C15.2, C16.2, C17.2, C18.2, C19.2, C20.2, C21.2, C22.2, C23.2, C24.2, C25.2, C26.2, C27.2, C28.2, C29.2, C30.2, C31.1, C32.1, C33.1, C34.1, C36.1, C37.2, C39.1, C40.1, C41.2, C45.1, C46.1, C47.1, C48.1, C49.1, C50.2, C51.1, C52.2, C53.2, C56.2, C57.MINUS (-), C59.-, C60.MINUS (-), CONN1.A6 (GND), CONN1.A7 (GND), CONN1.A14 (GND), IC1.2 (GND), IC2.4 (__GND_1), IC2.19 (__GND_2), IC2.21 (__NCE), IC2.22 (__GND_3), IC2.27 (__GND_4), IC2.36 (__GNDA1), IC2.41 (__GND_5), IC2.48 (__GND_6), IC2.57 (__GND_7), IC2.63 (__GND_8), IC2.79 (__GND_9), IC2.82 (__GND_10), IC2.94 (__MSEL0), IC2.95 (__GND_11), IC2.96 (__MSEL1), IC2.108 (__GNDA2), IC2.118 (__GND_12), IC2.123 (__GND_13), IC2.131 (__GND_14), IC2.140 (__GND_15), IC2.145 (TP), IC3.10 (GND), IC3.19 (G), IC4.10 (GND), IC5.3 (GND), IC6.1 (GND), IC7.3 (GND), IC8.2 (GND), IC9.4 (GND), IC10.10 (GND), IC10.19 (G), IC11.10 (GND), IC11.19 (G), IC12.6 (SUSPND), IC12.7 (GND), IC13.7 (GND), IC14.1 (GND), J1.2, J1.10, J2.6 (VSS), J2.9 (VSS), Q1.2 (S), Q2.1 (S), Q2.4 (S), Q3.2 (S), R10.2, R18.1, R23.2, R26.1, R43.1, R45.2, R54.2, R57.1, R99.1, S1.A2 (1), S2.A2 (1), S3.A2 (1), TP4.TP, TV26.1 (COM), U1.1 (GND), U1.15 (GND), U1.38 (GND), U1.GND, U$1.2 (GND), U$3.2 (GND), U$5.A2 (GND), U$5.B2 (GND), USB2.GND, USB3.P5 (GND)
INT: CONN1.B13 (INT), IC13.2 (O), RN1.2 (1)
IO6: IC2.25 (__CLK3), U1.28 (IO17)
IORQ: CONN1.B17 (IORQ), RN1.4 (1)
IORQULA: CONN1.A13 (IORQULA), Q4.3 (D)
LED1: R21.2, U1.8 (IO32)
LED2: IC2.2 (__IO_2), R22.2
M1: CONN1.B24 (M1), RN2.3 (1)
MREQ: CONN1.B16 (MREQ), RN1.3 (1)
unnamed: Q5.3 (D), R14.2
unnamed: LED1.C, R21.1
unnamed: LED2.C, R22.1
unnamed: LED3.C, R23.1
unnamed: R47.1, R48.2, T2.1 (G)
unnamed: Q2.3 (D), R48.1
unnamed: IC3.2 (A1), RN1.8 (2)
unnamed: IC3.3 (A2), RN1.7 (2)
unnamed: IC10.2 (A1), RN3.8 (2)
unnamed: IC10.3 (A2), RN3.7 (2)
unnamed: IC10.4 (A3), RN3.6 (2)
unnamed: IC10.5 (A4), RN3.5 (2)
unnamed: IC2.24 (__CLK2), U$1.3 (FO)
unnamed: IC10.6 (A5), RN4.8 (2)
unnamed: IC10.7 (A6), RN4.7 (2)
unnamed: IC4.2 (A1), RN7.8 (2)
unnamed: IC4.3 (A2), RN7.7 (2)
unnamed: IC10.8 (A7), RN4.6 (2)
unnamed: IC2.8 (__IO_6/FLASH_NCS/NCSO), TP2.TP
unnamed: LED4.C, R39.1
unnamed: C43.2, IC6.6 (BST)
unnamed: IC10.9 (A8), RN4.5 (2)
unnamed: IC11.2 (A1), RN5.8 (2)
unnamed: IC11.3 (A2), RN5.7 (2)
unnamed: IC11.4 (A3), RN5.6 (2)
unnamed: IC11.5 (A4), RN5.5 (2)
unnamed: IC11.6 (A5), RN6.8 (2)
unnamed: IC11.7 (A6), RN6.7 (2)
unnamed: IC11.8 (A7), RN6.6 (2)
unnamed: IC11.9 (A8), RN6.5 (2)
unnamed: IC4.4 (A3), RN7.6 (2)
unnamed: IC4.5 (A4), RN7.5 (2)
unnamed: IC4.6 (A5), RN8.8 (2)
unnamed: IC4.7 (A6), RN8.7 (2)
unnamed: IC4.8 (A7), RN8.6 (2)
unnamed: IC4.9 (A8), RN8.5 (2)
unnamed: IC3.4 (A3), RN1.6 (2)
unnamed: IC3.5 (A4), RN1.5 (2)
unnamed: IC3.6 (A5), RN2.8 (2)
unnamed: IC3.7 (A6), RN2.7 (2)
unnamed: IC3.8 (A7), RN2.6 (2)
unnamed: IC3.9 (A8), RN2.5 (2)
unnamed: C42.2, IC14.6 (BST)
unnamed: IC6.5 (EN), R12.1
unnamed: IC14.4 (FB), R1.1, R99.2
unnamed: IC14.5 (EN), R11.1
unnamed: IC13.6 (O), Q4.2 (G), R25.2
unnamed: Q6.3 (D), R29.1
unnamed: LED5.C, R40.1
unnamed: LED6.C, R41.1
unnamed: IC12.11 (DP), R35.1
unnamed: IC12.10 (DM), R36.1
unnamed: Q2.5 (G), Q2.6 (D), R50.1
unnamed: Q6.6 (D), R33.1
unnamed: Q2.2 (G), R49.1
unnamed: C54.1, R51.1, R52.2, T2.3 (G)
unnamed: Q3.1 (G), R53.1, R54.1
unnamed: Q3.3 (D), R52.1
unnamed: IC7.1 (DP), USB3.P3 (D+)
unnamed: IC7.2 (DM), USB3.P2 (D-)
NCONFIG: IC2.14 (__NCONFIG), R7.1, U1.10 (IO25)
NMI: CONN1.B14 (NMI), IC13.4 (O)
NSTATUS: IC2.9 (__NSTATUS), R6.1, U1.27 (IO16)
PE: C50.1, J2.P1 (SHIELD), J2.P2 (SHIELD), J2.P3 (SHIELD), J2.P4 (SHIELD), R45.1, USB2.P$5 (SHIELD), USB2.P$6 (SHIELD), USB3.S1 (SHIELD), USB3.S2 (SHIELD), USB3.S3 (SHIELD), USB3.S4 (SHIELD), USB3.S5 (SHIELD), USB3.S6 (SHIELD)
PEN1: IC1.4 (NEN), R37.1
PULLUP_EN: Q6.2 (G), Q6.5 (G), R28.2, U1.9 (IO33)
RAMCLK: IC2.84 (__IO_48), IC9.6 (SCK)
RAMD0: IC2.83 (__IO_47), IC9.5 (SI/SIO[0])
RAMD1: IC2.87 (__IO_51), IC9.2 (SO/SIO[1])
RAMD2: IC2.86 (__IO_50), IC9.3 (SIO[2])
RAMD3: IC2.85 (__IO_49), IC9.7 (SIO[3])
RAMNCS: IC2.98 (__IO_52), IC9.1 (NCS)
RCV: IC2.103 (__IO_56), IC12.3 (RCV)
RD: CONN1.B18 (RD), RN2.1
RESET: CONN1.A20 (RESET), Q1.3 (D)
RFSH: CONN1.B25 (RFSH), RN2.4 (1)
ROMCS: CONN1.A25 (ROMCS), Q5.6 (D)
ROMCS2: CONN1.B4 (NC3), R14.1
RTS: IC7.4 (RTS), U$3.4 (PA5)
SDMMC_CK: J2.5 (CLK), R32.1, U1.13 (IO14)
SDMMC_CMD: J2.3 (CMD), R31.1, U1.23 (IO15)
SDMMC_D0: J2.7 (DAT0), R33.2, U1.24 (IO2)
SDMMC_D1: J2.8 (DAT1), R34.1, U1.26 (IO4)
SDMMC_D2: J2.1 (DAT2), R29.2, U1.14 (IO12)
SDMMC_D3: J2.2 (CD/DAT3^2), R30.1, U1.16 (IO13)
SW1: C42.1, IC14.2 (SW), L1.P$1 (1)
SW2: C43.1, IC6.2 (SW), L2.P$1 (1)
SWITCH: R4.1, S3.B2 (2), U1.6 (IO34)
TCK: IC2.16 (__TCK), J1.1, R10.1
TDI: IC2.15 (__TDI), J1.9
TDO: IC2.20 (__TDO), J1.3, R8.1
TMS: IC2.18 (__TMS), J1.5, R9.1
USB_FLT: IC1.3 (FAULT), IC2.91 (__CLK4), R38.1
USB_MODE: IC2.105 (__IO_58), IC12.1 (MODE)
USB_OE: IC2.104 (__IO_57), IC12.2 (OE)
USB_PWREN: IC2.113 (__IO_63), R37.2
USB_SPEED: IC2.106 (__IO_59), IC12.9 (SPEED)
VBUS: C59.+, IC1.1 (VOUT), TV26.4 (C), USB2.VBUS
VDIV: R26.2, R44.1, R46.2
VM: IC2.100 (__IO_54), IC12.5 (VM)
VMO: IC2.111 (__IO_61), IC12.13 (VMO)
VP: IC2.101 (__IO_55), IC12.4 (VP)
VPO: IC2.110 (__IO_60), IC12.12 (VPO)
VSENS: R46.1, U1.4 (SENSOR_VP)
VSWITCH: C31.2, C32.2, C34.2, C54.2, IC6.3 (VIN), IC14.3 (VIN), R44.2, R51.2, T2.2 (S), T2.6 (D), TP5.TP
WAIT: CONN1.B21 (WAIT), IC13.10 (O)
WR: CONN1.B19 (WR), RN2.2 (1)
XCK: IC2.54 (__IO_27), IC3.18 (B1)
XD0: IC2.43 (__IO_19), IC4.17 (B2)
XD1: IC2.44 (__IO_20), IC4.16 (B3)
XD2: IC2.46 (__IO_21), IC4.15 (B4)
XD3: IC2.51 (__IO_24), IC4.12 (B7)
XD4: IC2.52 (__IO_25), IC4.11 (B8)
XD5: IC2.50 (__IO_23), IC4.13 (B6)
XD6: IC2.49 (__IO_22), IC4.14 (B5)
XD7: IC2.42 (__IO_18), IC4.18 (B1)
XINT: IC2.55 (__IO_28), IC3.17 (B2)
XIORQ: IC2.59 (__IO_30), IC3.15 (B4)
XM1: IC2.65 (__IO_33), IC3.12 (B7)
XMREQ: IC2.58 (__IO_29), IC3.16 (B3)
XRD: IC2.60 (__IO_31), IC3.14 (B5)
XRFSH: IC2.66 (__IO_34), IC3.11 (B8)
XWR: IC2.64 (__IO_32), IC3.13 (B6)
ZX_A0: IC2.33 (__IO_14), IC10.14 (B5)
ZX_A1: IC2.34 (__IO_15), IC10.13 (B6)
ZX_A2: IC2.38 (__IO_16), IC10.12 (B7)
ZX_A3: IC2.39 (__IO_17), IC10.11 (B8)
ZX_A4: IC2.71 (__IO_39), IC11.15 (B4)
ZX_A5: IC2.70 (__IO_38), IC11.16 (B3)
ZX_A6: IC2.69 (__IO_37), IC11.17 (B2)
ZX_A7: IC2.68 (__IO_36), IC11.18 (B1)
ZX_A8: IC2.72 (__IO_40), IC11.14 (B5)
ZX_A9: IC2.73 (__IO_41), IC11.13 (B6)
ZX_A10: IC2.74 (__IO_42), IC11.12 (B7)
ZX_A11: IC2.75 (__IO_43), IC11.11 (B8)
ZX_A12: IC2.32 (__IO_13), IC10.15 (B4)
ZX_A13: IC2.31 (__IO_12), IC10.16 (B3)
ZX_A14: IC2.30 (__IO_11), IC10.17 (B2)
ZX_A15: IC2.28 (__IO_10), IC10.18 (B1)

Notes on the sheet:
Buttons
SD Card
ESP32
LEDs
USB-Serial
Power Supplies
FPGA
QSPI SDRAM
ZX Spectrum Interface
Voltage level converters
USB/Misc
VSPICLK
VSPICS0
VSPIQ
VSPIWP
VSPIHD
VSPID
+3 NOE for second ROM
Alt: BRCS4953DMF
Expansion
T10P
T10N
T11P
T11N
T12P
T12N
T16P
T16N
JTAG
N/C on +2A
nOE/ROMCS for +2A
Remove resistor if B4 is use for other purposes (i.e., audio in)
Alt: RT6212BHGJ6F R1=12K, R99=24K,L1=2.2uH
Alt: RT6212BHGJ6F R1=75K, R99=24K,L1=3.6uH

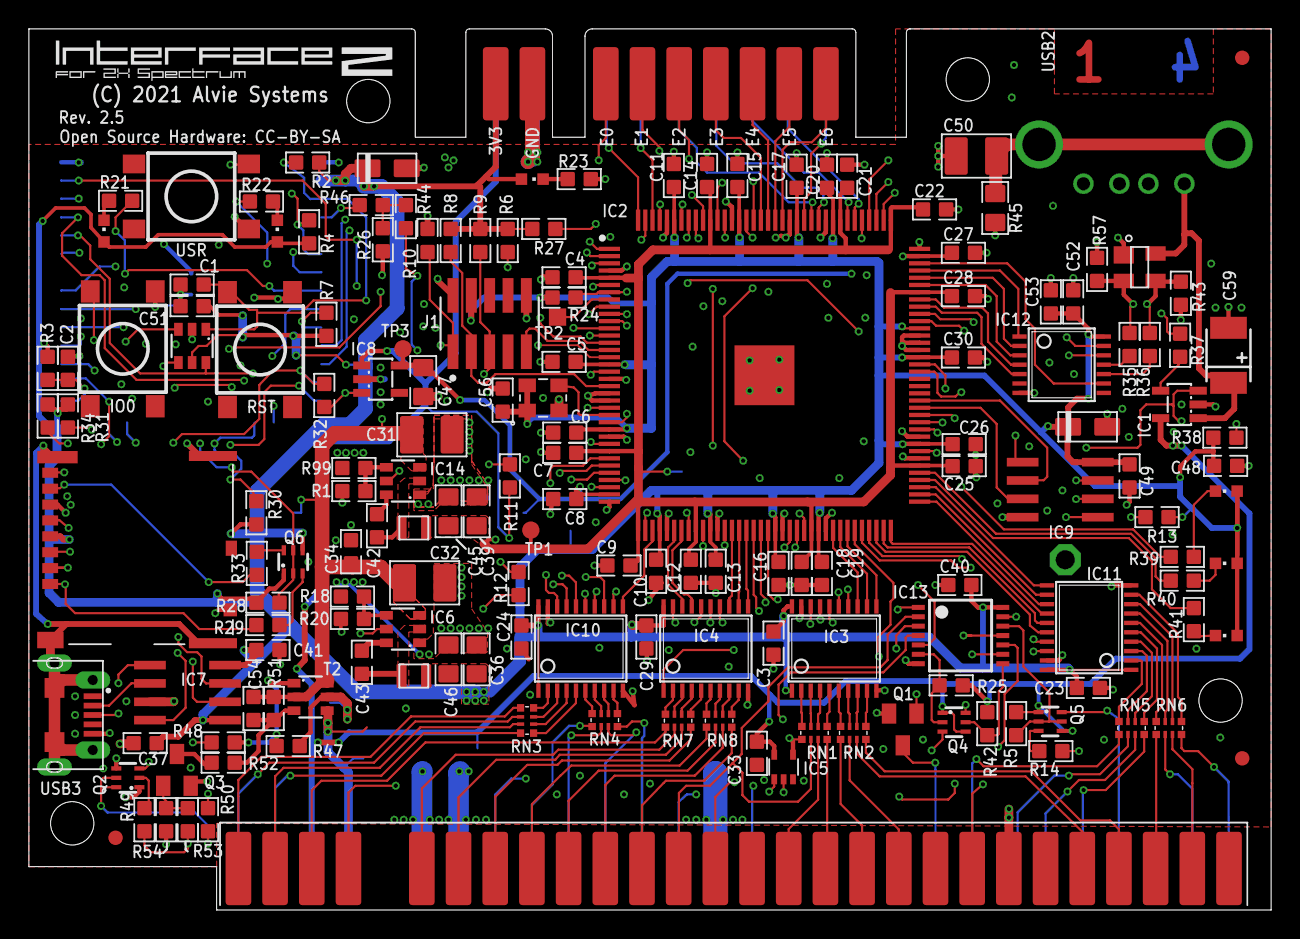
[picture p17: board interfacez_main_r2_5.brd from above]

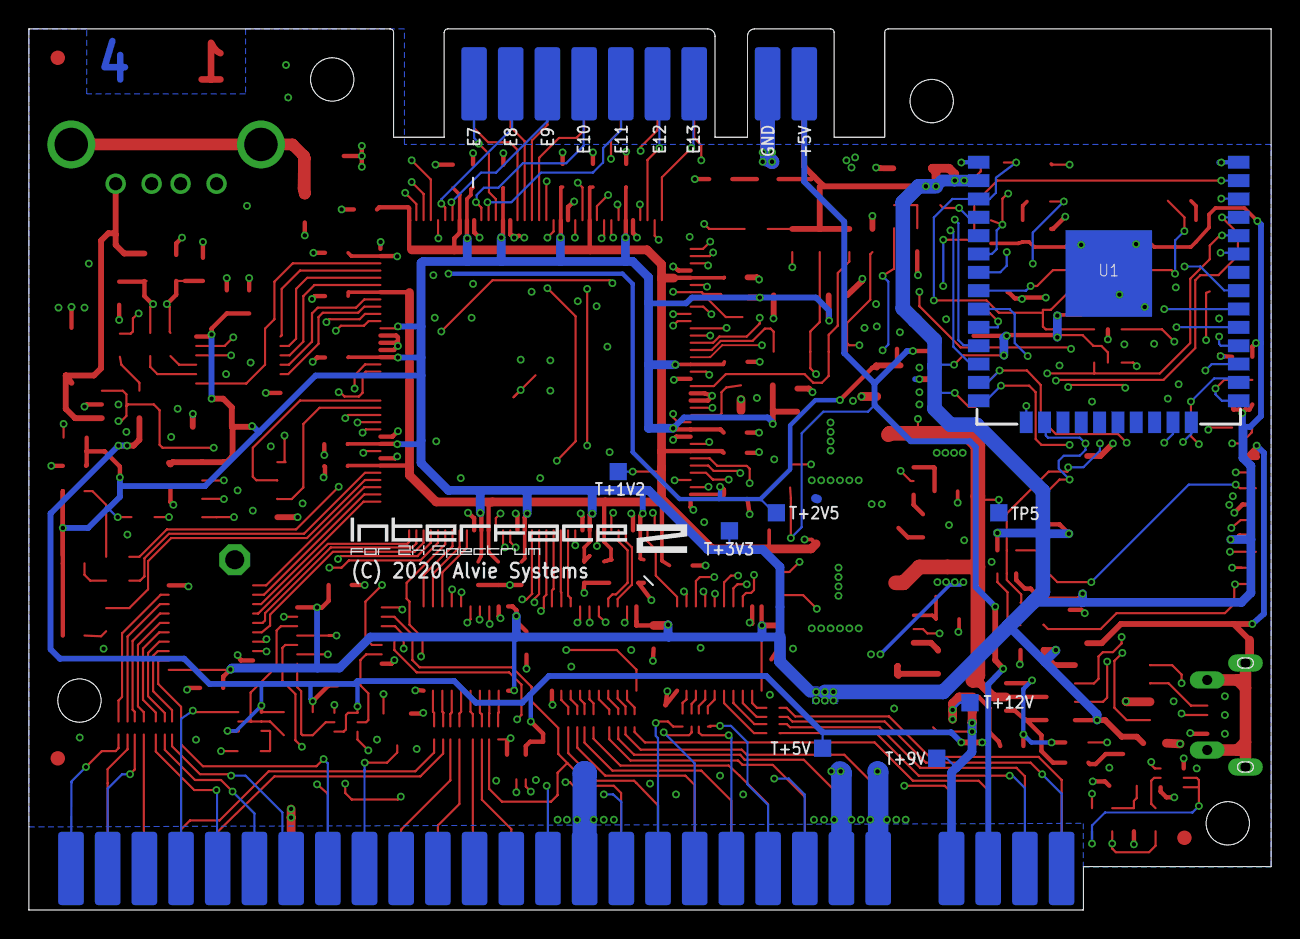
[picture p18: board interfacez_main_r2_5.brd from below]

Board: 4 copper layers, 86.0 x 61.0 mm, 171 parts (8 on the bottom side), 226 nets.

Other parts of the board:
U$6, U$8, U$9: FIDUCIAL_G10

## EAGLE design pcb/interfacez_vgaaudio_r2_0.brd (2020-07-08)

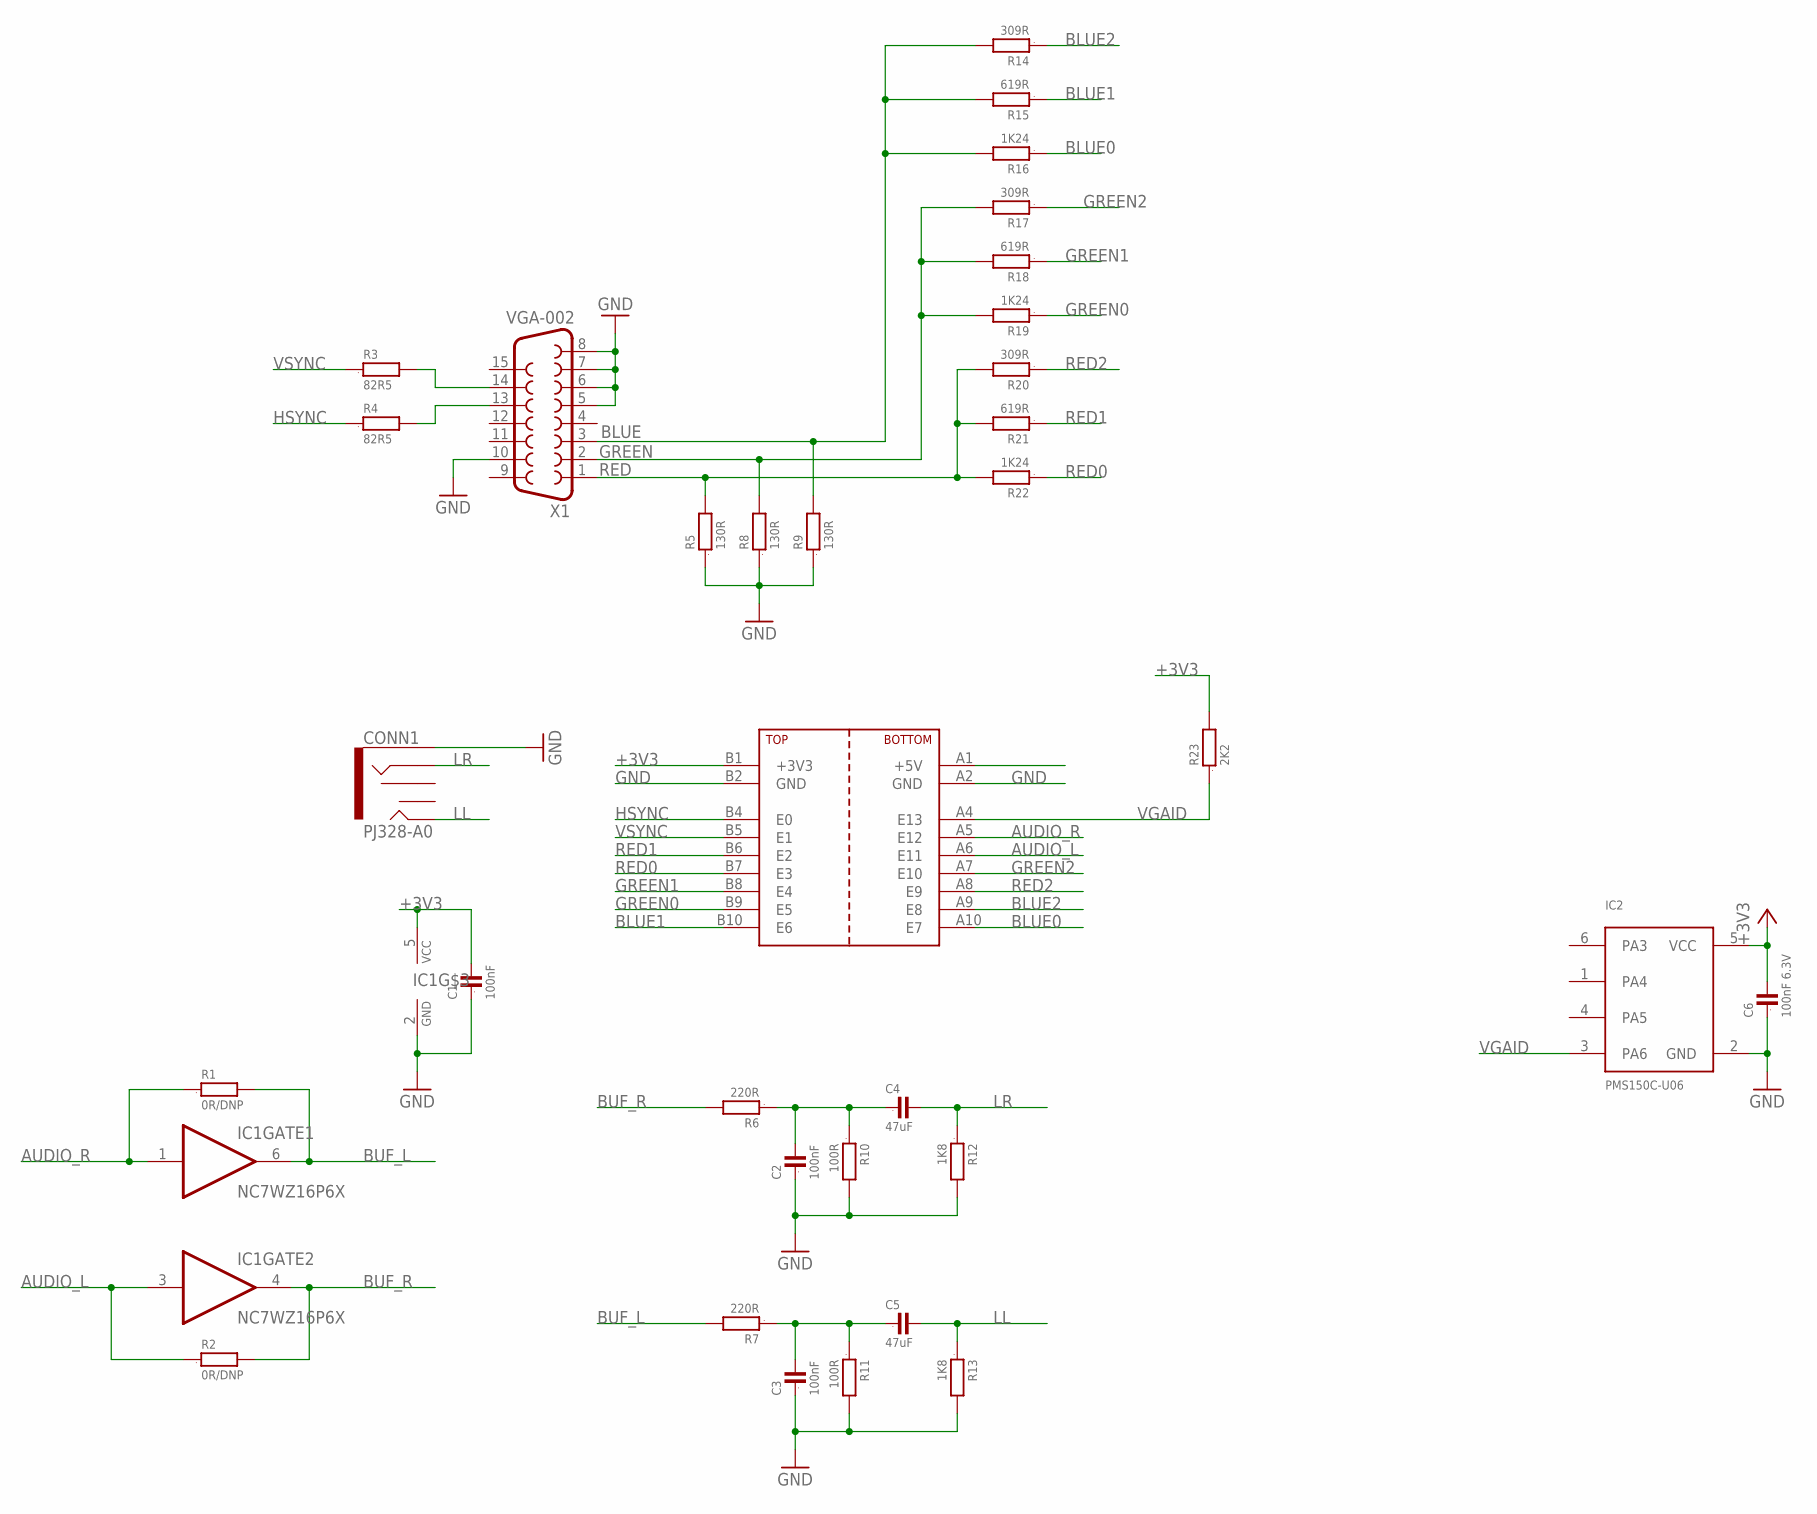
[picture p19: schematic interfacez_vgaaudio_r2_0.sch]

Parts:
C1, C2, C3: 100nF; 0603
C4, C5: 47uF; 1206
C6: 100nF 6.3V; 0603
CONN1: PJ328-A0; PJ328A0
IC1: NC7WZ16P6X; SC70-6
IC2: PMS150C-U06; SOT23-6
R1, R2: 0R/DNP; 0603
R3, R4: 82R5; 0603
R5, R8, R9: 130R; 0603
R6, R7: 220R; 0603
R10, R11: 100R; 0603
R12, R13: 1K8; 0603
R14, R17, R20: 309R; 0603
R15, R18, R21: 619R; 0603
R16, R19, R22: 1K24; 0603
R23: 2K2; 0603
U$1: INTERFACEZ_EDGEDAUGHTER; INTERFACEZ_EXPANSION_DAUGHTERCARD
X1: VGA-002; HDF15H

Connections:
+3V3: C1.2, C6.2, IC1.5 (VCC), IC2.5 (VCC), R23.2, U$1.B1 (+3V3)
AUDIO_L: IC1.3 (I), R2.1, U$1.A6 (E11)
AUDIO_R: IC1.1 (I), R1.1, U$1.A5 (E12)
BLUE: R9.2, R14.2, R15.2, R16.2, X1.3
BLUE0: R16.1, U$1.A10 (E7)
BLUE1: R15.1, U$1.B10 (E6)
BLUE2: R14.1, U$1.A9 (E8)
BUF_L: IC1.6 (O), R1.2, R7.2
BUF_R: IC1.4 (O), R2.2, R6.2
GND: C1.1, C2.1, C3.1, C6.1, CONN1.1 (SLEEVE), IC1.2 (GND), IC2.2 (GND), R5.1, R8.1, R9.1, R10.2, R11.2, R12.2, R13.2, U$1.A2 (GND), U$1.B2 (GND), X1.5, X1.6, X1.7, X1.8, X1.10
GREEN: R8.2, R17.2, R18.2, R19.2, X1.2
GREEN0: R19.1, U$1.B9 (E5)
GREEN1: R18.1, U$1.B8 (E4)
GREEN2: R17.1, U$1.A7 (E10)
HSYNC: R4.1, U$1.B4 (E0)
LL: C5.2, CONN1.2 (TIP), R13.1
LR: C4.2, CONN1.3 (RING), R12.1
unnamed: R4.2, X1.13
unnamed: R3.2, X1.14
unnamed: C3.2, C5.1, R7.1, R11.1
unnamed: C2.2, C4.1, R6.1, R10.1
RED: R5.2, R20.2, R21.2, R22.2, X1.1
RED0: R22.1, U$1.B7 (E3)
RED1: R21.1, U$1.B6 (E2)
RED2: R20.1, U$1.A8 (E9)
VGAID: IC2.3 (PA6), R23.1, U$1.A4 (E13)
VSYNC: R3.1, U$1.B5 (E1)

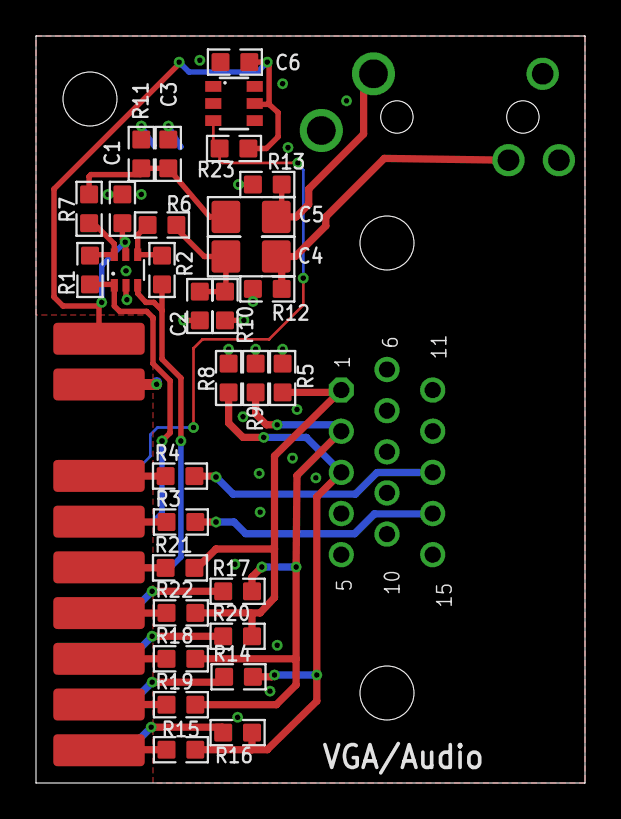
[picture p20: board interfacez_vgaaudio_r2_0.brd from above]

Board: 3 copper layers, 30.5 x 41.5 mm, 35 parts (1 on the bottom side), 27 nets.

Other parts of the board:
U$14: LOGO-23-2.65

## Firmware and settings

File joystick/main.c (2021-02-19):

/*
  ******************************************************************************
  * (C) 2021 Alvaro Lopes <alvieboy@alvie.com>
  *
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
  ******************************************************************************
  */

#include "main.h"
#include "setup.h"
#include "uart.h"
#include "defs.h"
#include "usbd.h"
#include <stdbool.h>
#include "vsnprintf.h"
#include "cpu.h"
#include "joystick.h"
#include "pin.h"
#include "array.h"

#define J1_1        MAKEPIN(PORT_B, 2)
#define J1_2        MAKEPIN(PORT_B, 11)
#define J1_3        MAKEPIN(PORT_B, 13)
#define J1_4        MAKEPIN(PORT_B, 15)
#define J1_5        MAKEPIN(PORT_A, 13)
#define J1_6        MAKEPIN(PORT_B, 10)
#define J1_7        MAKEPIN(PORT_B, 12)
#define J1_8        MAKEPIN(PORT_B, 14)
#define J1_9        MAKEPIN(PORT_A, 8)

#define J2_1        MAKEPIN(PORT_B, 5)
#define J2_2        MAKEPIN(PORT_B, 7)
#define J2_3        MAKEPIN(PORT_B, 9)
#define J2_4        MAKEPIN(PORT_A, 15)
#define J2_5        MAKEPIN(PORT_B, 4)
#define J2_6        MAKEPIN(PORT_B, 6)
#define J2_7        MAKEPIN(PORT_B, 8)
#define J2_8        MAKEPIN(PORT_A, 14)
#define J2_9        MAKEPIN(PORT_B, 3)

#define LED0        MAKEPIN(PORT_C, 15)
#define LED1        MAKEPIN(PORT_C, 14)
#define LED2        MAKEPIN(PORT_C, 13)


static const joystick_pin_conf_t joy0_pins = {
    J1_1, J1_2, J1_3, J1_4, J1_5, J1_6, J1_7, J1_8, J1_9
};

static const joystick_pin_conf_t joy1_pins = {
    J2_1, J2_2, J2_3, J2_4, J2_5, J2_6, J2_7, J2_8, J2_9
};

static joystick_pin_usage_conf_t atari_joy_conf = {
    KUP, KDOWN, KLEFT, KRIGHT, NC, KFIRE, KPOWER, KGND, KBUTTON1
};

#if 0

static joystick_pin_usage_conf_t kempston_joy_conf = {
    KUP, KDOWN, KLEFT, KRIGHT, KBUTTON2, KFIRE, KPOWER, KGND, KBUTTON1
};

static joystick_pin_usage_conf_t sjs1_joy_conf = {
    NC, KGND, NC, KFIRE, KUP, KRIGHT, KLEFT, KGND, KDOWN
};

#endif

static uint8_t report[2] = {0};
static struct joystick joysticks[2];

void tick__handler(void);


static void gpio__setup()
{
    __HAL_RCC_GPIOA_CLK_ENABLE();
    __HAL_RCC_GPIOB_CLK_ENABLE();
    __HAL_RCC_GPIOC_CLK_ENABLE();

    __HAL_RCC_USART1_CLK_DISABLE();
    __HAL_RCC_USART2_CLK_DISABLE();
    __HAL_RCC_USART3_CLK_DISABLE();
    __HAL_RCC_USART4_CLK_DISABLE();

    __HAL_RCC_SPI1_CLK_DISABLE();
    __HAL_RCC_SPI2_CLK_DISABLE();
    __HAL_RCC_I2C1_CLK_DISABLE();
    __HAL_RCC_I2C2_CLK_DISABLE();
    __HAL_RCC_CAN1_CLK_DISABLE();

    __HAL_RCC_ADC1_CLK_DISABLE();

    pin__set_output(LED0, 1);
    pin__set_output(LED1, 1);
    pin__set_output(LED2, 1);

}
void tick__handler(void)
{
}

static void tx(int id, uint8_t report_data, bool changed)
{
    uint8_t data[1];

    if (usbd__hid_get_idle()==0 && !changed)
        return;

    data[0] = report_data;

    usbd__sendreport(id, data, 1);
}



static void update_joysticks()
{
    joystick__scan_pins(&joysticks[0]);
    joystick__scan_pins(&joysticks[1]);
}

static void update_joystick_report(void *rptptr,
                                   uint8_t usage,
                                   uint8_t val)
{
    uint8_t rpt = *(uint8_t*)rptptr;

    if (val==1)
        return; // Not toggled

    switch (usage) {
    case KLEFT:
        rpt |= (0x03)<<0; // -1
        break;
    case KRIGHT:
        rpt |= (0x01)<<0; // +1
        break;
    case KUP:
        rpt |= (0x03)<<2; // -1
        break;
    case KDOWN:
        rpt |= (0x01)<<2; // +1
        break;
    case KFIRE:
        rpt |= (0x01)<<4;
        break;
    case KBUTTON1:
        rpt |= (0x01)<<5;
        break;
    case KBUTTON2:
        rpt |= (0x01)<<6;
        break;
    default:
        break;
    }

    *(uint8_t*)rptptr = rpt;
}

static bool check_joysticks(bool active[2])
{
    uint8_t new_report[2] = {0};
    bool changed[2] = {false,false};

    // Generate reports based on pin settings.
    ARRAY_FOR_EACH(index, joysticks) {

        joystick__update(&joysticks[index],
                         &update_joystick_report,
                         &new_report[index]);

    }

    ARRAY_FOR_EACH(index, joysticks) {
        if (report[index]!= new_report[index]) {
            report[index] = new_report[index];
            changed[index] = true;
        }
    }
    tx(0, report[0], changed[0]);
    tx(1, report[1], changed[1]);

    // Update active
    active[0] = (report[0]!=0);
    active[1] = (report[1]!=0);

    return true;
}

#include "timer.h"

static TimerEvent_t ledTimer;
static TimerEvent_t joystickTimer;

static void ledtimer_callback(void *user)
{
    static int led = 0;
    led = !led;
    pin__write(LED0, led);
}

static void joysticktimer_callback(void*user)
{
    bool active[2];
    check_joysticks(active);

    pin__write(LED1, !active[0]);
    pin__write(LED2, !active[1]);
}

int main()
{
    clk__setup();
    SystemCoreClockUpdate();
    HAL_Init();
    gpio__setup();

    joystick__init(&joysticks[0], &joy0_pins);
    joystick__init(&joysticks[1], &joy1_pins);

    joystick__set_usage(&joysticks[0], &atari_joy_conf);
    joystick__set_usage(&joysticks[1], &atari_joy_conf);

//    pin__set_input(MAKEPIN(PORT_A,15));
    usbd__init();


    TimerInit( &ledTimer, &ledtimer_callback, NULL);
    TimerSetPersistent( &ledTimer, 1);
    TimerSetValue( &ledTimer, 500);
    TimerStart( &ledTimer );

    TimerInit( &joystickTimer, &joysticktimer_callback, NULL);
    TimerSetPersistent( &joystickTimer, 1);
    TimerSetValue( &joystickTimer, 10);
    TimerStart( &joystickTimer );

    __enable_irq();


    while (1)
    {
        TimerLoop();

        update_joysticks();

        unsigned t = HAL_GetTick();
        while (t==HAL_GetTick()) {
            cpu__wait();
        }
    }
}

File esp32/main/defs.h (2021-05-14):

#ifndef __DEFS_H__
#define __DEFS_H__

/**
 * \defgroup misc Miscelaneous
 * \brief Miscelaneous routines and modules
 *
 * \defgroup tools Tools and utilities
 * \brief Tools and utilities
 *
 * \defgroup init System initialization
 * \brief System initialization
 */

#define PIN_NUM_IO26 26
#define PIN_NUM_IO21 21
#define PIN_NUM_IO22 22
#define PIN_NUM_IO27 27
#define PIN_NUM_IO0  0
#define PIN_NUM_MISO 19
#define PIN_NUM_MOSI 23
#define PIN_NUM_CLK  18

//#define PIN_NUM_QWP  22
//#define PIN_NUM_QHD  21
#define PIN_NUM_CS   5
#define PIN_NUM_CS2  PIN_NUM_IO22


#define SDMMC_PIN_D0 2
#define SDMMC_PIN_D1 4
#define SDMMC_PIN_D2  12
#define SDMMC_PIN_D3  13
#define SDMMC_PIN_CLK 14
#define SDMMC_PIN_CMD 15
//#define SDMMC_PIN_DET 15


#define PIN_NUM_LED1 32
#define PIN_NUM_PULLUP_EN 33


#define PIN_NUM_SWITCH 34


// FPGA-configuration pins
#define PIN_NUM_CONF_DONE 35 
#define PIN_NUM_NCONFIG 25
#define PIN_NUM_NSTATUS 16

#define PIN_NUM_CMD_INTERRUPT PIN_NUM_IO27

#define PIN_NUM_SPECT_INTERRUPT PIN_NUM_IO26
#define PIN_NUM_INTACK        PIN_NUM_IO21

#define SPECTRUM_FRAME_SIZE (0x1b00)


#define CMD_PORT 8002
#define BUFFER_PORT 8003

#define INTERFACEZ_MAX_FILES_PER_MOUNT 2

void request_restart(void);

#ifndef __linux__
#include <esp_heap_caps.h>
#define HEAPCHECK(xpto...) do { \
    if (!heap_caps_check_integrity(0xffffffff, true)) { \
    ESP_LOGE("HEAP","Heap check fail %s line %d", __PRETTY_FUNCTION__, __LINE__); \
    abort(); \
    } \
} while (0)
#else
#define HEAPCHECK(x...)

#endif


#endif

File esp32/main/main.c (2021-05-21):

/**
 * \defgroup startup Startup routines
 * \brief Starting up the system
 */

#include "spi.h"
#include "fpga.h"
#include "flash_pgm.h"
#include "dump.h"
#include "command.h"
#include "ota.h"
#include "fpga_ota.h"
#include "sna.h"
#include "res.h"
#include "strtoint.h"
#include "netcomms.h"
#include "spectcmd.h"
#include "wifi.h"
#include "led.h"
#include "onchip_nvs.h"
#include "gpio.h"
#include "interfacez_resources.h"
#include "spectint.h"
#include "videostreamer.h"
#include "netcmd.h"
#include "sdcard.h"
#include "tapeplayer.h"
#include "rom.h"
#include "usbh.h"
#include "usb_ll.h"
#include <esp32/rom/uart.h>
#include "keyboard.h"
#include "webserver.h"
#include "config.h"
#include "os/task.h"
#include "devmap.h"
#include "audio.h"
#include "console.h"
#include "version.h"
#include "buttons.h"
#include "vga.h"
#include "memlayout.h"
#include "wsys.h"
#include "memlayout.h"
#include "adc.h"
#include "board.h"
#include "bit.h"
#include "hdlc_decoder.h"
#include "scope.h"
#include "model.h"
#include "divcompat.h"
#include "rom_hook.h"
#include "storage.h"
#include "activity_monitor.h"
#include "tape.h"
#include "kempston.h"
#include "fasttap.h"
#include "log.h"
#include "reset.h"
#include <driver/periph_ctrl.h>

#define TAG "MAIN"

static int8_t videomode = 0;

uint32_t loglevel = 0;

volatile int restart_requested = 0;
static volatile uint8_t spectrum_model = 0xff;
static volatile uint8_t spectrum_flags = 0x00;

static void detect_spectrum(void);
/**
 * \ingroup startup
 * \brief Request ZX Interface Z restart
 *
 * Request ZX Interface Z to be restarted. This will take place once possible
 */
void request_restart(void)
{
    restart_requested = 1;
}

static void io0_long_press()
{
    char romname[128];

    if (nvs__fetch_str("io0rom", romname, sizeof(romname), "/spiffs/DiagROMv54.rom")<0) {
        ESP_LOGE(TAG, "Cannot fetch rom for IO0");
        return ;
    }
    ESP_LOGI(TAG, "Loading ROM %s", romname);

    int f = rom__load_custom_from_file(romname, MEMLAYOUT_ROM2_BASEADDRESS);
    if (f<0) {
        ESP_LOGE(TAG, "Cannot load ROM %s", romname);
        return;
    }

    ESP_LOGI(TAG, "Resetting to custom ROM");
    if (reset__reset_to_custom_rom(ROM_2, 0x00, false)<0) {
        ESP_LOGE(TAG, "Cannot reset");
    }
}

static void load_esxdos()
{
    const char *romname = "/spiffs/esxdos2.rom";
    int f = rom__load_custom_from_file(romname, MEMLAYOUT_ROM1_BASEADDRESS);
    if (f<0) {
        ESP_LOGE(TAG, "Cannot load ROM %s", romname);
        return;
    }

    divcompat__enable(0); // 48K only for now

    ESP_LOGI(TAG, "Resetting to custom ROM");
    if (reset__reset_to_custom_rom(ROM_1, 0x00, false)<0) {
        ESP_LOGE(TAG, "Cannot reset");
    }
}

static void enter_nmi()
{
    wsys__reset(WSYS_MODE_NMI);
    // Forcibly stop tape.
    tapeplayer__stop();
    fpga__write_miscctrl(0x00); // Regular NMI handling (i.e., ends with RETN). This notifies the ROM firmware
    fpga__set_trigger(FPGA_FLAG_TRIG_FORCENMI_ON);
}

static void event_button_switch(button_event_type_e type)
{
    if (type==BUTTON_RELEASED) { // || type==BUTTON_LONG_RELEASED) {
        ESP_LOGI(TAG, "Requesting NMI!");
        enter_nmi();
    } else if (type==BUTTON_LONG_PRESSED) {
        ESP_LOGI(TAG, "Loading ESXDOS");
        load_esxdos();
    }
}

static void event_button_io0(button_event_type_e type)
{
    if (type==BUTTON_RELEASED || type==BUTTON_LONG_RELEASED) {
        ESP_LOGI(TAG, "IO0 released");
    }
    if (type==BUTTON_PRESSED) {
        ESP_LOGI(TAG, "IO0 pressed");
        //detect_spectrum();
    }
    if (type==BUTTON_LONG_PRESSED) {
        ESP_LOGI(TAG, "IO0 long pressed");
        io0_long_press();
    }
}

static void process_buttons()
{
    button_event_t event;
    if (buttons__getevent(&event, false)==0) {
        switch (event.button) {
        case BUTTON_SWITCH:
            event_button_switch(event.type);
            break;
        case BUTTON_IO0:
            event_button_io0(event.type);
        }
    }
}

void spectrum_model_detected(uint8_t model, uint8_t flags)
{
    spectrum_model = model;
    spectrum_flags = flags;
}

const char *spectrum_model_str(uint8_t model)
{
    const char *modelstr = "Unknown";
    switch (model) {
    case 0xfe:
        modelstr = "Unknown (detection error)";
        break;
    case 0x00:
        modelstr = "16/48K";
        break;
    case 0x01:
        if (board__is9Vsupply()) {
            modelstr = "+2(128K)";
        } else if (board__isplus2plus3supply()) {
            modelstr = "+2A,+3";
        } else {
            modelstr = "+2(128K),+2A,+3";
        }
        break;
    }
    return modelstr;
}

const char *get_spectrum_model(void)
{
    return spectrum_model_str(spectrum_model);
}

static uint32_t shift_lfsr(uint32_t data, const uint32_t xorpat)
{
    uint32_t shifted = data>>1;
    if (data&1) {
        shifted ^= xorpat;
    }
    return shifted;
}

static bool extram_test(bool simple_test)
{
    // 16MB. with 256-byte chunks, it gives 65536 iterations. 2080 bits for each row.
    // Takes about 30 seconds to test all RAM at 10Mbit/s.
#ifdef __linux__
    const unsigned topram = 0x00080000;
#else
    const unsigned topram = 0x00800000;
#endif

#ifdef __linux__
    return true;
#endif


    if (simple_test)
    {
        union {
            uint32_t u32;
            uint8_t u8[4];
        } pat, readback;

        unsigned address = 0;
        pat.u32 = 0xDEADBEEF;
        const uint32_t xorpat = (1<<31) | (1<<21) | (1<<1) | (1<<0);

        ESP_LOGI(TAG, "Testing external RAM (simple)");


        while (address < topram) {
            //ESP_LOGI(TAG, "Write %08x value=%08x", address, pat.u32);
            fpga__write_extram_block(address, &pat.u8[0], sizeof(pat.u8));
            pat.u32 = shift_lfsr(pat.u32, xorpat);
            address += 0x1000;
        }

        // Read back
        pat.u32 = 0xDEADBEEF;
        address = 0;
        while (address < topram) {
            readback.u32 = 0;
            fpga__read_extram_block(address, &readback.u32, sizeof(readback.u32));
            if (readback.u32 != pat.u32) {
                ESP_LOGE(TAG, "Read error at address %08x: expected %08x, got %08x",
                         address,
                         pat.u32,
                         readback.u32);
                return false;
            }
            pat.u32= shift_lfsr(pat.u32, xorpat);
            address += 0x1000;
        }
        ESP_LOGI(TAG, "External RAM test (simple) passed");
        return true;
    }
    return false;
}

#define SPECTRUM_FLAGS_AY (1<<0)
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

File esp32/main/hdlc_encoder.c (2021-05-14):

#include "hdlc_encoder.h"
#include <stdlib.h>

#define HDLC_FRAME_FLAG 0x7E
#define HDLC_ESCAPE_FLAG 0x7D
#define HDLC_ESCAPE_XOR 0x20

static void hdlc_encoder__update_crc(hdlc_encoder_t *hdlc, uint8_t data)
{
    data ^= hdlc->crc&0xff;
    data ^= data << 4;
    hdlc->crc = ((((uint16_t)data << 8) | ((hdlc->crc>>8)&0xff)) ^ (uint8_t)(data >> 4)
                 ^ ((uint16_t)data << 3));
}


int hdlc_encoder__init(hdlc_encoder_t *hdlc, void (*writer)(void*,const uint8_t c), void (*flusher)(void*), void*userdata)
{
    hdlc->writer = writer;
    hdlc->flusher = flusher;
    hdlc->userdata = userdata;
    return 0;
}

int hdlc_encoder__begin(hdlc_encoder_t *hdlc)
{
    hdlc->crc = 0xFFFF;
    hdlc->writer(hdlc->userdata, HDLC_FRAME_FLAG);
    return 1;
}

int hdlc_encoder__write(hdlc_encoder_t *hdlc, const void *udata, unsigned datalen)
{
    int c = 0;
    const uint8_t *data = (const uint8_t*)udata;
    while (datalen--) {
        hdlc_encoder__update_crc(hdlc, *data);
        if ((*data==HDLC_FRAME_FLAG) || (*data==HDLC_ESCAPE_FLAG)) {
            hdlc->writer(hdlc->userdata, HDLC_ESCAPE_FLAG);
            hdlc->writer(hdlc->userdata, *data ^ HDLC_ESCAPE_XOR);
            c+=2;
        } else {
            hdlc->writer(hdlc->userdata, *data);
            c++;
        }
        data++;
    }
    return c;
}

int hdlc_encoder__end(hdlc_encoder_t *hdlc)
{
    int r;
    uint8_t c[2];

    c[0] = hdlc->crc & 0xff;
    c[1] = hdlc->crc >> 8;

    r = hdlc_encoder__write(hdlc, c, sizeof(c));
    hdlc->writer(hdlc->userdata, HDLC_FRAME_FLAG);
    if (hdlc->flusher!=NULL)
        hdlc->flusher(hdlc->userdata);
    r++;
    return r;
}






uint8_t* hdlc_encoder__begin_mem(hdlc_encoder_t *hdlc, uint8_t *target)
{
    hdlc->crc = 0xFFFF;
    *target++ = HDLC_FRAME_FLAG;
    return target;
}

uint8_t *hdlc_encoder__write_mem(hdlc_encoder_t *hdlc, const uint8_t *data, unsigned datalen, uint8_t *target)
{
    while (datalen--) {
        hdlc_encoder__update_crc(hdlc, *data);
        if ((*data==HDLC_FRAME_FLAG) || (*data==HDLC_ESCAPE_FLAG)) {
            *target++ = HDLC_ESCAPE_FLAG;
            *target++ = *data ^ HDLC_ESCAPE_XOR;
        } else {
            *target++ = *data;
        }
        data++;
    }
    return target;
}

uint8_t *hdlc_encoder__write_mem_byte(hdlc_encoder_t *hdlc, const uint8_t data, uint8_t *target)
{
    hdlc_encoder__update_crc(hdlc, data);
    if ((data==HDLC_FRAME_FLAG) || (data==HDLC_ESCAPE_FLAG)) {
        *target++ = HDLC_ESCAPE_FLAG;
        *target++ = data ^ HDLC_ESCAPE_XOR;
    } else {
        *target++ = data;
    }
    return target;
}

uint8_t *hdlc_encoder__end_mem(hdlc_encoder_t *hdlc, uint8_t *target)
{
    uint8_t c[2];

    c[0] = hdlc->crc & 0xff;
    c[1] = hdlc->crc >> 8;

    target = hdlc_encoder__write_mem(hdlc, c, sizeof(c), target);
    *target++=HDLC_FRAME_FLAG;
    return target;
}

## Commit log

2020-02-20 add rev1 PCB
    [interfacez.sch]
2020-02-20 Fix sch+brd
    [interfacez_r1.brd, interfacez_r1.sch]
2020-02-28 Sync - base stuff working
    [interfacez_r1.brd, interfacez_r1.sch]
2020-03-06 Preliminary version for SNA loading
    [interfacez_r2.brd, interfacez_r2.sch]
2020-03-08 Preparing for SNA
    [interfacez_r1.brd, interfacez_r2.brd, interfacez_r2.sch]
2020-03-12 Sync - working version with SNAs
    [interfacez_r2.brd, interfacez_r2.sch]
2020-03-24 Sync r2/r2.1
    [interfacez_r2_1.brd, interfacez_r2_1.sch]
2020-04-26 Fix crashes, add videomode conf
    [main.c]
2020-04-26 Fix resistor value
    [interfacez_r2_1.brd, interfacez_r2_1.sch]
2020-05-22 USB layer and cleanups
    [interfacez_r2_1.sch]
2020-05-24 Add address analysis, relates to #5
    [address_analysis.xlsx]
2020-05-25 In order to support Kempston mouse, addresses, address updated to A0=1, A1=1, A5=1, A7=0. This changes decoding bit from A6 to A5. Update #5
    [address_analysis.xlsx]
2020-05-28 rstgen: use additional reset stage
2020-05-28 Added README with instructions for building ROMs
    And instruction for how to build Pasmo - the Z80 assembler
2020-05-29 USB: add filter for low-speed devices
2020-05-31 Add rev 2.2
    [interfacez_r2_2.brd, interfacez_r2_2.sch]
2020-06-01 PCB 2.2 updates
    [interfacez_r2_2.brd, interfacez_r2_2.sch]
2020-06-05 Add new DPLL and filtering
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2020-06-07 New board layout
    [interfacez_r2_2.brd, interfacez_r2_2.sch]
2020-06-07 USB fixes, keyboard and ULA hack
    [main.c]
2020-06-07 r2.2 updates
    [interfacez_r2_2.brd, interfacez_r2_2.sch]
2020-06-11 Host-mode fixes and partitions
    [main.c]
2020-06-11 Missing partition table
    [ptable.csv]
2020-06-11 Rev 2.2 for board
    [interfacez_r2_2.brd, interfacez_r2_2.sch]
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2020-06-11 Move ports around in order to fix #5
    [address_analysis.xlsx]
2020-06-19 New tape structure
    [interfacez_r2_2.brd, interfacez_r2_2.sch]
2020-06-25 Fix paths and files
    [main.c]
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2020-06-25 Cosmetic changes
    [interfacez_r2_2.sch]
2020-07-01 Fix USB suspend pin
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2020-07-03 Fix signal naming
    [interfacez_r2_2.brd, interfacez_r2_2.sch]
2020-07-03 Move VGA into own files
    [interfacez_vgaaudio_r2_0.brd, interfacez_vgaaudio_r2_0.sch]
2020-07-08 Update PCBs
    [interfacez_vgaaudio_r2_0.brd, interfacez_vgaaudio_r2_0.sch]
2020-07-09 Add debug, fix SPI address
    [spi_master.c]
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2020-08-07 New architecture changes
    [interfacez_r2_2.brd]
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2020-08-12 Fix ROM loading and GPIO manipulation in ISR
    [main.c]
2020-08-13 Fix GPIO for future use
    [gpio.c]
2020-08-14 Downcase intz.rom and adjust the ESP32 path for sourcing the intz.rom
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2020-08-15 Fix button reporting for emulation
    [main.c]
2020-08-15 Default to 0xFF IO read when devices disabled
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2020-09-05 Add BOM
    [interfacez_BOM_r2_2.csv]
2020-09-10 Fix debug and socket leak
2020-09-19 Add r2.3 PCB and gerbers
    [interfacez_main_r2_3.brd, interfacez_main_r2_3.sch]
2020-09-29 Move FPGA and ROM into spiffs
    [ptable.csv]
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2020-09-30 Fix build and nvs
    [main.c]
2020-09-30 Fix load from spiffs
    [main.c]
2020-10-12 Fix wifi restart and add spectrum detection
    [main.c]
2020-10-14 HW: allow ROMCS to switch only and only at start of M1 cycle
2020-10-14 More WiFi fixes, and spectrum detection
    [main.c]
2020-10-15 Add stack trace information on linux for memory leaks
2020-10-15 Fix inclusion of execinfo in ESP32
2020-10-17 Add spacing support for buttons, add configurable key trigger
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2020-10-17 Add ADC support to read main voltage rail
2020-10-23 FPGA: move files into subdirectory, split versions
    [clockmux.csv]
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2020-11-28 WIP: Angular web UI (#50)
    * Initial Angular 10 webapp
    * Remove default instructions
    * Added Angular Material and created a MaterialModule
    * Created a basic toolbar
    * Change the stock favicon to If Z
    * Added dummy components and initial routing
    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
2020-12-03 Misc fixes all around
    [main.c]
2020-12-08 Temp snaphshot
    [interfacez_main_r2_4.brd, interfacez_main_r2_4.sch]
2020-12-08 WAIT: fix WAIT line de-assertion, otherwise we might miss opcodes
2020-12-08 Add r2.4 mainboard files
    [interfacez_main_r2_4.brd, interfacez_main_r2_4.sch]
2020-12-08 +2A/+3: fix reset duration, detection (for r2.4) and increase interrupt queue
    [board.c, gpio.c, main.c]
2020-12-09 host: fix task usage and priority
    [main.c]
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2020-12-19 fpga: add ROM hook control and interrupt management
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2020-12-19 usb: fix interrupt for new infrastructure
2020-12-19 fpga: new interrupt structure and ROM hook fixes
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2020-12-21 main: cleanups and USB enable at power on
2020-12-21 spi: fix addressing space due to ROM hook changes
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2020-12-24 spi: gracefully handle SPI deselection, if we are still processing an AHB request
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2021-01-05 spiffs: allow de-intialisation in order to reprogram spiffs
2021-01-05 wsys: add entry mode wsys: de-bounce keyboard on menu entry
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2021-01-07 host: go back to socket approach, add USB listings
2021-01-17 USB: use new TX PHY for proper FS/LS switch
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2021-01-17 buttons: fix queue parameter
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2021-01-18 usbhubdev: be more silent, and stop timer before disconnect
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2021-01-24 devmap: fix lockup on device search
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2021-02-16 main: don't register directory resource and use reset module for spectrum reset
    [main.c]
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2021-02-16 core: add delete() for ESP32, add stringn routines.
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2021-02-16 filelistmenu: update filters and use system event notification
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2021-02-16 frame: fix title and draw
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2021-02-16 nmimenu: use new file filters and use proper module for reset
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2021-03-12 spi: use VSPI for communication, so we can use IOMUX pins
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2021-03-12 gpio: remove now unused dedicated USB interrupt pin
2021-03-12 interrupt: fix interrupt handling
    [defs.h]
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2021-03-12 pcb: fix R44 value for voltage divider
    [interfacez_main_r2_4.brd]
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2021-03-13 widget: fix brackets
2021-03-14 fpga: fix bit index for kempston second joystick button
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2021-03-14 save: notify save to reset timer
2021-03-17 hook: fix pre-hook assertion of ROMCS, currently it waits for a second M1 pulse, which is not what is intended.
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2021-03-19 usbhubdev: align buffer to avoid DMA reallocations
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2021-03-21 main: minor fixes for loglevel and some optional memory debugging
    [main.c]
2021-03-21 usbhub: Fix allocation for device descriptor, since SPI buffers are required to be 32-bit multiples due to DMA.
2021-03-21 videostreamer: do not spend time processing framebuffer if we don't have any client
2021-03-21 esp32: disable bluetooth for now since we don't actually use it
2021-03-21 fpga: add support for generating 3.555MHz clock on expansion connector
2021-03-21 devmap: debug field if we cannot find a driver
2021-03-21 config: increase mountpoints, decrease wear levelling sector size
2021-03-21 fpga: make reads via SPI always 32-bit aligned and 32-bit sized
2021-04-05 pcb: preliminary r2.5
    [interfacez_main_r2_5.brd, interfacez_main_r2_5.sch]
2021-04-05 #72, #77: Remove useless code, fix interrupt handing, add RST$08 handler, add ROM switch for 128K mode so we inject keys
2021-04-06 firmware: increase timeout value for task watchdog, currently it seems to be trigering inside ipc0 task, which is internal to ESP32
2021-04-06 makefile: add target to clean NVS from ESP32
2021-04-21 #72: add missing prototype for closing directory entries
2021-04-21 #76: move reset into a separate module
    [main.c]
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2021-04-28 #81: restore interrupts correctly when we are on NMI. EI and DI modify the IFF2 which is required for proper operation of RETN, which causes (as of now) interrupts to be disabled when NMI is exited.
2021-04-28 pcb: update rev 2.5
    [interfacez_main_r2_5.brd, interfacez_main_r2_5.sch]
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2021-05-14 #86, #85: add board OS layer, add fallback image for firmware update
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2021-05-14 hdlc_encoder: fix frame size parameter
    [hdlc_encoder.c]
2021-05-14 spi: add local debug tag, simplify locking mechanism
2021-05-14 #86: update interrupt handling to use new OS layer
2021-05-14 #85: add fallback partition
    [ptable.csv]
2021-05-15 host: fix interrupt locking and video commands
2021-05-21 fpga: print out FPGA image name on error
2021-05-21 main: reset WiFI on startup, sometimes it does not come up after a crash
    [main.c]
2021-05-21 #85: always mount in /spiffs, even recovery mode filesystem
2021-06-05 usbh: add missing prototype
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2021-06-05 #92: capture IM instructions so we know the interrupt mode
2021-07-09 Webapp: Upgraded to Angular an Angular Material 11.0
2021-07-09 Webapp: Upgraded to Angular an Angular Material 12.1.1
2021-07-16 Webapp: Fix button types
2021-07-19 Fix CI so esp32 depends on roms

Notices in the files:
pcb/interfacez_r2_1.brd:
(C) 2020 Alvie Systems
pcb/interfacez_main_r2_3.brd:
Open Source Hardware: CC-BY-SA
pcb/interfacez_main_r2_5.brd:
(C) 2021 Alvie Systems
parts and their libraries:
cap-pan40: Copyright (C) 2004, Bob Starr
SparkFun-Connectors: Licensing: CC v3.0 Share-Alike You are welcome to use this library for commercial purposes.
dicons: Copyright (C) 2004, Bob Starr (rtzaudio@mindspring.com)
